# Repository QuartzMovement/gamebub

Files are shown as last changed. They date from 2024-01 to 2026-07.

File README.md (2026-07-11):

<p align="center">
  <a href="https://gamebub.net/">
    Game Bub logo
  </a>
</p>

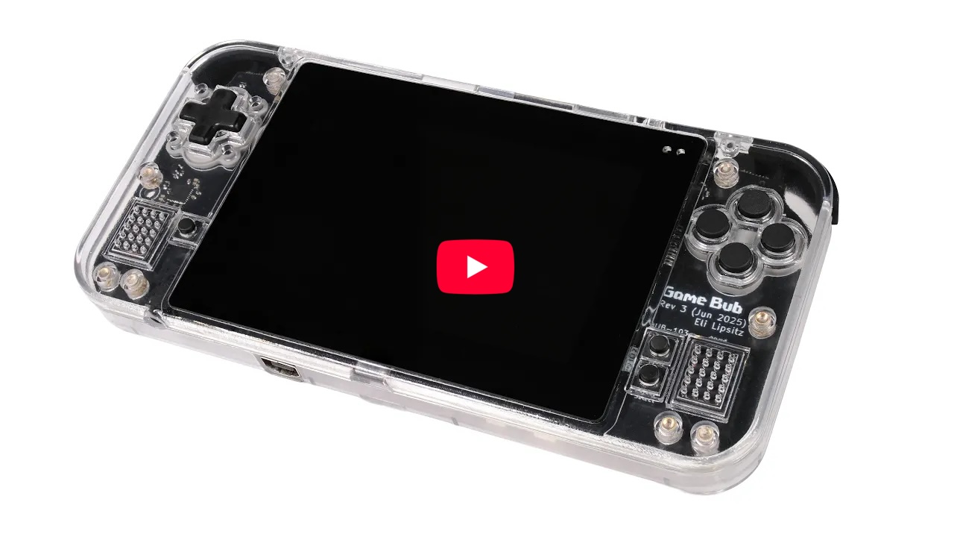
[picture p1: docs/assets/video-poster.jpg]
Game Bub trailer (https://www.youtube.com/watch?v=f16E5J6qljw)


**Game Bub** is an open-source FPGA retro emulation handheld, with support for Game Boy, Game Boy Color, and Game Boy Advance games.

You can buy your own, prebuilt Game Bub from **[Crowd Supply](https://www.crowdsupply.com/second-bedroom/game-bub)**!

You can find the [user guide and documentation here](https://docs.gamebub.net/).

Want to chat about Game Bub? Feel free to [join the Discord](https://discord.gg/T5xrYpMfN7).

Check out the [announcement blog post](https://eli.lipsitz.net/posts/introducing-gamebub/) for an in-depth look at the development process!

## Features
* Play physical Game Boy / Color / Advance cartridges
* Load and play ROM files from a microSD card (with built-in support for rumble, clock, accelerometer, gyroscope)
* Multiplayer link cable functionality
* Custom, from-scratch Game Boy and Game Boy Advance FPGA cores with great game compatibility
* 14+ hour battery life 
* Video output to TV or monitor via Game Bub Dock
* Extensible hardware, designed for future improvements

## Building

Building a Game Bub handheld requires manufacturing PCBs, 3D printing the shell and buttons, and assembling components from a variety of sources. For information on manufacturing and assembling your own, see [docs/building.md](docs/building.md).

For other inquiries, contact us at support@gamebub.net.

## Architecture

For an in-depth description of the project architecture, see [docs/architecture.md](docs/architecture.md).

The Game Bub handheld consists of a Xilinx XC7A100T FPGA to do the main emulation and I/O, and an ESP32-S3 microcontroller to do auxiliary tasks (configuring the FPGA, rendering the UI, loading ROM files from a microSD card and sending it to the FPGA).

### Directory Structure

* `fpga`: FPGA source code (HDL), written in [Chisel](https://github.com/chipsalliance/chisel)
* `firmware`: Microcontroller firmware

## License

Unless otherwise specified:

* Firmware (in `firmware/`) and scripts (in `scripts/`) are licensed under GPLv3 (`GPL-3.0-only`).
* FPGA source code (in `fpga/`) is licensed under the CERN Open Hardware License Version 2 - Strongly Reciprocal (`CERN-OHL-S-2.0`)
* PCB (schematic and layout), mechanical, and hardware design files are licensed under the CERN Open Hardware License Version 2 - Strongly Reciprocal (`CERN-OHL-S-2.0`)

At a high level, this means that you can copy, share, and modify the source code, as long as you provide proper attribution and share your source code / design files with the same license. However, the "Game Bub" name and logo are trademarked, and you may not use them for your product without permission.

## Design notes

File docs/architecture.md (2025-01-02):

# Architecture

The physical architecture of the Game Bub handheld is summarized in the following block diagram.

See the [schematic](../pcb/handheld_rev2/handheld.pdf) for more information.

<p align="center">
     
</p>

## Power 

The device is split into three power domains:

* **Always on**: real-time clock, battery charger, battery gauge, and the power switch circuit.
    * `VBATT` (directly from the battery, 3.7V to 4.2V)
    * `VSYS_ALWAYS` (from the BQ24073 charger)
* **MCU**: Powers the MCU, its peripherals, and the display. Pressing the power switch powers on this power domain.
    * `VSYS` (~3.7V to 5.0V), from `VSYS_ALWAYS` through a load switch
    * `+3V3` (3.3V), generated by a TLV62585 buck converter from `VSYS`
* **FPGA**: Controlled by the `FPGA_ENABLE` signal from the MCU. Powers the FPGA and its peripherals. Also powers the DAC digital and analog core voltages (but the IO rails are powered as part of the MCU power domain).
    * `+1V0` (1.0V), generated by a TLV62585 buck converter from `VSYS`
    * `+5V0` (5.0V), generated by a TPS61022 boost converter from `VSYS`
    * `+1V8` (1.8V), generated by a TPS61022 boost converter from `VSYS`
    * `+3V3_FPGA` (3.3V), gated by a load switch from `+3V3`
    * `VGB` (3.3V or 5.0V), muxed from `+3V3_FPGA` or `+5V0` depending on whether there is a Game Boy (5V) or Game Boy Advance (3.3V) cartridge present. This muxing is controlled by the FPGA, and this is used to power the cartridge, link port, and the level shifters.

The FPGA requires careful power sequencing: `FPGA_ENABLE` enables `+1V0` and `+5V0`. `+1V8` is enabled once `+1V0` stabilizes, and `+3V3_FPGA` is enabled once that stabilizes.

## MCU and FPGA Responsibilities

The MCU is responsible for system control: it boots the device and manages the FPGA (power and configuration). It also renders the UI (sending completed frames over the FPGA for display).

The FPGA does all game emulation. It has direct access to the cartridge slot and link ports, and has dedicated memory (32 MiB of SDRAM, 512 KiB of SRAM) to assist with this. It produces audio and sends it to the DAC via I2S, and it has a high-bandwidth 18-bit parallel interface to the display. 

The FPGA also has 4 high-speed differential pairs routed out to the USB-C connector. This is used, with the custom dock in a vendor-specific alt mode, to output HDMI audio and video (directly from the FPGA). 

The high-speed QSPI link between the MCU and the FPGA (4 bit at 40 MHz, 20 MB/sec) is primarily used for control signals (telling the FPGA to play or pause), as well as rendering the UI. The FPGA drives the display, so the MCU has to send its UI through the FPGA.

Additionally, when using an emulated cartridge, the MCU sends the ROM file over to the FPGA to be stored in SDRAM, and periodically sends IMU updates (to emulate cartridges with accelerometers or gyroscopes).

Upon boot, the MCU loads the FPGA bitstream from the microSD card (4-bit SDIO), powers on the FPGA and configures it (using single SPI at 80 MHz). It initializes the display and other peripherals, and renders the initial UI.

## FPGA Structure

The top-level FPGA design is written in SystemVerilog and provides glue code to interface with the outside world, and instantiates the MMCM/PLLs, the HDMI module, and the main `HandheldTop` module, written in Chisel.

The `HandheldTop` module provides functionality common to both the Game Boy and GBA emulators. It instantiates the SPI receiver, MCU interrupt sender, SDRAM and SRAM controller, common configuration registers, the audio output (I2S), and the video output (DPI).

It instantiates the main emulator as a submodule ("inner module"), sending button input, receiving audio and video data (pixel by pixel, sample by sample, as it's generated), and arbitrating RAM access between the inner module and the MCU.

Video data from the inner module is placed into a triple-buffered framebuffer (backed by block RAM). The triple buffering is unfortunately essential because the display is rotated 90 degrees, so there would be diagonal tearing if entire frames were not buffered in memory. This also helps for HDMI output, which has to run at a constant 60 Hz frame rate, compared to the 59.73 Hz that the Game Boy and GBA run at. The UI from the MCU is received as 15-bit RGB (plus one alpha bit) and stored in a single buffer. The two are composited together as video is output.

### Clock Domains

* The "system" clock, which runs at the speed of the inner emulator (~8.39 MHz for Game Boy, ~16.78 MHz for GBA). Most of the logic runs in this clock domain
* The "av" (audio/video) clock, where the audio and video output is generated. This is 12.288 MHz when using the internal display, and 27.027 MHz when HDMI is enabled. HDMI uses a clock 5x faster as well for DDR TMDS encoding.
* The "sdram" clock, which runs at an integer multiple (e.g. 4x) of the "system" clock. This is used to communicate with the SDRAM module, and the integer multiple greatly simplifies clock domain crossing.
* The "spi" clock, which runs at 200 MHz. The SPI deserializer runs in this clock domain, allowing the 40 MHz SPI bus to be 5x oversampled. Read and write commands are deserialized and passed to the system clock domain via an asynchronous FIFO.

## MCU Structure

The MCU firmware is written with Rust, built on top of ESP-IDF with the [esp-idf-hal](https://github.com/esp-rs/esp-idf-hal) crate.

The UI is built with [Slint](https://github.com/slint-ui/slint). There's a single top-level Window, that holds the status bar and a swappable set of "Screen" components. Screens are each user-visible screen, such as the Main Menu, Rom Select, Settings, Tools, and Game screens.

Interrupts (from the FPGA, peripherals, or the button I/O expander) are handled in a dedicated interrupt thread, which sends events to a background "worker" thread. The UI runs on a dedicated "UI" thread, and the worker and UI threads communicate with each other through message passing.

When a game is being played, the Game screen is active. There are separate drivers for each type of bitstream (Game Boy or GBA), which handle loading the bootrom, loading and configuring the emulated cartridge, save files, and sending auxiliary data (e.g. IMU samples).

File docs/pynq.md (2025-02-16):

# Pynq-Z2 Documentation

The first version of this project was intended to be run on a Pynq-Z2 development board. Read the full writeup [here](https://eli.lipsitz.net/posts/fpga-gameboy-emulator/).

This document preserves the original instructions. **Please note, however, that the active branch of this repo no longer contains the Pynq/Zynq related code.** Check out the [`pynq-release` tag](https://github.com/elipsitz/gamebub/tree/pynq-release) for that code.

Currently, only the Pynq-Z2 is supported, although the core of the emulator should be able to be used on any FPGA with sufficient resources.

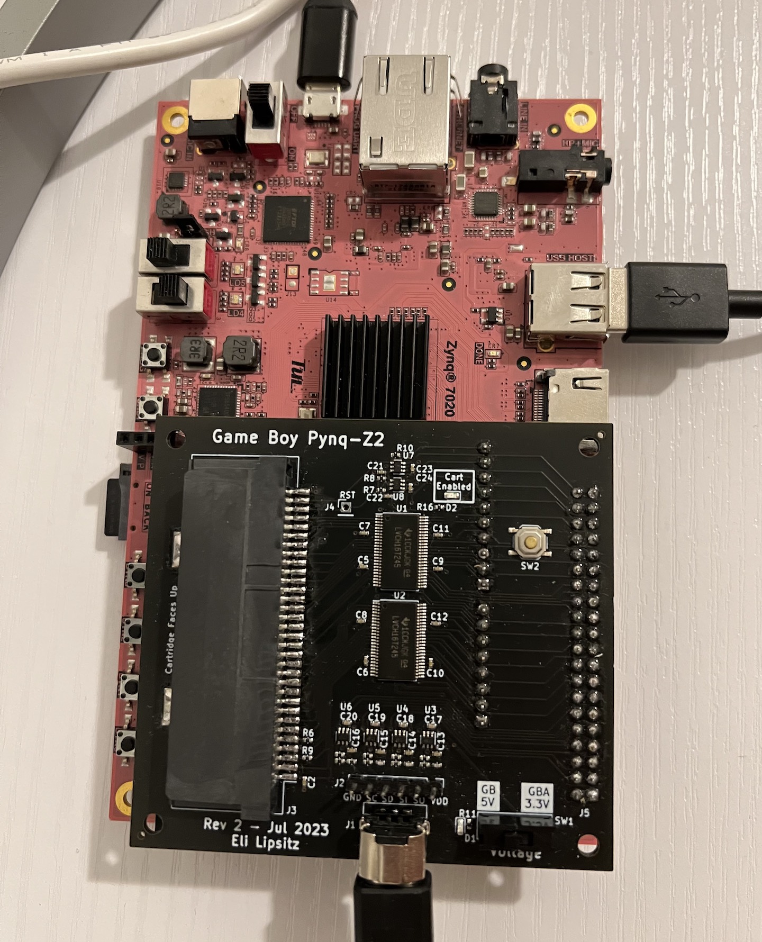
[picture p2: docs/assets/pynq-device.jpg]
 

## Building

A precompiled bitstream is available under Releases.

### Setup

#### Install Vivado

Currently this project uses Vivado 2020.2. The free edition is sufficient. Make sure to install with support for Zynq-7000 SoCs.

Install the [Pynq-Z2 Vivado board files](https://pynq.readthedocs.io/en/latest/overlay_design_methodology/board_settings.html).

Additionally, you should set up a shared IP cache to speed up synthesis of Xilinx IP:
1. Create the `~/vivado_ip_cache` directory (could be located somewhere else).
2. Create the file `~/.Xilinx/Vivado/Vivado_init.tcl`
3. In that file, add `set_param project.defaultIPCacheSetting /home/eli/vivado_ip_cache/` (substituting the absolute path to the IP cache directory).

#### Install other tools

You'll need to install JDK 8 or later, and [Scala Build Tool (`sbt`)](https://www.scala-sbt.org/download.html). Additionally, install [FuseSoC](https://github.com/olofk/fusesoc).

### Building the bitstream

From the top-level directory:

```
fusesoc --cores-root . run --build --target=pynq_z2 elipsitz:gameboy:gameboy
```

This will generate a `.bit` and `.hwh` file, which need to be accessible to the PS Python code.

## Running

### Setup

Install Pynq Linux on the Pynq-Z2, and install the pip packages listed in `python/requirements.txt`.

Transfer the `gameboy_ps` Python module (located in the `python` directory) to the Pynq-Z2.

Place the `gameboy.bit` and `gameboy.hwh` files from the build process in the `gameboy_ps/resources` directory.

### HDMI and Controller

Connect an HDMI cable from the "HDMI OUT" port on the Pynq-Z2 to a monitor or TV.

Attach an Xbox-compatible controller to the USB port of the Pynq-Z2.

### Running 

As root, run `python3 -m gameboy_ps <path to ROM directory>`, passing the path to the directory containing ROM files.

The program will load the bitstream to the PL. It takes a few seconds to load all of the Pynq libraries, but the main menu should soon show up on the display.

Warning: the audio output can be quite loud. Start at the lowest setting on the monitor/TV and increase it as needed.

## Building the cartridge adapter board

To play physical cartridges, you'll need to assemble the adapter board. KiCad board files can be found in the `pcb/pynq_adapter_rev2` directory. The schematic is pre-populated with LCSC part numbers for easy assembly at JLCPCB.

You'll need to add a few components yourself. These are all easy to solder:

* A 2x20 0.1mm female pin header (e.g. [this one](https://www.adafruit.com/product/2222)). These are used for Raspberry Pi HATs, so they're pretty easy to find.
* A SPDT slide switch such as the [EG1218](https://octopart.com/search?q=EG1218), or just a 1x3 strip of 0.1mm male pin header and a jumper.
* A GBA SP slot (such as [this one](https://handheldlegend.com/products/game-boy-cartridge-slot)). These can be found quite cheaply on eBay or Aliexpress as well. They're all pretty much the same.
* If desired, a GBA link port (e.g. [this one](https://handheldlegend.com/products/game-boy-advance-ext-link-port)). These can also be found easily from other sources.

The other parts are relatively small, so I don't recommend hand soldering the board. However, if you want to assemble the whole thing yourself, in addition to assorted resistors and capacitors, you'll also need:

* 6x [74LVC1T45DCK](https://octopart.com/search?q=74LVC1T45DCK) 1-bit level shifters.
* 2x [74LVCH16T245DGGR](https://octopart.com/search?q=74LVCH16T245DGGR) 16-bit level shifters. The non 'H' version should work as well, but the 'H' (bus hold) version is preferable.

## Appendix

### Getting Xbox controller to work on Pynq-Z2

This needs the `xpad` and `joydev` drivers. Pynq Linux isn't built with them. If you're running Pynq Linux with kernel `5.15.19-xilinx-v2022.1`, prebuilt kernel modules can be found in the [`pynq-release` release on GitHub](https://github.com/elipsitz/gamebub/releases/tag/pynq-release). Otherwise, to build loadable kernel modules from scratch:

On the Pynq-Z2, go to `/lib/modules/5.15.19-xilinx-v2022.1/build`.

Download the right version of [`xpad.c`](https://raw.githubusercontent.com/torvalds/linux/v5.15/drivers/input/joystick/xpad.c)
to `drivers/input/joystick/xpad.c`.

And do the same with [`joydev.c`](https://raw.githubusercontent.com/torvalds/linux/v5.15/drivers/input/joydev.c), to `drivers/input/joydev.c`.

The build commands in `/lib/modules` need to run with `sudo` due to permissions issues.

Do `sudo make menuconfig` and set:

* `Device Drivers --> Input device support --> Joystick interface` to `M` (for 'module')
* `Device Drivers --> Input device support --> Joysticks/gamepads --> X-box Gamepad support` to `M` (for 'module')

Save and exit.

Then build the modules:

```
sudo make scripts
sudo make distclean
sudo make prepare
sudo make modules_prepare

sudo make -C . M=drivers/input/ joydev.ko
sudo make -C . M=drivers/input/joystick xpad.ko
```

Install the modules so that they'll be loaded automatically on boot.
Copy the `.ko` files to `/usr/lib/modules/$(uname -r)/kernel/`, and append
to `/etc/modules`:

```
joydev
xpad
```

Alternatively, use `insmod <modules>.ko` to load them once.

Make sure the `xilinx` user is in the group `input`:
`sudo usermod -a -G input xilinx` (and re-login)

Install the Python library with `sudo pip3 install xbox360controller`

Create the device nodes if needed: https://docs.kernel.org/input/joydev/joystick.html#device-nodes

```
cd /dev
rm js*
mkdir input
mknod input/js0 c 13 0
mknod input/js1 c 13 1
mknod input/js2 c 13 2
mknod input/js3 c 13 3
ln -s input/js0 js0
ln -s input/js1 js1
ln -s input/js2 js2
ln -s input/js3 js3
```

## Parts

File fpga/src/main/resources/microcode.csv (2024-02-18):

Label | Comment | Encoding | PcNext | IME | RegRead1Sel | RegRead2Sel | RegWriteSel | RegOp | IncOp | IncReg | AluOp | AluSelA | AluSelB | AluFlagSet | MemEn | MemWr | MemAddrSel | MicroBranch | NextState
NOP |  | 00000000 | - | = | - | - | - | None | - | - | - | - | - | No | - | - | - | Fetch | -
_INVALID |  |  | Same | = | - | - | - | None | No | - | - | - | - | No | No | - | - | Jump | _INVALID
HALT |  | 01110110 | Same | = | - | - | - | None | No | - | - | - | - | No | No | - | - | Jump | HALT
STOP |  | 00010000 | IncOut | = | - | - | - | None | Inc | PC | - | - | - | No | No | - | - | Next | -
#STOP_loop |  |  | Same | = | - | - | - | None | No | - | - | - | - | No | No | - | - | Jump | #STOP_loop
LD r, (HL) |  | 01???110 | Same | = | - | - | Reg8Dest | WriteMem | No | HL | - | - | - | No | Yes | No | Incrementer | Jump | NOP
LD (HL), r |  | 01110??? | Same | = | - | Reg8Src | - | None | No | HL | CopyB | - | Reg2 | No | Yes | Yes | Incrementer | Jump | NOP
LD (HL),n |  | 00110110 | IncOut | = | - | - | W | WriteMem | Inc | PC | - | - | - | No | Yes | No | Incrementer | Next | -
 |  |  | Same | = | - | W | - | None | No | HL | CopyB | - | Reg2 | No | Yes | Yes | Incrementer | Jump | NOP
LD r,r |  | 01?????? | - | = | - | Reg8Src | Reg8Dest | WriteAlu | - | - | CopyB | - | Reg2 | No | - | - | - | Fetch | -
LD r,n |  | 00???110 | IncOut | = | - | - | Reg8Dest | WriteMem | Inc | PC | - | - | - | No | Yes | No | Incrementer | Jump | NOP
LD rr,nn |  | 00??0001 | IncOut | = | - | - | Reg16Lo | WriteMem | Inc | PC | - | - | - | No | Yes | No | Incrementer | Next | -
 |  |  | IncOut | = | - | - | Reg16Hi | WriteMem | Inc | PC | - | - | - | No | Yes | No | Incrementer | Jump | NOP
ldi (HL),A |  | 00100010 | Same | = | - | - | - | None | Inc | HL | CopyA | A | - | No | Yes | Yes | Incrementer | Jump | NOP
ldi A,(HL) |  | 00101010 | Same | = | - | - | A | WriteMem | Inc | HL | - | - | - | No | Yes | No | Incrementer | Jump | NOP
ldd (HL),A |  | 00110010 | Same | = | - | - | - | None | Dec | HL | CopyA | A | - | No | Yes | Yes | Incrementer | Jump | NOP
ldd A,(HL) |  | 00111010 | Same | = | - | - | A | WriteMem | Dec | HL | - | - | - | No | Yes | No | Incrementer | Jump | NOP
ALU A, n |  | 11???110 | IncOut | = | - | - | W | WriteMem | Inc | PC | - | - | - | No | Yes | No | Incrementer | Next | -
 |  |  | - | = | - | W | A | WriteAlu | - | - | InstAlu | A | Reg2 | All | - | - | - | Fetch | -
ALU A, (HL) |  | 10???110 | Same | = | - | - | W | WriteMem | No | HL | - | - | - | No | Yes | No | Incrementer | Next | -
 |  |  | - | = | - | W | A | WriteAlu | - | - | InstAlu | A | Reg2 | All | - | - | - | Fetch | -
ALU A, r |  | 10?????? | - | = | - | Reg8Src | A | WriteAlu | - | - | InstAlu | A | Reg2 | All | - | - | - | Fetch | -
JP nn | little endian address | 11000011 | IncOut | = | - | - | Z | WriteMem | Inc | PC | - | - | - | No | Yes | No | Incrementer | Next | -
 |  |  | IncOut | = | - | - | W | WriteMem | Inc | PC | - | - | - | No | Yes | No | Incrementer | Next | -
#PC=WZ |  |  | IncOut | = | - | - | - | None | No | WZ | - | - | - | No | No | - | - | Jump | NOP
JP HL |  | 11101001 | IncOut | = | - | - | - | None | IncNoWrite | HL | - | - | - | No | - | - | Incrementer | Fetch* | -
JP f,nn | Conditional | 110??010 | IncOut | = | - | - | Z | WriteMem | Inc | PC | - | - | - | No | Yes | No | Incrementer | Next | -
 |  |  | IncOut | = | - | - | W | WriteMem | Inc | PC | - | - | - | No | Yes | No | Incrementer | Cond | #PC=WZ
 |  |  | - | = | - | - | - | None | - | - | - | - | - | No | - | - | - | Fetch | -
LD (rr), A |  | 00??0010 | Same | = | - | - | - | None | No | Inst16 | CopyA | A | - | No | Yes | Yes | Incrementer | Jump | NOP
LD A, (rr) |  | 00??1010 | Same | = | - | - | A | WriteMem | No | Inst16 | - | - | - | No | Yes | No | Incrementer | Jump | NOP
LD (nn), A |  | 11101010 | IncOut | = | - | - | Z | WriteMem | Inc | PC | - | - | - | No | Yes | No | Incrementer | Next | -
 |  |  | IncOut | = | - | - | W | WriteMem | Inc | PC | - | - | - | No | Yes | No | Incrementer | Next | -
 |  |  | Same | = | - | - | - | None | No | WZ | CopyA | A | - | No | Yes | Yes | Incrementer | Jump | NOP
LD A, (nn) |  | 11111010 | IncOut | = | - | - | Z | WriteMem | Inc | PC | - | - | - | No | Yes | No | Incrementer | Next | -
 |  |  | IncOut | = | - | - | W | WriteMem | Inc | PC | - | - | - | No | Yes | No | Incrementer | Next | -
 |  |  | Same | = | - | - | A | WriteMem | No | WZ | - | - | - | No | Yes | No | Incrementer | Jump | NOP
LD (FF00 + n), A |  | 11100000 | IncOut | = | - | - | W | WriteMem | Inc | PC | - | - | - | No | Yes | No | Incrementer | Next | -
 |  |  | Same | = | - | W | - | None | No | - | CopyA | A | - | No | Yes | Yes | High | Jump | NOP
LD (FF00 + C), A |  | 11100010 | Same | = | - | C | - | None | No | - | CopyA | A | - | No | Yes | Yes | High | Jump | NOP
LD A, (FF00 + n) |  | 11110000 | IncOut | = | - | - | W | WriteMem | Inc | PC | - | - | - | No | Yes | No | Incrementer | Next | -
 |  |  | Same | = | - | W | A | WriteMem | No | - | - | - | - | No | Yes | No | High | Jump | NOP
LD A, (FF00 + C) |  | 11110010 | Same | = | - | C | A | WriteMem | No | - | - | - | - | No | Yes | No | High | Jump | NOP
INC rr |  | 00??0011 | Same | = | - | - | - | None | Inc | Inst16 | - | - | - | No | No | - | - | Jump | NOP
DEC rr |  | 00??1011 | Same | = | - | - | - | None | Dec | Inst16 | - | - | - | No | No | - | - | Jump | NOP
LD (nn), SP |  | 00001000 | IncOut | = | - | - | Z | WriteMem | Inc | PC | - | - | - | No | Yes | No | Incrementer | Next | -
 |  |  | IncOut | = | - | - | W | WriteMem | Inc | PC | - | - | - | No | Yes | No | Incrementer | Next | -
 |  |  | Same | = | - | SP_Lo | - | None | Inc | WZ | CopyB | - | Reg2 | No | Yes | Yes | Incrementer | Next | -
 |  |  | Same | = | - | SP_Hi | - | None | Inc | WZ | CopyB | - | Reg2 | No | Yes | Yes | Incrementer | Jump | NOP
LD SP, HL |  | 11111001 | Same | = | - | L | SP_Lo | WriteAlu | No | - | CopyB | - | Reg2 | No | No | - | - | Next | -
 |  |  | - | = | - | H | SP_Hi | WriteAlu | - | - | CopyB | - | Reg2 | No | - | - | - | Fetch | -
PUSH AF |  | 11110101 | Same | = | - | - | - | None | Dec | SP | - | - | - | No | No | No | - | Next | -
 |  |  | Same | = | - | A | - | None | Dec | SP | CopyB | - | Reg2 | No | Yes | Yes | Incrementer | Next | -
 |  |  | Same | = | - | F | - | None | No | SP | CopyB | - | Reg2 | No | Yes | Yes | Incrementer | Jump | NOP
POP AF |  | 11110001 | Same | = | - | - | F | WriteMem | Inc | SP | CopyB | - | Reg2 | No | Yes | No | Incrementer | Next | -
 |  |  | Same | = | - | - | A | WriteMem | Inc | SP | CopyB | - | Reg2 | No | Yes | No | Incrementer | Jump | NOP
PUSH rr |  | 11??0101 | Same | = | - | - | - | None | Dec | SP | - | - | - | No | No | No | - | Next | -
 |  |  | Same | = | - | Reg16Hi | - | None | Dec | SP | CopyB | - | Reg2 | No | Yes | Yes | Incrementer | Next | -
 |  |  | Same | = | - | Reg16Lo | - | None | No | SP | CopyB | - | Reg2 | No | Yes | Yes | Incrementer | Jump | NOP
POP rr |  | 11??0001 | Same | = | - | - | Reg16Lo | WriteMem | Inc | SP | - | - | - | No | Yes | No | Incrementer | Next | -
 |  |  | Same | = | - | - | Reg16Hi | WriteMem | Inc | SP | - | - | - | No | Yes | No | Incrementer | Jump | NOP
ADD HL,rr | 16-bit add | 00??1001 | Same | = | L | Reg16Lo | L | WriteAlu | No | - | AddLo | Reg1 | Reg2 | No | No | - | - | Next | -
 |  |  | - | = | H | Reg16Hi | H | WriteAlu | - | - | AddHi | Reg1 | Reg2 | -*** | - | - | - | Fetch | -
ADD SP,dd |  | 11101000 | IncOut | = | - | - | W | WriteMem | Inc | PC | - | - | - | No | Yes | No | Incrementer | Next | -
 |  |  | Same | = | SP_Lo | W | SP_Lo | WriteAlu | No | - | AddLo | Reg1 | Reg2 | 0*** | No | - | - | Next | -
 |  |  | Same | = | SP_Hi | W | SP_Hi | WriteAlu | No | - | AddHi | Reg1 | SignReg2 | No | No | - | - | Jump | NOP
ld HL,SP+dd |  | 11111000 | IncOut | = | - | - | W | WriteMem | Inc | PC | - | - | - | No | Yes | No | Incrementer | Next | -
 |  |  | Same | = | SP_Lo | W | L | WriteAlu | No | - | AddLo | Reg1 | Reg2 | 0*** | No | - | - | Next | -
 |  |  | - | = | SP_Hi | W | H | WriteAlu | - | - | AddHi | Reg1 | SignReg2 | No | - | - | - | Fetch | -
JR e |  | 00011000 | IncOut | = | - | - | W | WriteMem | Inc | PC | - | - | - | No | Yes | No | Incrementer | Next | -
#PC+=W |  |  | Same | = | PC_Lo | W | PC_Lo | WriteAlu | No | - | AddLo | Reg1 | Reg2 | No | No | - | - | Next | -
 | Mem MemAddr to be the new PC, and need to increment PC |  | IncOut | = | PC_Hi | W | PC_Hi | WriteAlu | IncNoWrite | PC_ALU | AddHi | Reg1 | SignReg2 | No | Yes | No | Incrementer | Fetch* | -
JR c,e | Conditional | 001??000 | IncOut | = | - | - | W | WriteMem | Inc | PC | - | - | - | No | Yes | No | Incrementer | Cond | #PC+=W
 |  |  | - | = | - | - | - | None | - | - | - | - | - | No | - | - | - | Fetch | -
CALL nn |  | 11001101 | IncOut | = | - | - | Z | WriteMem | Inc | PC | - | - | - | No | Yes | No | Incrementer | Next | -
 |  |  | IncOut | = | - | - | W | WriteMem | Inc | PC | - | - | - | No | Yes | No | Incrementer | Next | -
#CALL_end |  |  | Same | = | - | - | - | None | Dec | SP | - | - | - | No | No | No | - | Next | -
 |  |  | Same | = | - | PC_Hi | - | None | Dec | SP | CopyB | - | Reg2 | No | Yes | Yes | Incrementer | Next | -
 |  |  | Same | = | - | PC_Lo | - | None | No | SP | CopyB | - | Reg2 | No | Yes | Yes | Incrementer | Next | -
 |  |  | IncOut | = | - | - | - | None | IncNoWrite | WZ | - | - | - | No | - | - | Incrementer | Fetch* | -
CALL cc, nn | Conditional | 110??100 | IncOut | = | - | - | Z | WriteMem | Inc | PC | - | - | - | No | Yes | No | Incrementer | Next | -
 |  |  | IncOut | = | - | - | W | WriteMem | Inc | PC | - | - | - | No | Yes | No | Incrementer | Cond | #CALL_end
 |  |  | - | = | - | - | - | None | - | - | - | - | - | No | - | - | - | Fetch | -
RET |  | 11001001 | Same | = | - | - | PC_Lo | WriteMem | Inc | SP | - | - | - | No | Yes | No | Incrementer | Next | -
 |  |  | Same | = | - | - | PC_Hi | WriteMem | Inc | SP | - | - | - | No | Yes | No | Incrementer | Next | -
 | Extra NOP |  | Same | = | - | - | - | None | No | - | - | - | - | No | No | - | - | Jump | NOP
RET cc | Conditional | 110??000 | Same | = | - | - | - | None | No | - | - | - | - | No | No | - | - | Cond | RET
 |  |  | - | = | - | - | - | None | - | - | - | - | - | No | - | - | - | Fetch | -
RETI | RET + enable interrupts | 11011001 | Same | = | - | - | PC_Lo | WriteMem | Inc | SP | - | - | - | No | Yes | No | Incrementer | Next | -
 |  |  | Same | = | - | - | PC_Hi | WriteMem | Inc | SP | - | - | - | No | Yes | No | Incrementer | Next | -
 | Extra NOP |  | Same | En | - | - | - | None | No | - | - | - | - | No | No | - | - | Jump | NOP
INC (HL) |  | 00110100 | Same | = | - | - | W | WriteMem | No | HL | - | - | - | No | Yes | No | Incrementer | Next | -
 |  |  | Same | = | - | W | - | None | No | HL | IncB | - | Reg2 | All | Yes | Yes | Incrementer | Jump | NOP
INC r |  | 00???100 | - | = | - | Reg8Dest | Reg8Dest | WriteAlu | - | - | IncB | - | Reg2 | All | - | - | - | Fetch | -
DEC (HL) |  | 00110101 | Same | = | - | - | W | WriteMem | No | HL | - | - | - | No | Yes | No | Incrementer | Next | -
 |  |  | Same | = | - | W | - | None | No | HL | DecB | - | Reg2 | All | Yes | Yes | Incrementer | Jump | NOP
DEC r |  | 00???101 | - | = | - | Reg8Dest | Reg8Dest | WriteAlu | - | - | DecB | - | Reg2 | All | - | - | - | Fetch | -
ALU unary | accumulator/flag ops | 00???111 | - | = | - | - | A | WriteAlu | - | - | InstAcc | A | Reg2 | All | - | - | - | Fetch | -
CB_PREFIX | CB prefix | 11001011 | IncOut | = | - | - | - | None | Inc | PC | - | - | - | No | Yes | No | Incrementer | DispatchCB | -
CB_ALU (HL) | CB shift / rotates | CB_00???110 | Same | = | - | - | W | WriteMem | No | HL | - | - | - | No | Yes | No | Incrementer | Next | -
 |  |  | Same | = | - | W | - | None | No | HL | InstCB | - | Reg2 | All | Yes | Yes | Incrementer | Jump | NOP
CB_ALU r | CB shift / rotates | CB_00?????? | - | = | - | Reg8Src | Reg8Src | WriteAlu | - | - | InstCB | - | Reg2 | All | - | - | - | Fetch | -
BIT (HL) | No (HL) writeback | CB_01???110 | Same | = | - | - | W | WriteMem | No | HL | - | - | - | No | Yes | No | Incrementer | Next | -
 |  |  | - | = | - | W | - | None | - | - | InstBit | - | Reg2 | All | - | - | - | Fetch | -
CB_BIT (HL) |  | CB_?????110 | Same | = | - | - | W | WriteMem | No | HL | - | - | - | No | Yes | No | Incrementer | Next | -
 |  |  | Same | = | - | W | - | None | No | HL | InstBit | - | Reg2 | All | Yes | Yes | Incrementer | Jump | NOP
CB_BIT r |  | CB_???????? | - | = | - | Reg8Src | Reg8Src | WriteAlu | - | - | InstBit | - | Reg2 | All | - | - | - | Fetch | -
EI | Enable interrupts | 11111011 | - | En | - | - | - | None | - | - | - | - | - | No | - | - | - | Fetch | -
DI | Disable interrupts | 11110011 | - | Dis | - | - | - | None | - | - | - | - | - | No | - | - | - | Fetch | -
RST vec |  | 11???111 | Same | = | - | - | - | None | Dec | SP | - | - | - | No | No | No | - | Next | -
 |  |  | Same | = | - | PC_Hi | - | None | Dec | SP | CopyB | - | Reg2 | No | Yes | Yes | Incrementer | Next | -
 |  |  | RstAddr | = | - | PC_Lo | - | None | No | SP | CopyB | - | Reg2 | No | Yes | Yes | Incrementer | Jump | NOP
#Interrupt | decrement PC |  | IncOut | Dis | - | - | - | None | Dec | PC | - | - | - | No | No | No | - | Next | -
#Interrupt_keepPC | decrement SP |  | Same | Dis | - | - | - | None | Dec | SP | - | - | - | No | No | No | - | Next | -
 | push PC hi |  | Same | = | - | PC_Hi | - | None | Dec | SP | CopyB | - | Reg2 | No | Yes | Yes | Incrementer | Next | -
 | push PC, jump |  | Interrupt | = | - | PC_Lo | - | None | No | SP | CopyB | - | Reg2 | No | Yes | Yes | Incrementer | Jump | NOP

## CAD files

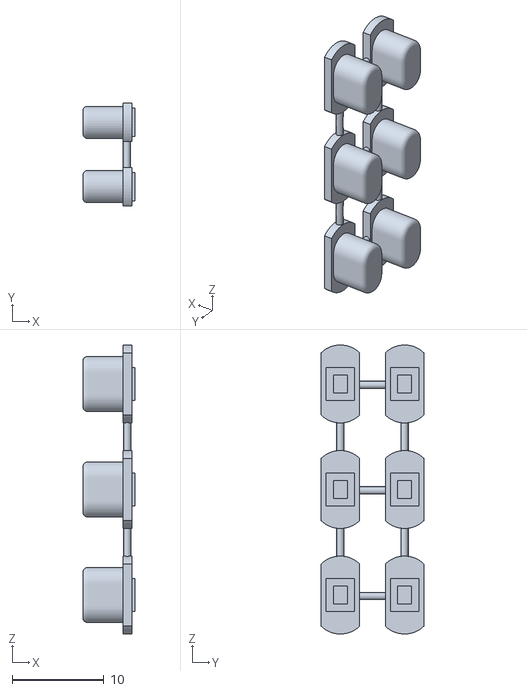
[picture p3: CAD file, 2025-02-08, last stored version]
3d/handheld_rev2/SideButtonArray.stl
5.70 x 11.2 x 31.5

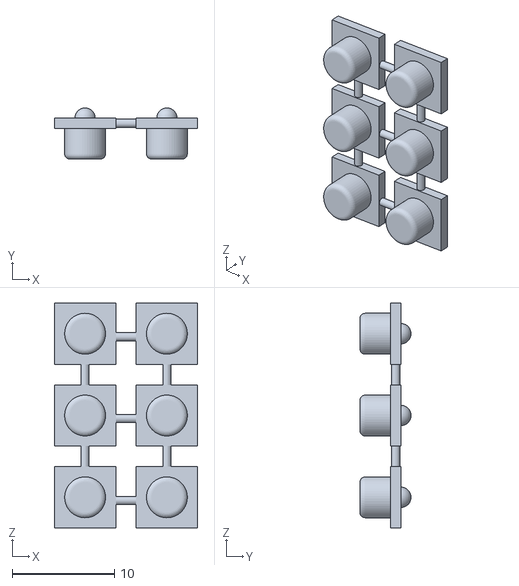
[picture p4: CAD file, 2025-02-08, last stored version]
3d/handheld_rev2/ExtButtonArray.stl
14.0 x 5.00 x 22.0

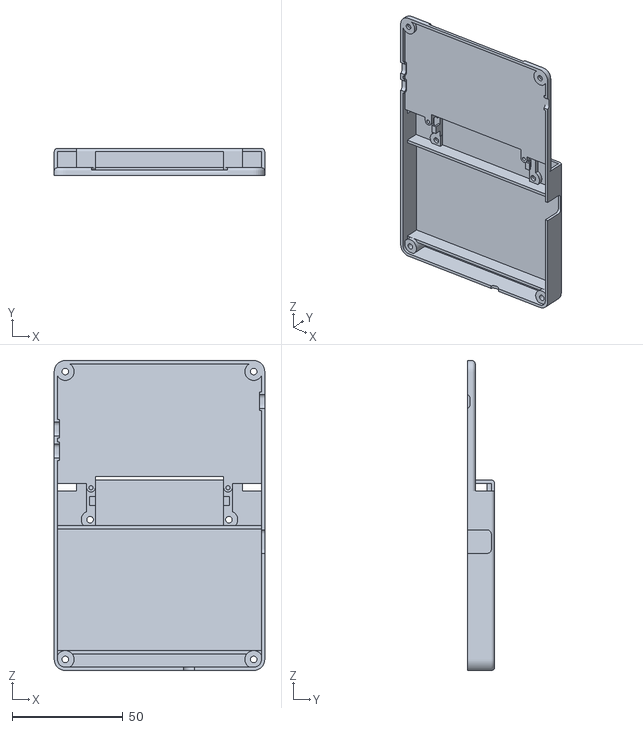
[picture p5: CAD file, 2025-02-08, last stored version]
3d/handheld_rev2/Rear.stl
95.1 x 12.4 x 140.0

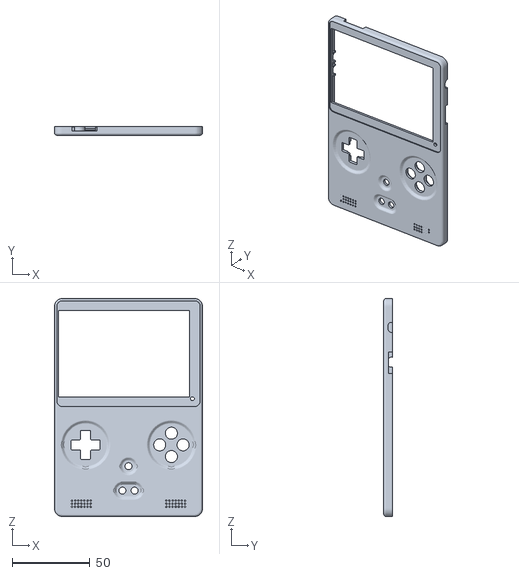
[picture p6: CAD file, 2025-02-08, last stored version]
3d/handheld_rev2/Front.stl
95.1 x 5.50 x 140.0

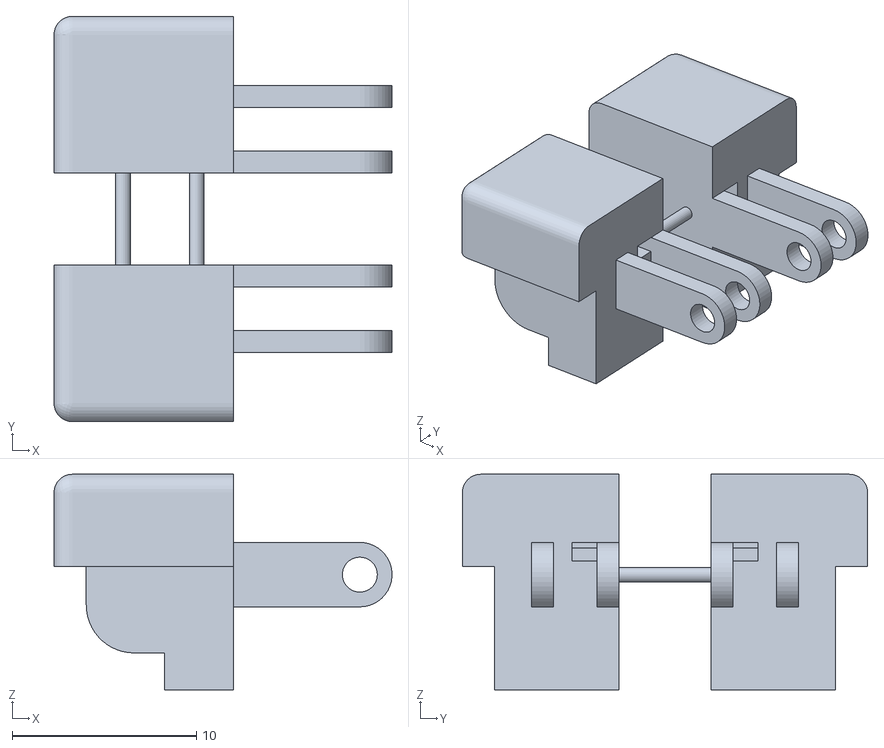
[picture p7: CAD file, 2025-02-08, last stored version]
3d/handheld_rev2/ShoulderButtonArray.stl
18.3 x 22.0 x 11.7

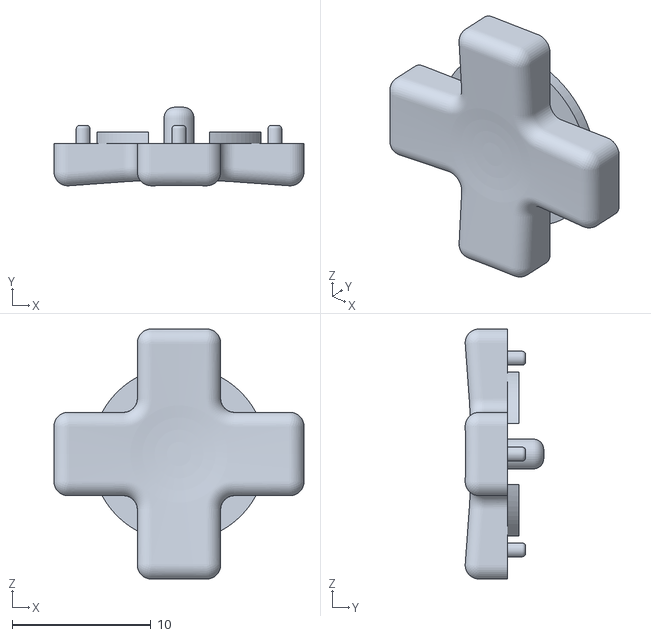
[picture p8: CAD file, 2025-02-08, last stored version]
3d/handheld_rev2/DpadButton.stl
18.0 x 5.66 x 18.0

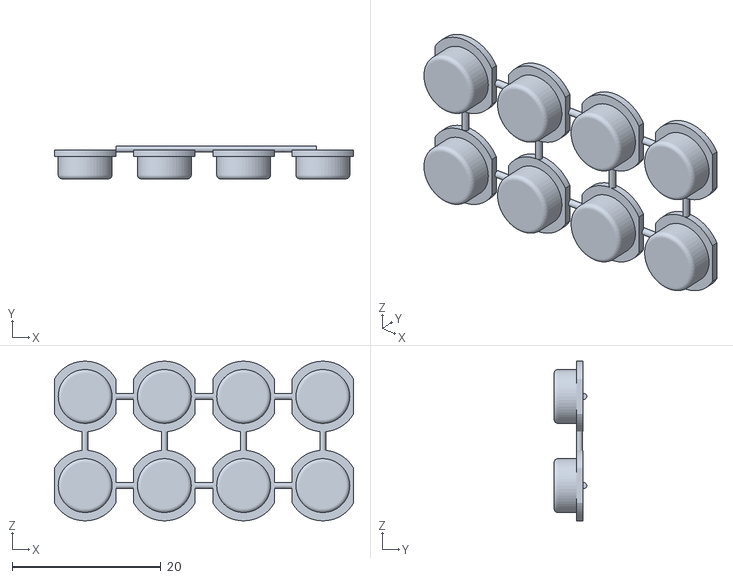
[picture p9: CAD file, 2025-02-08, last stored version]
3d/handheld_rev2/FaceButtonArray.stl
40.3 x 4.40 x 21.5

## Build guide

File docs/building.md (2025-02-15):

# Building

Building a Game Bub unit is a fairly involved process:

1. Manufacturing the PCB
2. Assembling the PCB
3. Printing the shell (and buttons)
4. Assembling the whole device
5. Building the FPGA bitstreams
6. Setting up the microSD card
7. Flashing the MCU firmware

## 1. Manufacturing the PCB

Fab the PCB (in `/pcb/handheld_rev2`) using your manufacturer of choice. The board was initially designed to be fabricated and assembled by JLCPCB.

The board has 6 layers, and rectangular dimensions of 90.1 mm by 135 mm. Due to the fine pitch (0.8mm) BGA FPGA package, the smallest vias are 0.4/0.25mm, with a minimum track width of 0.1mm. The board must have an ENIG finish, as HASL is too uneven for fine-pitch BGA components. 

The board should have a thickness of 1.6mm -- this isn't essential, but the enclosure was designed for this thickness. Only the JLCPCB default 6-layer `JLC06161H-3313` stackup has been tested, but other stackups are likely to work too.

## 2. Assembling the PCB

The board is primarily one-sided, and the vast majority of the components can be machine assembled. The board design files have LCSC component IDs (for easy JLCPCB assembly).

The remaining components are specialty or otherwise difficult to machine assemble:

Front:
* 3.5mm headphone jack: Same Sky SJ-43614-SMT-TR
* Rumble motor: generic 10mm diameter rumble motor
* Optional PMOD connector: 6-pin female 0.1 inch right angle SMD header

Rear:
* Generic GBA cartridge slot
* Generic GBA link port
* Cartridge slot shape detector: JJOV0UL650NONPRBK
* Battery connector: S2B-PH-SM4-TB (or generic 2-pin SMD JST-PH receptacle)
* Shoulder (L and R) buttons: C&K PTS645VN13SMTR92LFS (x2)

Solder each of these components (see the PCB design files if needed).

## 3. Printing the shell

The shell consists of two pieces: the front and rear. Both have a wall thickness of 1.5mm, with some small features of 1.0mm or 0.8mm.

FDM (filament) printing is almost certainly not suitable: this should be printed with a high-precision technology such as SLA (photosensitive resin).

Additionally, all of the buttons are custom and need to be printed as well:
* 4x Large front buttons (A, B, X, and Y)
* D-pad
* 3x Small front buttons (Start, Select, Home)
* 3x Side buttons

## 4. Assembling the whole device

### Parts needed
* ER-TFT035IPS-6 LCD module
* LCD Cover glass (tempered glass or transparent acrylic)
* 2x Speakers (CMS-160903-18S-X8)
* 9x M2.5x4mm heat-set inserts
* CA glue to glue the inserts
* A set of Nintendo DSi button membranes (ABXY and D-pad)
* M2.5 screws:
    * 5x 5mm (three PCB screws, 2 top screws)
    * 4x 14mm (middle and bottom screws)
* A set of torsion springs (1x left, 1x right):
    * Required: >1.5mm interior diameter
    * Suggested: 0.3mm wire diameter, 5 turns, 135 degree angle
* 2x 1.5mm diameter dowel pins, 8mm to 9mm long.
* 755068 size flat Lipo battery with a JST-PH connector (verify polarity)

### Steps
Before assembling, consider testing that the PCB works properly.

1. Attach the LCD cover glass to the front shell with adhesive glue or tape
2. Place the front shell face down on a surface
3. Carefully align and press the LCD module onto the cover glass (ensure flex is facing the correct direction)
4. Glue all 9 heat-set inserts into place, and let the glue harden
5. Insert the speakers into the shell
6. Place the face buttons into the shell, followed by the D-pad and ABXY membranes
7. Open the LCD flex connector on the PCB
8. Carefully set the PCB face down onto the shell, putting the LCD module flex into place on the PCB connector, and close it.
9. Ensure the PCB is aligned well onto the front shell
8. Use the 5mm screws to attach the PCB to the front shell (triangle of screw holes in the middle, towards the bottom half of the PCB). Tighten carefully.
9. Insert the three side buttons into the front shell.
10. Attach the battery to the rear shell with adhesive
11. Assemble the shoulder buttons: align each shoulder button with the rear shell. Place the correct spring in line (inserting one end of the spring into the button), and then insert a dowel pin to hold the assembly together. Hook the other end of the spring into the hook in the rear shell.
12. Plug the battery into the battery connector on the PCB
13. Place the rear shell onto the front shell
14. Use 6 screws (5mm on top, 14mm on the middle and bottom) to close up the shell

## 5. Building the FPGA bitstreams

1. Install Xilinx Vivado 2023.2 with support for Artix-7 devices
2. Install JDK 8 or later, and [Scala Build Tool (`sbt`)](https://www.scala-sbt.org/download.html)
3. Install [FuseSoC](https://github.com/olofk/fusesoc).

From the `/fpga` directory, use FuseSoC to build the bitstreams:

```sh
$ fusesoc --cores-root . --work-root=build/boot --target=handheld_rev2 --flag=boot elipsitz:gameboy:gameboy
$ fusesoc --cores-root . --work-root=build/gameboy --target=handheld_rev2 --flag=gameboy elipsitz:gameboy:gameboy
$ fusesoc --cores-root . --work-root=build/gba --target=handheld_rev2 --flag=gba elipsitz:gameboy:gameboy
```

Save the generated `*.bit` files.

## 6. Setting up the microSD card

Format a good quality microSD card with FAT32, then create the following directory structure:

```
system/
  boot.bit.gz
  gameboy.bit.gz
  gameboy.bios-dmg.bin
  gameboy.bios-cgb.bin
  gba.bit.gz
  gba.bios.bin
roms/
```

* `boot.bit.gz` should be a gzip'd copy of the `boot` bitstream built previously.
* `gameboy.bit.gz` should be a gzip'd copy of the `gameboy` bitstream.
* `gba.bit.gz` should be a gzip'd copy of the `gba` bitstream.
* `gameboy.bios-dmg.bin` and `gameboy.bios-cgb.bin` should be the bootrom files for the original Game Boy and Game Boy Color, or open-source alternatives (e.g. from [SameBoy](https://github.com/LIJI32/SameBoy)).
* `gba.bios.bin` should be the Game Boy Advance bootrom. Either the official one, extracted from a GBA (best compatibility), or a free alternative ([e.g. this one](https://github.com/Cult-of-GBA/BIOS)).
* `roms/` should be a directory containing ROM files (if desired), with `.gb`, `.gbc`, and `.gba` extensions. This directory can be further organized into more directories.

## 7. Flashing the MCU firmware

### Setup

1. Install Rust for ESP32 by [following these instructions (Xtensa targets)](https://docs.esp-rs.org/book/installation/index.html)
2. Install [espflash](https://github.com/esp-rs/espflash)

### Building and installing

Connect the device to your computer with a USB-C cable. Hold the "Home" button (in the center) while turning the device on (by pressing the power button in the top right).

From `/firmware/handheld`, run the following command to build and flash the firmware:

```sh
$ cargo run --release --features=rev2
```

Then, flash the device-specific "factory" data:

```sh
$ python3 flash_nvs.py --serial serialno --revision 2
```

The device should automatically reboot into the main menu.

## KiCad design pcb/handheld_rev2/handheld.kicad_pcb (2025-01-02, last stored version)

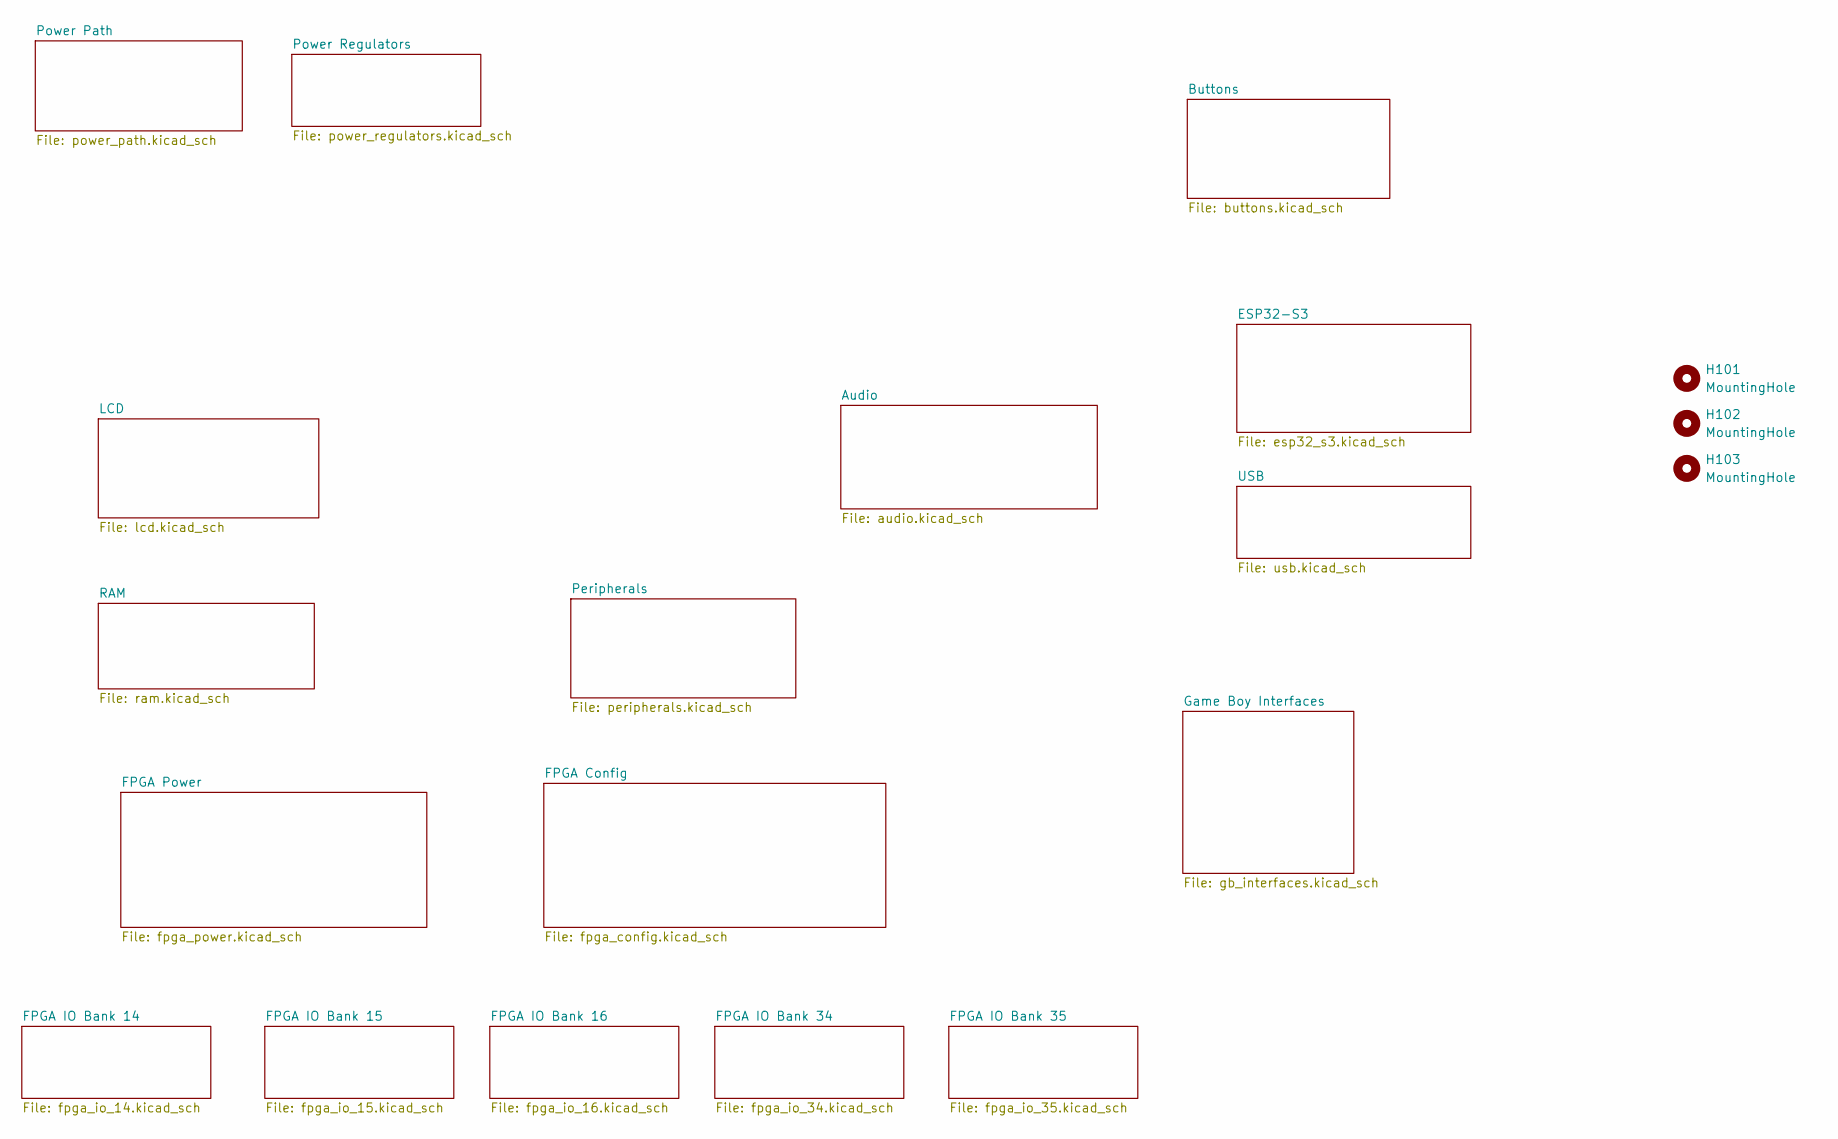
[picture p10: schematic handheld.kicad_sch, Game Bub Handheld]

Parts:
H101, H102, H103: MountingHole; MountingHole_2.7mm_M2.5

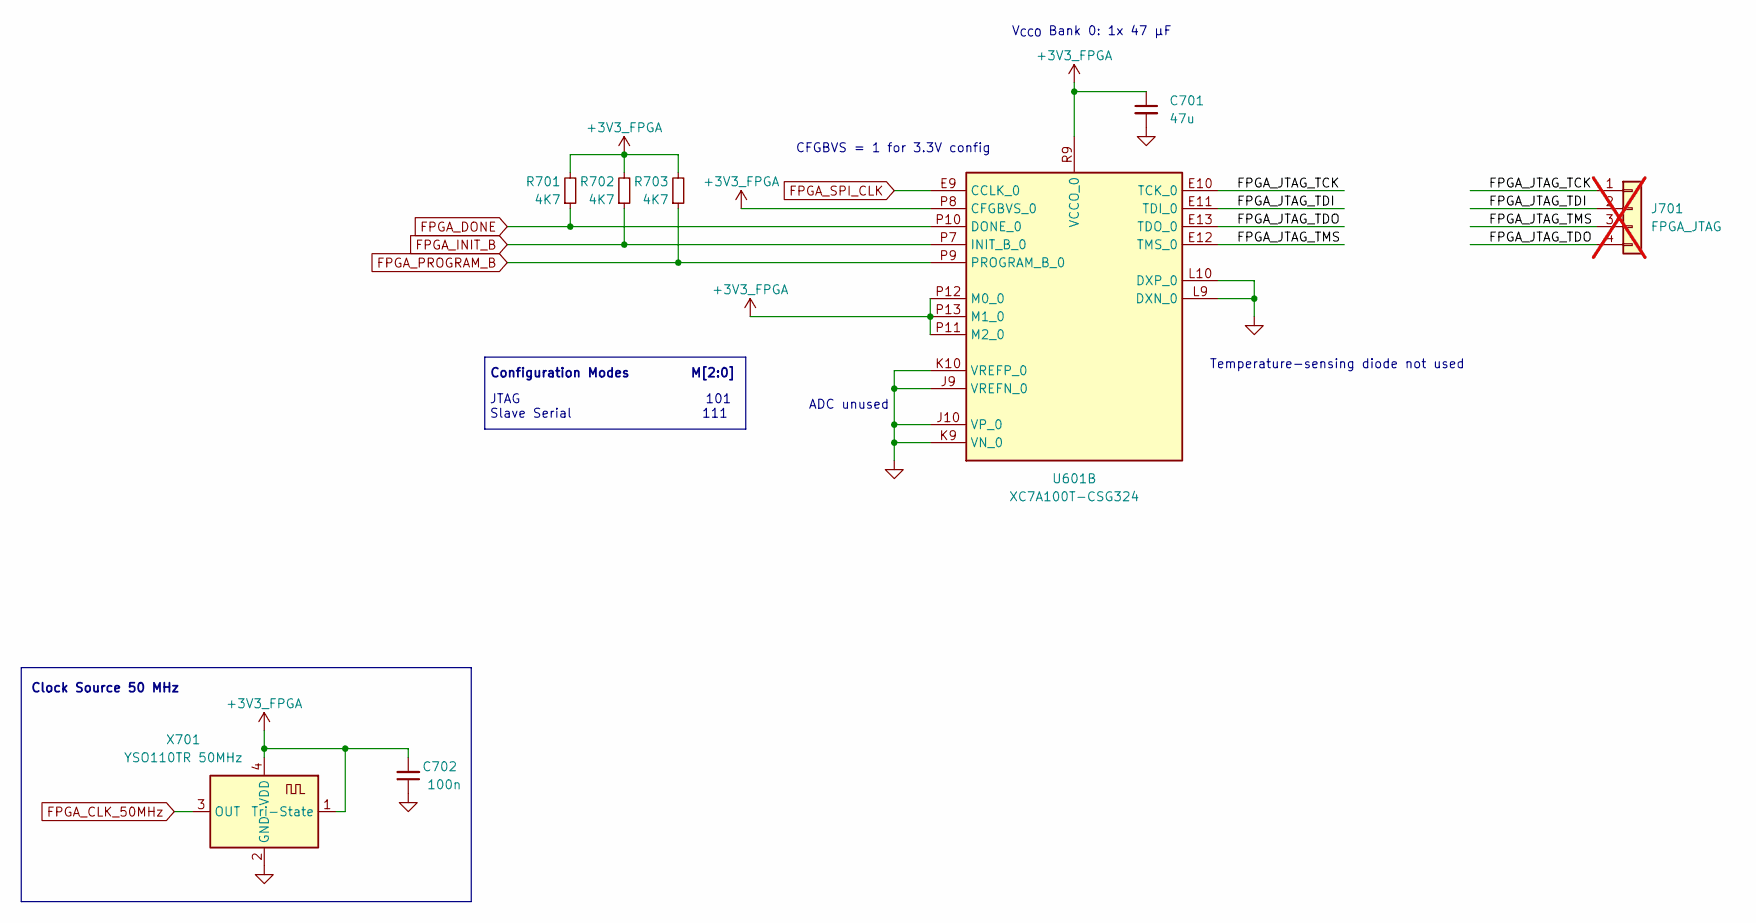
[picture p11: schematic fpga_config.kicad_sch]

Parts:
C701: 47u; C_0805_2012Metric; LCSC C16780
C702: 100n; C_0402_1005Metric; LCSC C1525
J701: FPGA_JTAG; PinSocket_1x04_P2.54mm_Vertical; not fitted
R701, R702, R703: 4K7; R_0402_1005Metric; LCSC C25900
U601: XC7A100T-CSG324; Xilinx_CSG324; LCSC C1521791
X701: YSO110TR 50MHz; Oscillator_SMD_SeikoEpson_SG8002CE-4Pin_3.2x2.5mm; LCSC C5203552

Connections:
+3V3_FPGA: C701.1, C702.2, R701.2, R702.2, R703.2, U601.P8 (CFGBVS_0), U601.P11 (M2_0), U601.P12 (M0_0), U601.P13 (M1_0), U601.R9 (VCCO_0), X701.1 (Tri-State), X701.4 (VDD); also elsewhere on the board
/FPGA Config/FPGA_JTAG_TCK: J701.1, U601.E10 (TCK_0)
/FPGA Config/FPGA_JTAG_TDI: J701.2, U601.E11 (TDI_0)
/FPGA Config/FPGA_JTAG_TDO: J701.4, U601.E13 (TDO_0)
/FPGA Config/FPGA_JTAG_TMS: J701.3, U601.E12 (TMS_0)
FPGA_CLK_50MHz: X701.3 (OUT); also elsewhere on the board
FPGA_DONE: R701.1, U601.P10 (DONE_0); also elsewhere on the board
FPGA_INIT_B: R702.1, U601.P7 (INIT_B_0); also elsewhere on the board
FPGA_PROGRAM_B: R703.1, U601.P9 (PROGRAM_B_0); also elsewhere on the board
FPGA_SPI_CLK: U601.E9 (CCLK_0); also elsewhere on the board
GND: C701.2, C702.1, U601.J9 (VREFN_0), U601.J10 (VP_0), U601.K9 (VN_0), U601.K10 (VREFP_0), U601.L9 (DXN_0), U601.L10 (DXP_0), X701.2 (GND); also elsewhere on the board

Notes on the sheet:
Clock Source 50 MHz
JTAG 101 Slave Serial 111
V_{CCO} Bank 0: 1x 47 µF
ADC unused
CFGBVS = 1 for 3.3V config
Temperature-sensing diode not used
Configuration Modes M[2:0]

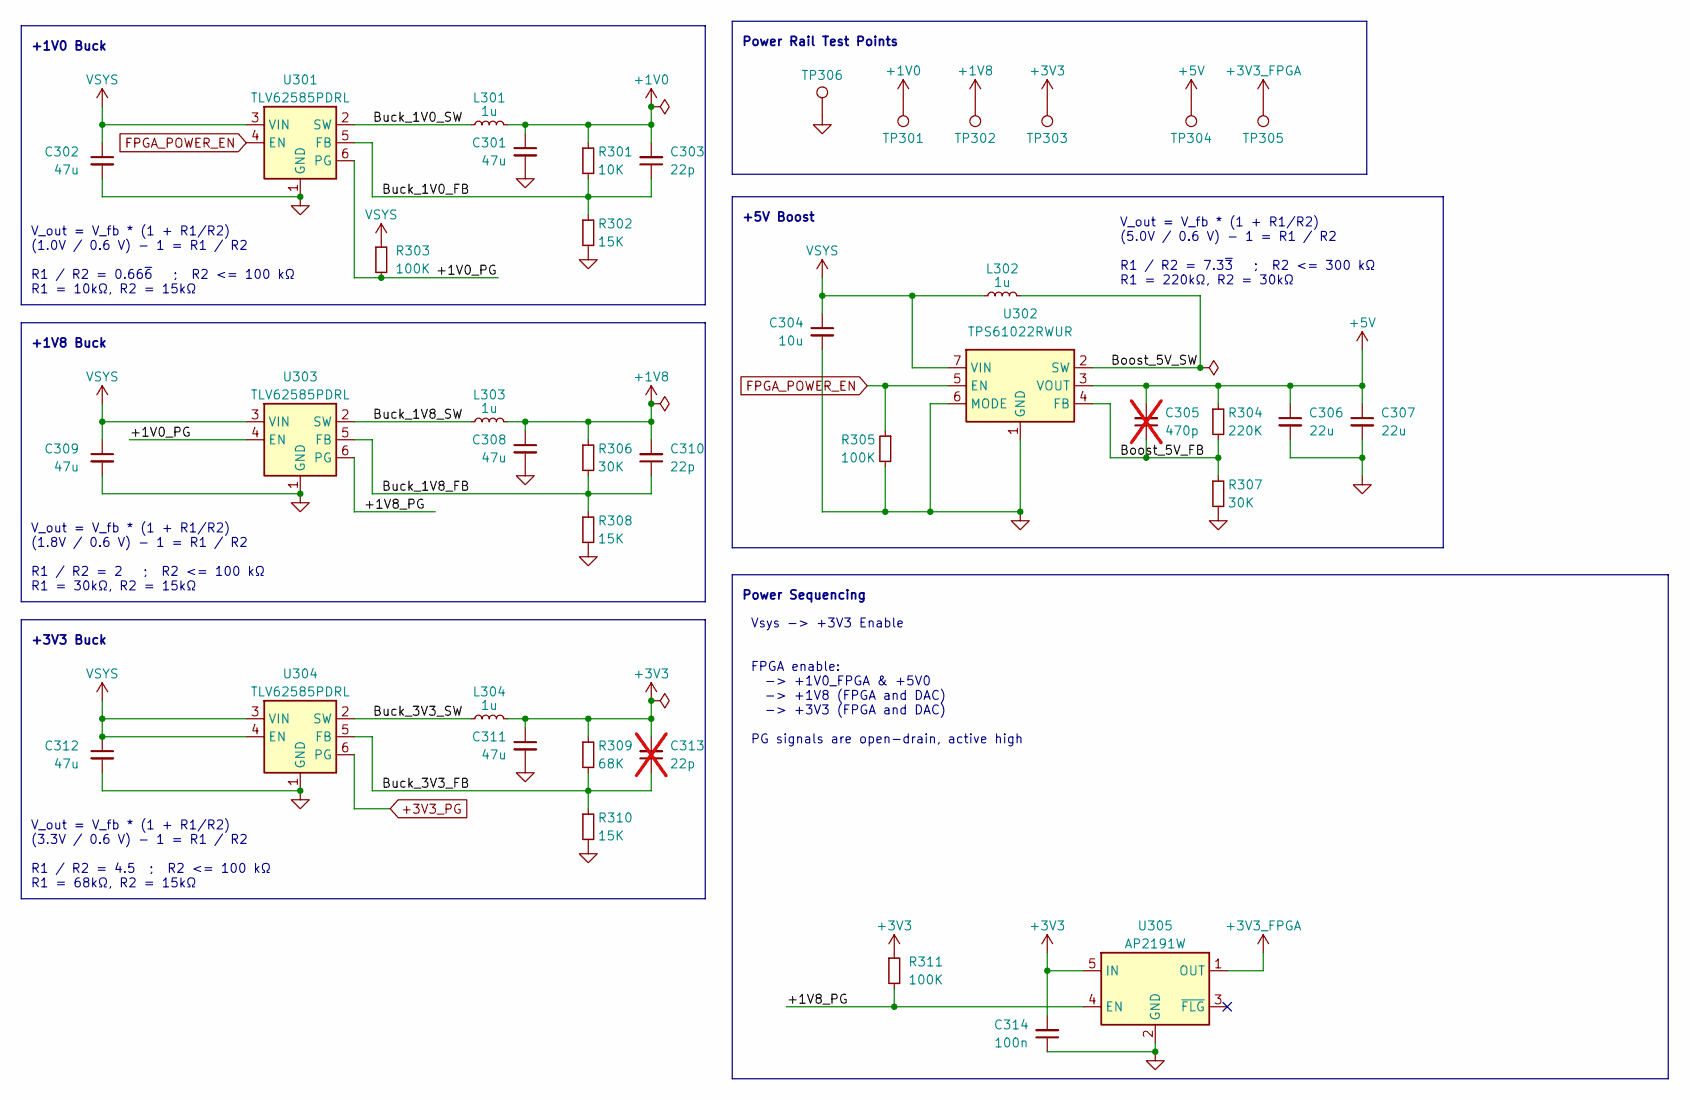
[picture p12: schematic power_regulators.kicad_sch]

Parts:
C301, C302, C308, C309, C311, C312: 47u; C_0805_2012Metric; LCSC C16780
C303, C310: 22p; C_0402_1005Metric; LCSC C1555
C304: 10u; C_0402_1005Metric; LCSC C15525
C305: 470p; C_0402_1005Metric; LCSC C1537; not fitted
C306, C307: 22u; C_0805_2012Metric; LCSC C45783
C313: 22p; C_0402_1005Metric; LCSC C1555; not fitted
C314: 100n; C_0402_1005Metric; LCSC C1525
L301, L302, L303, L304: 1u; L_Sunlord_SWPA252012S; LCSC C98348
R301: 10K; R_0402_1005Metric; LCSC C25744
R302, R308, R310: 15K; R_0402_1005Metric; LCSC C25756
R303, R305, R311: 100K; R_0402_1005Metric; LCSC C25741
R304: 220K; R_0603_1608Metric; LCSC C22961
R306, R307: 30K; R_0402_1005Metric; LCSC C25776
R309: 68K; R_0402_1005Metric; LCSC C36871
TP301: +1V0; TestPoint_2.54mm_THT
TP302: +1V8; TestPoint_2.54mm_THT
TP303: +3V3; TestPoint_2.54mm_THT
TP304: +5V; TestPoint_2.54mm_THT
TP305: +3V3_FPGA; TestPoint_2.54mm_THT
TP306: GND; TestPoint_2.54mm_THT
U301, U303, U304: TLV62585PDRL; SOT-563; LCSC C485118
U302: TPS61022RWUR; VQFN-7_L2.0-W2.0-P0.55-TL_RWU; LCSC C915088
U305: AP2191W; SOT-23-5; LCSC C141321

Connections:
+1V0: C301.1, C303.2, L301.2, R301.1, TP301.1; also elsewhere on the board
+1V8: C308.1, C310.2, L303.2, R306.1, TP302.1; also elsewhere on the board
+3V3: C311.1, C313.2, C314.2, L304.2, R309.1, R311.1, TP303.1, U305.5 (IN); also elsewhere on the board
+3V3_FPGA: TP305.1, U305.1 (OUT); also elsewhere on the board
+3V3_PG: U304.6 (PG); also elsewhere on the board
+5V: C305.2, C306.1, C307.1, R304.1, TP304.1, U302.3 (VOUT); also elsewhere on the board
/Power Regulators/+1V0_PG: R303.2, U301.6 (PG), U303.4 (EN)
/Power Regulators/+1V8_PG: R311.2, U303.6 (PG), U305.4 (EN)
/Power Regulators/Boost_5V_FB: C305.1, R304.2, R307.1, U302.4 (FB)
/Power Regulators/Boost_5V_SW: L302.2, U302.2 (SW)
/Power Regulators/Buck_1V0_FB: C303.1, R301.2, R302.1, U301.5 (FB)
/Power Regulators/Buck_1V0_SW: L301.1, U301.2 (SW)
/Power Regulators/Buck_1V8_FB: C310.1, R306.2, R308.1, U303.5 (FB)
/Power Regulators/Buck_1V8_SW: L303.1, U303.2 (SW)
/Power Regulators/Buck_3V3_FB: C313.1, R309.2, R310.1, U304.5 (FB)
/Power Regulators/Buck_3V3_SW: L304.1, U304.2 (SW)
FPGA_POWER_EN: R305.1, U301.4 (EN), U302.5 (EN); also elsewhere on the board
GND: C301.2, C302.2, C304.2, C306.2, C307.2, C308.2, C309.2, C311.2, C312.2, C314.1, R302.2, R305.2, R307.2, R308.2, R310.2, TP306.1, U301.1 (GND), U302.1 (GND), U302.6 (MODE), U303.1 (GND), U304.1 (GND), U305.2 (GND); also elsewhere on the board
VSYS: C302.1, C304.1, C309.1, C312.1, L302.1, R303.1, U301.3 (VIN), U302.7 (VIN), U303.3 (VIN), U304.3 (VIN), U304.4 (EN); also elsewhere on the board

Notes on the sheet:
+1V8 Buck
V_out = V_fb * (1 + R1/R2) (5.0V / 0.6 V) - 1 = R1 / R2 R1 / R2 = 7.3~{3} ; R2 <= 300 kΩ R1 = 220kΩ, R2 = 30kΩ
V_out = V_fb * (1 + R1/R2) (3.3V / 0.6 V) - 1 = R1 / R2 R1 / R2 = 4.5 ; R2 <= 100 kΩ R1 = 68kΩ, R2 = 15kΩ
+1V0 Buck
V_out = V_fb * (1 + R1/R2) (1.8V / 0.6 V) - 1 = R1 / R2 R1 / R2 = 2 ; R2 <= 100 kΩ R1 = 30kΩ, R2 = 15kΩ
Vsys -> +3V3 Enable FPGA enable: -> +1V0_FPGA & +5V0 -> +1V8 (FPGA and DAC) -> +3V3 (FPGA and DAC) PG signals are open-drain, active high
Power Rail Test Points
Power Sequencing
V_out = V_fb * (1 + R1/R2) (1.0V / 0.6 V) - 1 = R1 / R2 R1 / R2 = 0.66~{6} ; R2 <= 100 kΩ R1 = 10kΩ, R2 = 15kΩ
+3V3 Buck
+5V Boost

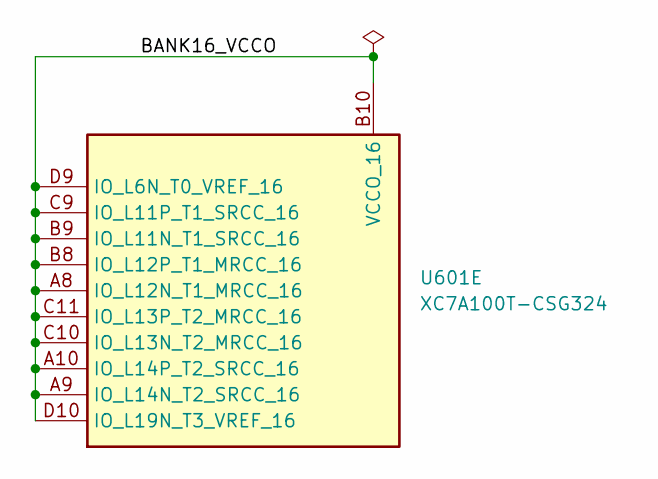
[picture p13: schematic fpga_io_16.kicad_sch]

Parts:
U601: XC7A100T-CSG324; Xilinx_CSG324; LCSC C1521791

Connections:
/FPGA IO Bank 16/BANK16_VCCO: U601.A8 (IO_L12N_T1_MRCC_16), U601.A9 (IO_L14N_T2_SRCC_16), U601.A10 (IO_L14P_T2_SRCC_16), U601.B8 (IO_L12P_T1_MRCC_16), U601.B9 (IO_L11N_T1_SRCC_16), U601.B10 (VCCO_16), U601.C9 (IO_L11P_T1_SRCC_16), U601.C10 (IO_L13N_T2_MRCC_16), U601.C11 (IO_L13P_T2_MRCC_16), U601.D9 (IO_L6N_T0_VREF_16), U601.D10 (IO_L19N_T3_VREF_16)

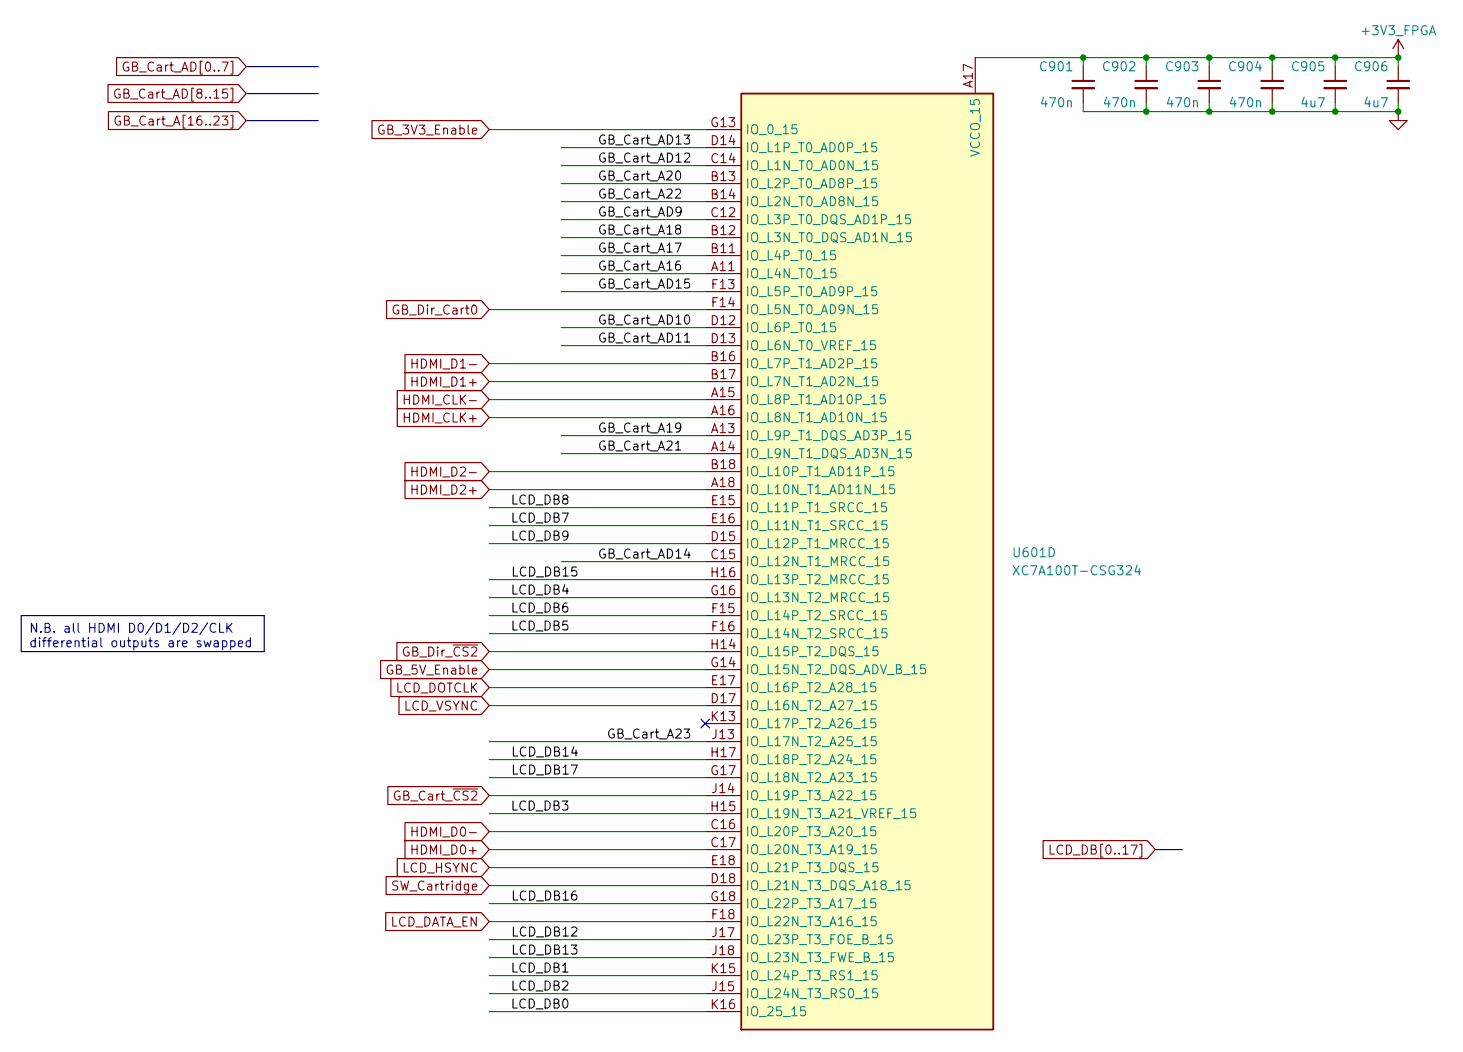
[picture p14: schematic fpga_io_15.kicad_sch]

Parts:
C901, C902, C903, C904: 470n; C_0402_1005Metric; LCSC C47339
C905, C906: 4u7; C_0402_1005Metric; LCSC C23733
U601: XC7A100T-CSG324; Xilinx_CSG324; LCSC C1521791

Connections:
+3V3_FPGA: C901.1, C902.1, C903.1, C904.1, C905.1, C906.1, U601.A17 (VCCO_15), U601.C13 (VCCO_15), U601.D16 (VCCO_15), U601.G15 (VCCO_15), U601.H18 (VCCO_15), U601.K14 (VCCO_15); also elsewhere on the board
GB_3V3_Enable: U601.G13 (IO_0_15); also elsewhere on the board
GB_5V_Enable: U601.G14 (IO_L15N_T2_DQS_ADV_B_15); also elsewhere on the board
GB_Cart_A16: U601.A11 (IO_L4N_T0_15); also elsewhere on the board
GB_Cart_A17: U601.B11 (IO_L4P_T0_15); also elsewhere on the board
GB_Cart_A18: U601.B12 (IO_L3N_T0_DQS_AD1N_15); also elsewhere on the board
GB_Cart_A19: U601.A13 (IO_L9P_T1_DQS_AD3P_15); also elsewhere on the board
GB_Cart_A20: U601.B13 (IO_L2P_T0_AD8P_15); also elsewhere on the board
GB_Cart_A21: U601.A14 (IO_L9N_T1_DQS_AD3N_15); also elsewhere on the board
GB_Cart_A22: U601.B14 (IO_L2N_T0_AD8N_15); also elsewhere on the board
GB_Cart_A23: U601.J13 (IO_L17N_T2_A25_15); also elsewhere on the board
GB_Cart_AD9: U601.C12 (IO_L3P_T0_DQS_AD1P_15); also elsewhere on the board
GB_Cart_AD10: U601.D12 (IO_L6P_T0_15); also elsewhere on the board
GB_Cart_AD11: U601.D13 (IO_L6N_T0_VREF_15); also elsewhere on the board
GB_Cart_AD12: U601.C14 (IO_L1N_T0_AD0N_15); also elsewhere on the board
GB_Cart_AD13: U601.D14 (IO_L1P_T0_AD0P_15); also elsewhere on the board
GB_Cart_AD14: U601.C15 (IO_L12N_T1_MRCC_15); also elsewhere on the board
GB_Cart_AD15: U601.F13 (IO_L5P_T0_AD9P_15); also elsewhere on the board
GB_Cart_~CS2: U601.J14 (IO_L19P_T3_A22_15); also elsewhere on the board
GB_Dir_Cart0: U601.F14 (IO_L5N_T0_AD9N_15); also elsewhere on the board
GB_Dir_~CS2: U601.H14 (IO_L15P_T2_DQS_15); also elsewhere on the board
GND: C901.2, C902.2, C903.2, C904.2, C905.2, C906.2; also elsewhere on the board
HDMI_CLK+: U601.A16 (IO_L8N_T1_AD10N_15); also elsewhere on the board
HDMI_CLK-: U601.A15 (IO_L8P_T1_AD10P_15); also elsewhere on the board
HDMI_D0+: U601.C17 (IO_L20N_T3_A19_15); also elsewhere on the board
HDMI_D0-: U601.C16 (IO_L20P_T3_A20_15); also elsewhere on the board
HDMI_D1+: U601.B17 (IO_L7N_T1_AD2N_15); also elsewhere on the board
HDMI_D1-: U601.B16 (IO_L7P_T1_AD2P_15); also elsewhere on the board
HDMI_D2+: U601.A18 (IO_L10N_T1_AD11N_15); also elsewhere on the board
HDMI_D2-: U601.B18 (IO_L10P_T1_AD11P_15); also elsewhere on the board
LCD_DATA_EN: U601.F18 (IO_L22N_T3_A16_15); also elsewhere on the board
LCD_DB0: U601.K16 (IO_25_15); also elsewhere on the board
LCD_DB1: U601.K15 (IO_L24P_T3_RS1_15); also elsewhere on the board
LCD_DB2: U601.J15 (IO_L24N_T3_RS0_15); also elsewhere on the board
LCD_DB3: U601.H15 (IO_L19N_T3_A21_VREF_15); also elsewhere on the board
LCD_DB4: U601.G16 (IO_L13N_T2_MRCC_15); also elsewhere on the board
LCD_DB5: U601.F16 (IO_L14N_T2_SRCC_15); also elsewhere on the board
LCD_DB6: U601.F15 (IO_L14P_T2_SRCC_15); also elsewhere on the board
LCD_DB7: U601.E16 (IO_L11N_T1_SRCC_15); also elsewhere on the board
LCD_DB8: U601.E15 (IO_L11P_T1_SRCC_15); also elsewhere on the board
LCD_DB9: U601.D15 (IO_L12P_T1_MRCC_15); also elsewhere on the board
LCD_DB12: U601.J17 (IO_L23P_T3_FOE_B_15); also elsewhere on the board
LCD_DB13: U601.J18 (IO_L23N_T3_FWE_B_15); also elsewhere on the board
LCD_DB14: U601.H17 (IO_L18P_T2_A24_15); also elsewhere on the board
LCD_DB15: U601.H16 (IO_L13P_T2_MRCC_15); also elsewhere on the board
LCD_DB16: U601.G18 (IO_L22P_T3_A17_15); also elsewhere on the board
LCD_DB17: U601.G17 (IO_L18N_T2_A23_15); also elsewhere on the board
LCD_DOTCLK: U601.E17 (IO_L16P_T2_A28_15); also elsewhere on the board
LCD_HSYNC: U601.E18 (IO_L21P_T3_DQS_15); also elsewhere on the board
LCD_VSYNC: U601.D17 (IO_L16N_T2_A27_15); also elsewhere on the board
SW_Cartridge: U601.D18 (IO_L21N_T3_DQS_A18_15); also elsewhere on the board

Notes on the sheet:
N.B. all HDMI D0/D1/D2/CLK differential outputs are swapped

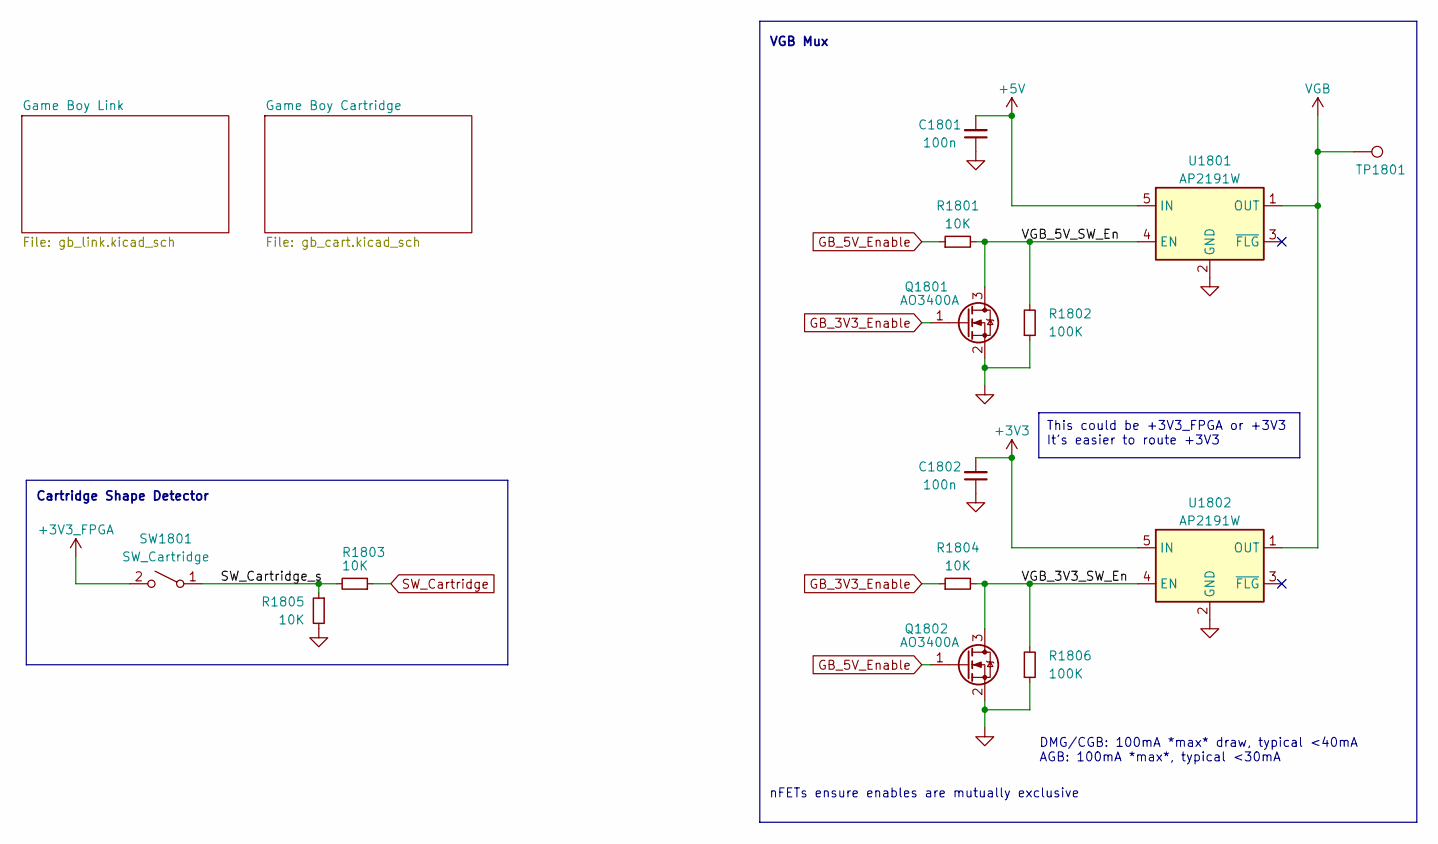
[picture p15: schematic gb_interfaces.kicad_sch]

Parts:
C1801, C1802: 100n; C_0402_1005Metric; LCSC C1525
Q1801, Q1802: AO3400A; SOT-23; LCSC C20917
R1801, R1803, R1804, R1805: 10K; R_0402_1005Metric; LCSC C25744
R1802, R1806: 100K; R_0402_1005Metric; LCSC C25741
SW1801: SW_Cartridge; JJOV0UL650NONPRBK_SIDE
TP1801: VGB; TestPoint_2.54mm_THT
U1801, U1802: AP2191W; SOT-23-5; LCSC C141321

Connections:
+3V3: C1802.2, U1802.5 (IN); also elsewhere on the board
+3V3_FPGA: SW1801.2 (B); also elsewhere on the board
+5V: C1801.2, U1801.5 (IN); also elsewhere on the board
/Game Boy Interfaces/SW_Cartridge_s: R1803.2, R1805.1, SW1801.1 (A)
/Game Boy Interfaces/VGB_3V3_SW_En: Q1802.3 (D), R1804.2, R1806.2, U1802.4 (EN)
/Game Boy Interfaces/VGB_5V_SW_En: Q1801.3 (D), R1801.2, R1802.2, U1801.4 (EN)
GB_3V3_Enable: Q1801.1 (G), R1804.1; also elsewhere on the board
GB_5V_Enable: Q1802.1 (G), R1801.1; also elsewhere on the board
GND: C1801.1, C1802.1, Q1801.2 (S), Q1802.2 (S), R1802.1, R1805.2, R1806.1, U1801.2 (GND), U1802.2 (GND); also elsewhere on the board
SW_Cartridge: R1803.1; also elsewhere on the board
VGB: TP1801.1, U1801.1 (OUT), U1802.1 (OUT); also elsewhere on the board

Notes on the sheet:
This could be +3V3_FPGA or +3V3 It's easier to route +3V3
DMG/CGB: 100mA *max* draw, typical <40mA AGB: 100mA *max*, typical <30mA
Cartridge Shape Detector
VGB Mux
nFETs ensure enables are mutually exclusive

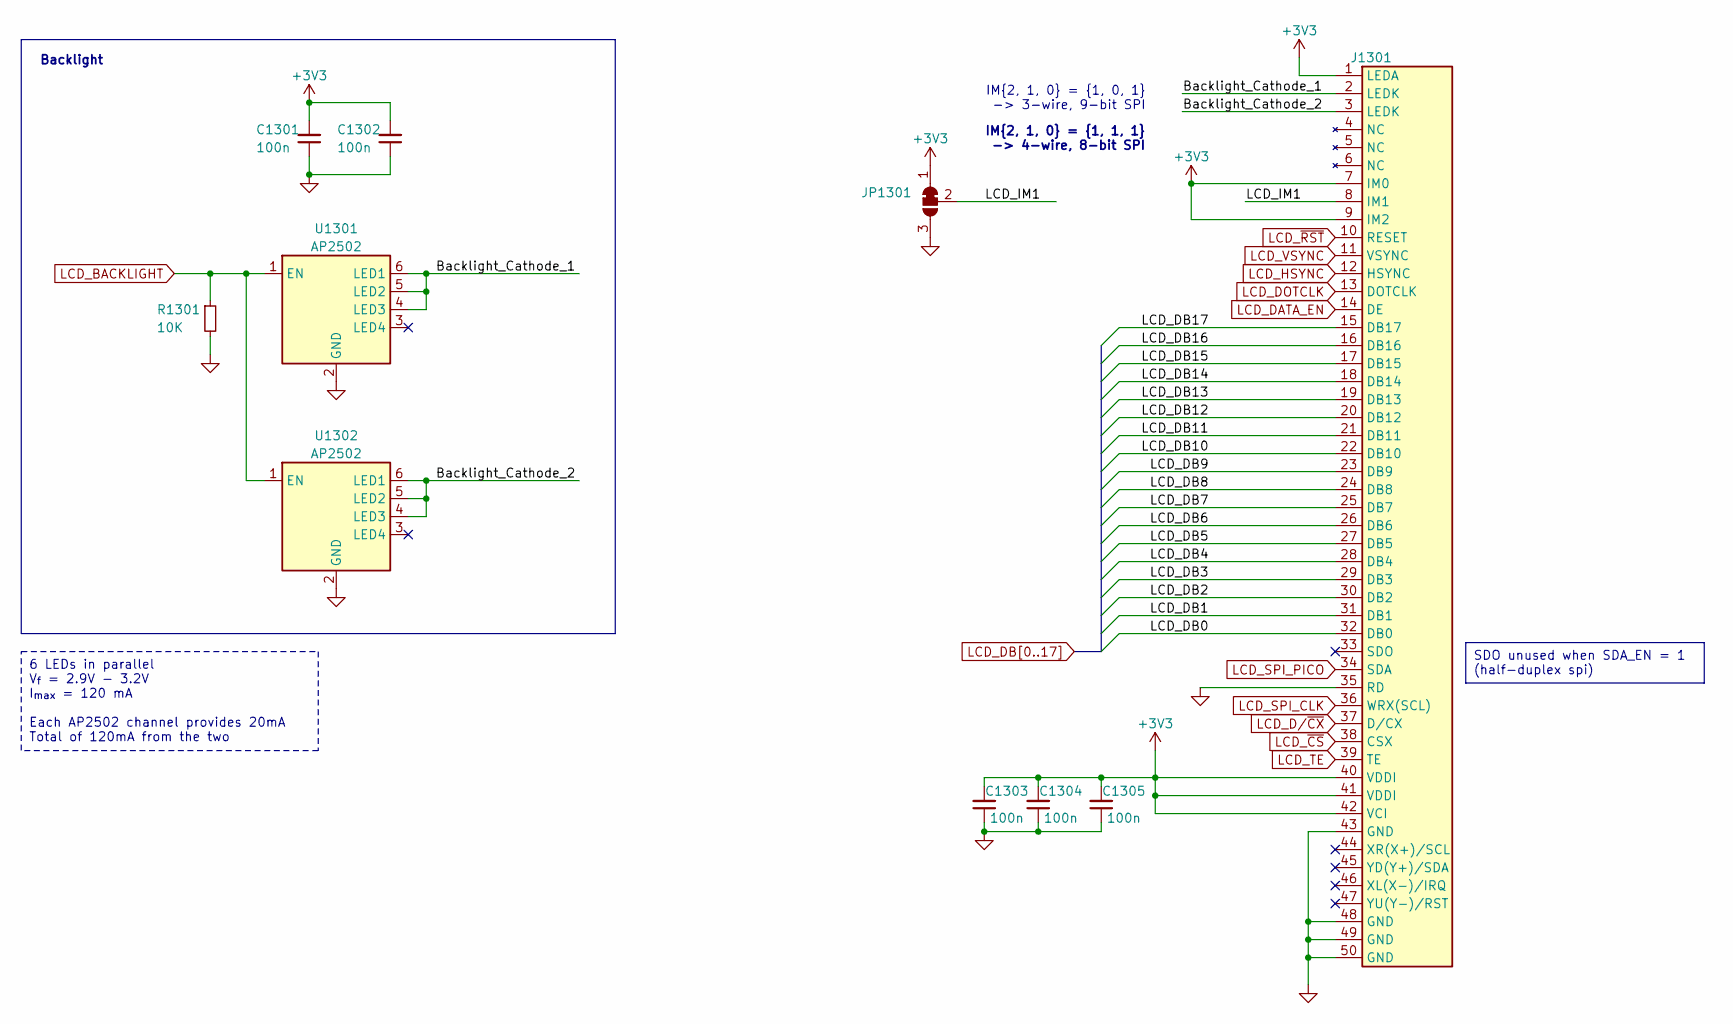
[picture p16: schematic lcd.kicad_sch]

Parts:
C1301, C1302, C1303, C1304, C1305: 100n; C_0402_1005Metric; LCSC C1525
J1301: Hirose_FH12S-50S-0.5SH_1x50-1MP_P0.50mm_Horizontal_FLIPPED; LCSC C598003
JP1301: SolderJumper_3_Bridged12; SolderJumper-3_P1.3mm_Bridged12_RoundedPad1.0x1.5mm
R1301: 10K; R_0402_1005Metric; LCSC C25744
U1301, U1302: AP2502; SOT-23-6; LCSC C460349

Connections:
+3V3: C1301.2, C1302.2, C1303.2, C1304.2, C1305.2, J1301.1 (LEDA), J1301.7 (IM0), J1301.9 (IM2), J1301.40 (VDDI), J1301.41 (VDDI), J1301.42 (VCI), JP1301.1 (A); also elsewhere on the board
/LCD/Backlight_Cathode_1: J1301.2 (LEDK), U1301.4 (LED3), U1301.5 (LED2), U1301.6 (LED1)
/LCD/Backlight_Cathode_2: J1301.3 (LEDK), U1302.4 (LED3), U1302.5 (LED2), U1302.6 (LED1)
/LCD/LCD_IM1: J1301.8 (IM1), JP1301.2 (C)
GND: C1301.1, C1302.1, C1303.1, C1304.1, C1305.1, J1301.35 (RD), J1301.43 (GND), J1301.48 (GND), J1301.49 (GND), J1301.50 (GND), JP1301.3 (B), R1301.2, U1301.2 (GND), U1302.2 (GND); also elsewhere on the board
LCD_BACKLIGHT: R1301.1, U1301.1 (EN), U1302.1 (EN); also elsewhere on the board
LCD_DATA_EN: J1301.14 (DE); also elsewhere on the board
LCD_DB0: J1301.32 (DB0); also elsewhere on the board
LCD_DB1: J1301.31 (DB1); also elsewhere on the board
LCD_DB2: J1301.30 (DB2); also elsewhere on the board
LCD_DB3: J1301.29 (DB3); also elsewhere on the board
LCD_DB4: J1301.28 (DB4); also elsewhere on the board
LCD_DB5: J1301.27 (DB5); also elsewhere on the board
LCD_DB6: J1301.26 (DB6); also elsewhere on the board
LCD_DB7: J1301.25 (DB7); also elsewhere on the board
LCD_DB8: J1301.24 (DB8); also elsewhere on the board
LCD_DB9: J1301.23 (DB9); also elsewhere on the board
LCD_DB10: J1301.22 (DB10); also elsewhere on the board
LCD_DB11: J1301.21 (DB11); also elsewhere on the board
LCD_DB12: J1301.20 (DB12); also elsewhere on the board
LCD_DB13: J1301.19 (DB13); also elsewhere on the board
LCD_DB14: J1301.18 (DB14); also elsewhere on the board
LCD_DB15: J1301.17 (DB15); also elsewhere on the board
LCD_DB16: J1301.16 (DB16); also elsewhere on the board
LCD_DB17: J1301.15 (DB17); also elsewhere on the board
LCD_DOTCLK: J1301.13 (DOTCLK); also elsewhere on the board
LCD_D/~CX: J1301.37 (D/CX); also elsewhere on the board
LCD_HSYNC: J1301.12 (HSYNC); also elsewhere on the board
LCD_SPI_CLK: J1301.36 (WRX(SCL)); also elsewhere on the board
LCD_SPI_PICO: J1301.34 (SDA); also elsewhere on the board
LCD_TE: J1301.39 (TE); also elsewhere on the board
LCD_VSYNC: J1301.11 (VSYNC); also elsewhere on the board
LCD_~CS: J1301.38 (CSX); also elsewhere on the board
LCD_~RST: J1301.10 (RESET); also elsewhere on the board

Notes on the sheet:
SDO unused when SDA_EN = 1 (half-duplex spi)
6 LEDs in parallel V_{f} = 2.9V - 3.2V I_{max} = 120 mA Each AP2502 channel provides 20mA Total of 120mA from the two
Backlight
IM{2, 1, 0} = {1, 1, 1} -> 4-wire, 8-bit SPI
IM{2, 1, 0} = {1, 0, 1} -> 3-wire, 9-bit SPI

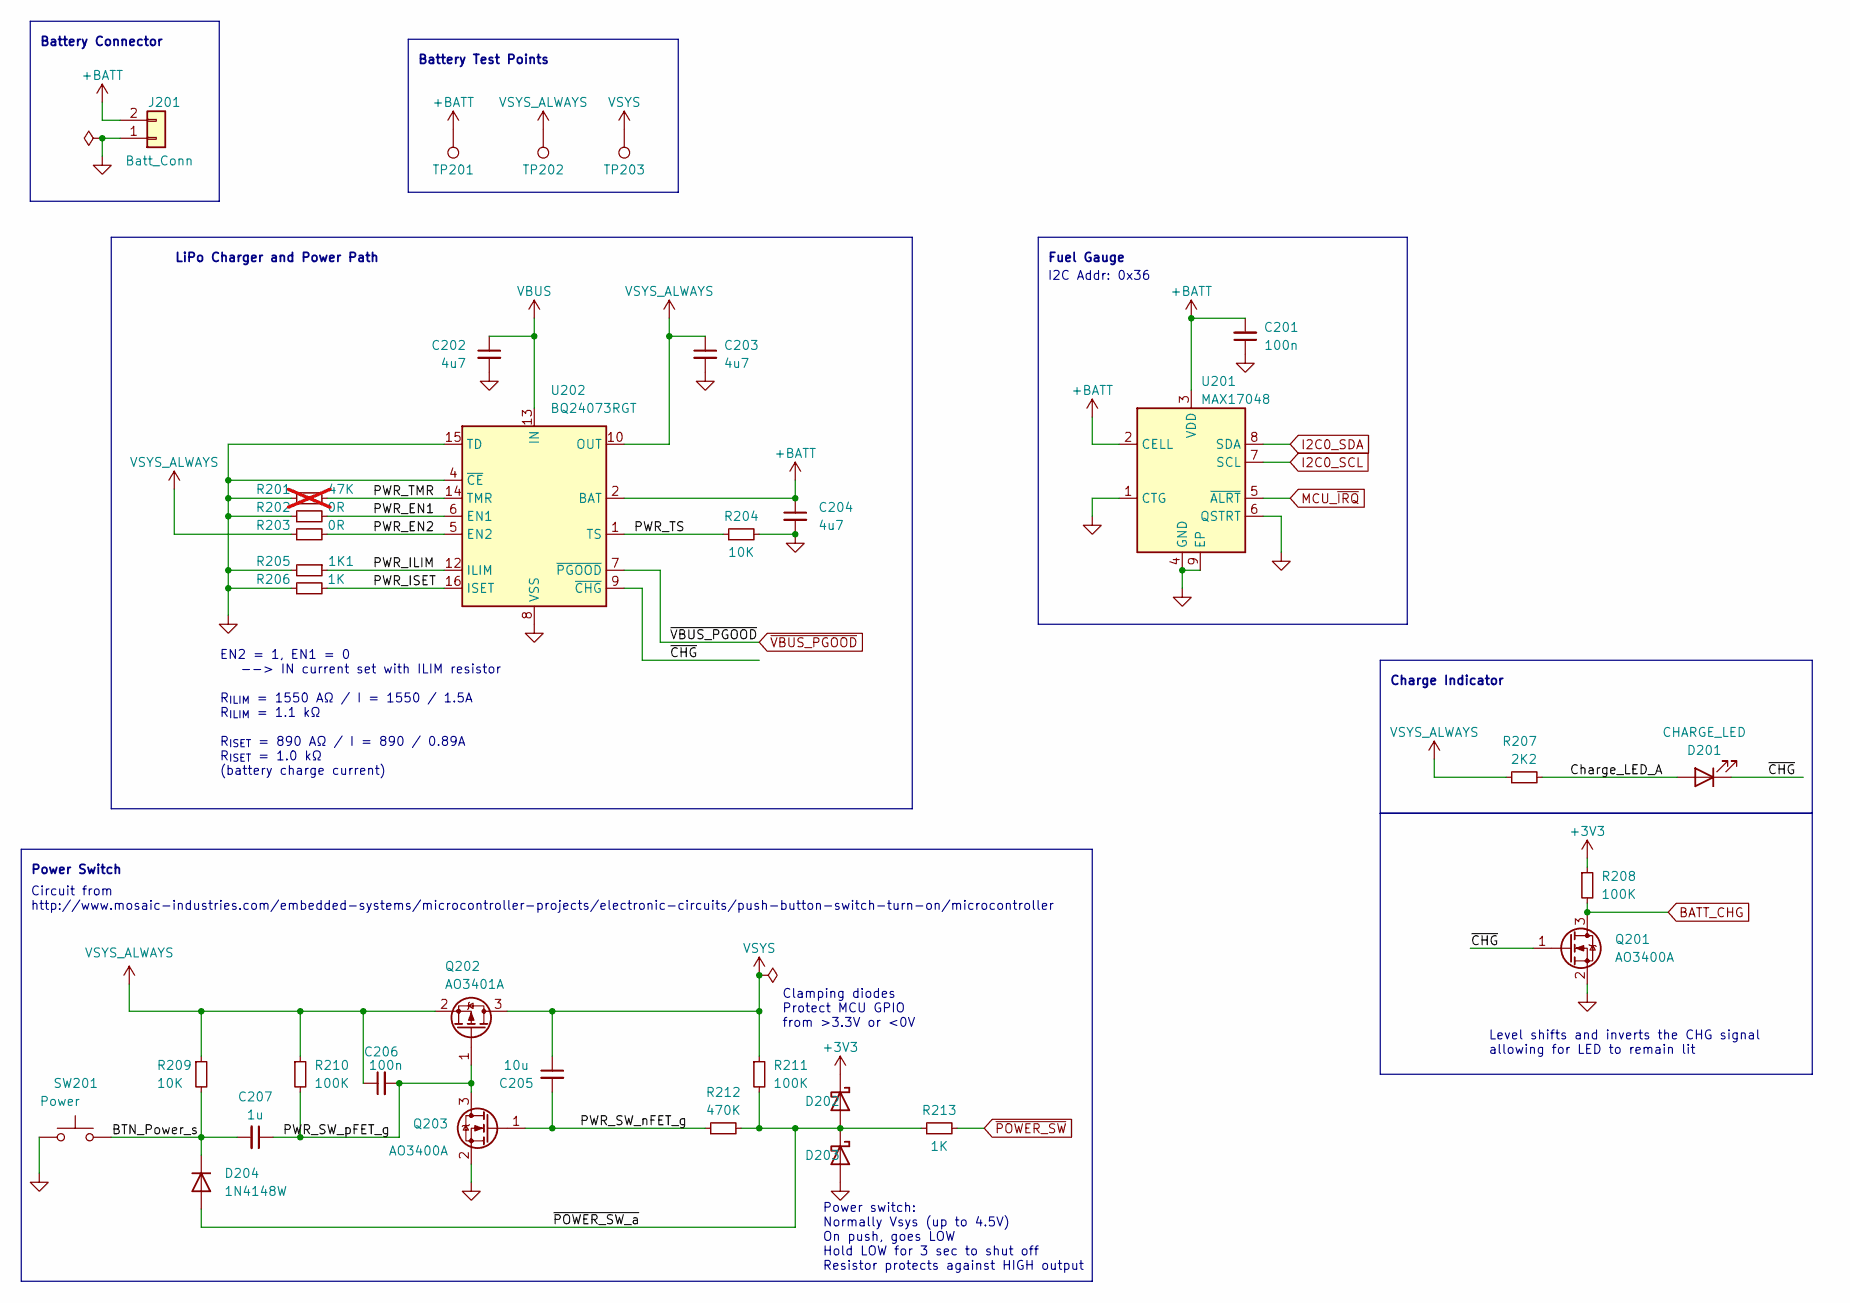
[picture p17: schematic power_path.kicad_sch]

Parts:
C201, C206: 100n; C_0402_1005Metric; LCSC C1525
C202, C203, C204: 4u7; C_0402_1005Metric; LCSC C23733
C205: 10u; C_0402_1005Metric; LCSC C15525
C207: 1u; C_0402_1005Metric; LCSC C52923
D201: CHARGE_LED; LED_0805_2012Metric; LCSC C2296
D202, D203: D_Schottky; D_SOD-323; LCSC C191023
D204: 1N4148W; D_SOD-123; LCSC C81598
J201: Batt_Conn; JST_PH_S2B-PH-SM4-TB_1x02-1MP_P2.00mm_Horizontal
Q201, Q203: AO3400A; SOT-23; LCSC C20917
Q202: AO3401A; SOT-23; LCSC C15127
R201: 47K; R_0402_1005Metric_Pad0.72x0.64mm_HandSolder; LCSC C25792; not fitted
R202, R203: 0R; R_0402_1005Metric_Pad0.72x0.64mm_HandSolder; LCSC C17168
R204, R209: 10K; R_0402_1005Metric; LCSC C25744
R205: 1K1; R_0402_1005Metric_Pad0.72x0.64mm_HandSolder; LCSC C25860
R206: 1K; R_0402_1005Metric_Pad0.72x0.64mm_HandSolder; LCSC C11702
R207: 2K2; R_0402_1005Metric; LCSC C25879
R208, R210, R211: 100K; R_0402_1005Metric; LCSC C25741
R212: 470K; R_0603_1608Metric_Pad0.98x0.95mm_HandSolder; LCSC C23178
R213: 1K; R_0402_1005Metric; LCSC C11702
SW201: Power; SW_SPST_SKSC; LCSC C115361
TP201: +BATT; TestPoint_2.54mm_THT
TP202: VSYS_ALWAYS; TestPoint_2.54mm_THT
TP203: VSYS; TestPoint_2.54mm_THT
U201: MAX17048; TDFN-8-1EP_2x2mm_P0.5mm_EP0.8x1.2mm; LCSC C2682616
U202: BQ24073RGT; VQFN-16-1EP_3x3mm_P0.5mm_EP1.6x1.6mm; LCSC C15220

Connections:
+3V3: D202.1 (K), R208.1; also elsewhere on the board
+BATT: C201.2, C204.1, J201.2, TP201.1, U201.2 (CELL), U201.3 (VDD), U202.2 (BAT), U202.3 (BAT)
/Power Path/BTN_Power_s: C207.2, D204.1 (K), R209.2, SW201.1
/Power Path/Charge_LED_A: D201.2 (A), R207.2
/Power Path/PWR_EN1: R202.2, U202.6 (EN1)
/Power Path/PWR_EN2: R203.2, U202.5 (EN2)
/Power Path/PWR_ILIM: R205.1, U202.12 (ILIM)
/Power Path/PWR_ISET: R206.2, U202.16 (ISET)
/Power Path/PWR_SW_nFET_g: C205.2, Q203.1 (G), R212.1
/Power Path/PWR_SW_pFET_g: C206.2, C207.1, Q202.1 (G), Q203.3 (D), R210.2
/Power Path/PWR_TMR: R201.1, U202.14 (TMR)
/Power Path/PWR_TS: R204.1, U202.1 (TS)
/Power Path/~CHG: D201.1 (K), Q201.1 (G), U202.9 (~CHG)
/Power Path/~POWER_SW_a: D202.2 (A), D203.1 (K), D204.2 (A), R211.2, R212.2, R213.1
BATT_CHG: Q201.3 (D), R208.2; also elsewhere on the board
GND: C201.1, C202.2, C203.2, C204.2, D203.2 (A), J201.1, Q201.2 (S), Q203.2 (S), R201.2, R202.1, R204.2, R205.2, R206.1, SW201.2, U201.1 (CTG), U201.4 (GND), U201.6 (QSTRT), U201.9 (EP), U202.4 (~CE), U202.8 (VSS), U202.15 (TD), U202.17 (VSS); also elsewhere on the board
I2C0_SCL: U201.7 (SCL); also elsewhere on the board
I2C0_SDA: U201.8 (SDA); also elsewhere on the board
MCU_~IRQ: U201.5 (~ALRT); also elsewhere on the board
VBUS: C202.1, U202.13 (IN); also elsewhere on the board
VSYS: C205.1, Q202.3 (D), R211.1, TP203.1; also elsewhere on the board
VSYS_ALWAYS: C203.1, C206.1, Q202.2 (S), R203.1, R207.1, R209.1, R210.1, TP202.1, U202.10 (OUT), U202.11 (OUT); also elsewhere on the board
~POWER_SW: R213.2; also elsewhere on the board
~VBUS_PGOOD: U202.7 (~PGOOD); also elsewhere on the board

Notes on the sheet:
Charge Indicator
Battery Connector
LiPo Charger and Power Path
Power Switch
Level shifts and inverts the CHG signal allowing for LED to remain lit
Battery Test Points
Power switch: Normally Vsys (up to 4.5V) On push, goes LOW Hold LOW for 3 sec to shut off Resistor protects against HIGH output
Clamping diodes Protect MCU GPIO from >3.3V or <0V
Circuit from http://www.mosaic-industries.com/embedded-systems/microcontroller-projects/electronic-circuits/push-button-switch-turn-on/microcontroller
I2C Addr: 0x36
EN2 = 1, EN1 = 0 --> IN current set with ILIM resistor R_{ILIM} = 1550 AΩ / I = 1550 / 1.5A R_{ILIM} = 1.1 kΩ R_{ISET} = 890 AΩ / I = 890 / 0.89A R_{ISET} = 1.0 kΩ (battery charge current)
Fuel Gauge

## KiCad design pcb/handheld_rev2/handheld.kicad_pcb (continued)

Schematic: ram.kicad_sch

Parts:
C1401, C1402, C1403, C1404, C1405, C1406, C1407, C1410, C1411: 100n; C_0402_1005Metric; LCSC C1525
C1408, C1409: 10u; C_0402_1005Metric; LCSC C15525
U1401: W9825G6KH-6; TSOP-II-54_22.2x10.16mm_P0.8mm; LCSC C62246
U1402: IS61WV25616BLL-10TLI; TSOP-II-44_10.16x18.41mm_P0.8mm; LCSC C53825

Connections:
+3V3_FPGA: C1401.2, C1402.2, C1403.2, C1404.2, C1405.2, C1406.2, C1407.2, C1408.1, C1409.1, C1410.2, C1411.2, U1401.1 (VDD), U1401.3 (VDDQ), U1401.9 (VDDQ), U1401.14 (VDD), U1401.27 (VDD), U1401.43 (VDDQ), U1401.49 (VDDQ), U1402.11 (VDD), U1402.33 (VDD); also elsewhere on the board
GND: C1401.1, C1402.1, C1403.1, C1404.1, C1405.1, C1406.1, C1407.1, C1408.2, C1409.2, C1410.1, C1411.1, U1401.6 (VSSQ), U1401.12 (VSSQ), U1401.28 (VSS), U1401.41 (VSS), U1401.46 (VSSQ), U1401.52 (VSSQ), U1401.54 (VSS), U1402.12 (GND), U1402.34 (GND); also elsewhere on the board
SDRAM_0_~CS: U1401.19 (~CS); also elsewhere on the board
SDRAM_A0: U1401.23 (A0); also elsewhere on the board
SDRAM_A1: U1401.24 (A1); also elsewhere on the board
SDRAM_A2: U1401.25 (A2); also elsewhere on the board
SDRAM_A3: U1401.26 (A3); also elsewhere on the board
SDRAM_A4: U1401.29 (A4); also elsewhere on the board
SDRAM_A5: U1401.30 (A5); also elsewhere on the board
SDRAM_A6: U1401.31 (A6); also elsewhere on the board
SDRAM_A7: U1401.32 (A7); also elsewhere on the board
SDRAM_A8: U1401.33 (A8); also elsewhere on the board
SDRAM_A9: U1401.34 (A9); also elsewhere on the board
SDRAM_A10: U1401.22 (A10/AP); also elsewhere on the board
SDRAM_A11: U1401.35 (A11); also elsewhere on the board
SDRAM_A12: U1401.36 (A12); also elsewhere on the board
SDRAM_BS0: U1401.20 (BS0); also elsewhere on the board
SDRAM_BS1: U1401.21 (BS1); also elsewhere on the board
SDRAM_CKE: U1401.37 (CKE); also elsewhere on the board
SDRAM_CLK: U1401.38 (CLK); also elsewhere on the board
SDRAM_DQ0: U1401.2 (DQ0); also elsewhere on the board
SDRAM_DQ1: U1401.4 (DQ1); also elsewhere on the board
SDRAM_DQ2: U1401.5 (DQ2); also elsewhere on the board
SDRAM_DQ3: U1401.7 (DQ3); also elsewhere on the board
SDRAM_DQ4: U1401.8 (DQ4); also elsewhere on the board
SDRAM_DQ5: U1401.10 (DQ5); also elsewhere on the board
SDRAM_DQ6: U1401.11 (DQ6); also elsewhere on the board
SDRAM_DQ7: U1401.13 (DQ7); also elsewhere on the board
SDRAM_DQ8: U1401.42 (DQ8); also elsewhere on the board
SDRAM_DQ9: U1401.44 (DQ9); also elsewhere on the board
SDRAM_DQ10: U1401.45 (DQ10); also elsewhere on the board
SDRAM_DQ11: U1401.47 (DQ11); also elsewhere on the board
SDRAM_DQ12: U1401.48 (DQ12); also elsewhere on the board
SDRAM_DQ13: U1401.50 (DQ13); also elsewhere on the board
SDRAM_DQ14: U1401.51 (DQ14); also elsewhere on the board
SDRAM_DQ15: U1401.53 (DQ15); also elsewhere on the board
SDRAM_LDQM: U1401.15 (LDQM); also elsewhere on the board
SDRAM_UDQM: U1401.39 (UDQM); also elsewhere on the board
SDRAM_~CAS: U1401.17 (~CAS); also elsewhere on the board
SDRAM_~RAS: U1401.18 (~RAS); also elsewhere on the board
SDRAM_~WE: U1401.16 (~WE); also elsewhere on the board
SRAM_A0: U1402.1 (A0); also elsewhere on the board
SRAM_A1: U1402.2 (A1); also elsewhere on the board
SRAM_A2: U1402.3 (A2); also elsewhere on the board
SRAM_A3: U1402.4 (A3); also elsewhere on the board
SRAM_A4: U1402.5 (A4); also elsewhere on the board
SRAM_A5: U1402.18 (A5); also elsewhere on the board
SRAM_A6: U1402.19 (A6); also elsewhere on the board
SRAM_A7: U1402.20 (A7); also elsewhere on the board
SRAM_A8: U1402.21 (A8); also elsewhere on the board
SRAM_A9: U1402.22 (A9); also elsewhere on the board
SRAM_A10: U1402.23 (A10); also elsewhere on the board
SRAM_A11: U1402.24 (A11); also elsewhere on the board
SRAM_A12: U1402.25 (A12); also elsewhere on the board
SRAM_A13: U1402.26 (A13); also elsewhere on the board
SRAM_A14: U1402.27 (A14); also elsewhere on the board
SRAM_A15: U1402.42 (A15); also elsewhere on the board
SRAM_A16: U1402.43 (A16); also elsewhere on the board
SRAM_A17: U1402.44 (A17); also elsewhere on the board
SRAM_IO0: U1402.7 (IO0); also elsewhere on the board
SRAM_IO1: U1402.8 (IO1); also elsewhere on the board
SRAM_IO2: U1402.9 (IO2); also elsewhere on the board
SRAM_IO3: U1402.10 (IO3); also elsewhere on the board
SRAM_IO4: U1402.13 (IO4); also elsewhere on the board
SRAM_IO5: U1402.14 (IO5); also elsewhere on the board
SRAM_IO6: U1402.15 (IO6); also elsewhere on the board
SRAM_IO7: U1402.16 (IO7); also elsewhere on the board
SRAM_IO8: U1402.29 (IO8); also elsewhere on the board
SRAM_IO9: U1402.30 (IO9); also elsewhere on the board
SRAM_IO10: U1402.31 (IO10); also elsewhere on the board
SRAM_IO11: U1402.32 (IO11); also elsewhere on the board
SRAM_IO12: U1402.35 (IO12); also elsewhere on the board
SRAM_IO13: U1402.36 (IO13); also elsewhere on the board
SRAM_IO14: U1402.37 (IO14); also elsewhere on the board
SRAM_IO15: U1402.38 (IO15); also elsewhere on the board
SRAM_~CE: U1402.6 (~CE); also elsewhere on the board
SRAM_~LB: U1402.39 (~LB); also elsewhere on the board
SRAM_~OE: U1402.41 (~OE); also elsewhere on the board
SRAM_~UB: U1402.40 (~UB); also elsewhere on the board
SRAM_~WE: U1402.17 (~WE); also elsewhere on the board

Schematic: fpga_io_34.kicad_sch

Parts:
C1101, C1102, C1103, C1104: 470n; C_0402_1005Metric; LCSC C47339
C1105, C1106: 4u7; C_0402_1005Metric; LCSC C23733
U601: XC7A100T-CSG324; Xilinx_CSG324; LCSC C1521791

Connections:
+3V3_FPGA: C1101.1, C1102.1, C1103.1, C1104.1, C1105.1, C1106.1, U601.K4 (VCCO_34), U601.N3 (VCCO_34), U601.P6 (VCCO_34), U601.T2 (VCCO_34), U601.U5 (VCCO_34), U601.V8 (VCCO_34); also elsewhere on the board
BTN_A: U601.N5 (IO_L13P_T2_MRCC_34); also elsewhere on the board
BTN_B: U601.P5 (IO_L13N_T2_MRCC_34); also elsewhere on the board
BTN_R: U601.L5 (IO_L6N_T0_VREF_34); also elsewhere on the board
BTN_Start: U601.K5 (IO_L5P_T0_34); also elsewhere on the board
BTN_X: U601.L6 (IO_L6P_T0_34); also elsewhere on the board
BTN_Y: U601.M6 (IO_L18P_T2_34); also elsewhere on the board
GND: C1101.2, C1102.2, C1103.2, C1104.2, C1105.2, C1106.2; also elsewhere on the board
SDRAM_0_~CS: U601.V1 (IO_L7N_T1_34); also elsewhere on the board
SDRAM_A0: U601.R3 (IO_L11P_T1_SRCC_34); also elsewhere on the board
SDRAM_A1: U601.T3 (IO_L11N_T1_SRCC_34); also elsewhere on the board
SDRAM_A2: U601.T4 (IO_L12N_T1_MRCC_34); also elsewhere on the board
SDRAM_A3: U601.R5 (IO_L19N_T3_VREF_34); also elsewhere on the board
SDRAM_A4: U601.R6 (IO_L19P_T3_34); also elsewhere on the board
SDRAM_A5: U601.T6 (IO_L23N_T3_34); also elsewhere on the board
SDRAM_A6: U601.R7 (IO_L23P_T3_34); also elsewhere on the board
SDRAM_A7: U601.R8 (IO_L24P_T3_34); also elsewhere on the board
SDRAM_A8: U601.T8 (IO_L24N_T3_34); also elsewhere on the board
SDRAM_A9: U601.U2 (IO_L9P_T1_DQS_34); also elsewhere on the board
SDRAM_A10: U601.P4 (IO_L14P_T2_SRCC_34); also elsewhere on the board
SDRAM_A11: U601.V2 (IO_L9N_T1_DQS_34); also elsewhere on the board
SDRAM_A12: U601.U3 (IO_L8N_T1_34); also elsewhere on the board
SDRAM_BS0: U601.N4 (IO_L16N_T2_34); also elsewhere on the board
SDRAM_BS1: U601.P3 (IO_L14N_T2_SRCC_34); also elsewhere on the board
SDRAM_CKE: U601.U4 (IO_L8P_T1_34); also elsewhere on the board
SDRAM_CLK: U601.V4 (IO_L10N_T1_34); also elsewhere on the board
SDRAM_DQ0: U601.P2 (IO_L15P_T2_DQS_34); also elsewhere on the board
SDRAM_DQ1: U601.N2 (IO_L3P_T0_DQS_34); also elsewhere on the board
SDRAM_DQ2: U601.N1 (IO_L3N_T0_DQS_34); also elsewhere on the board
SDRAM_DQ3: U601.M2 (IO_L4N_T0_34); also elsewhere on the board
SDRAM_DQ4: U601.M1 (IO_L1N_T0_34); also elsewhere on the board
SDRAM_DQ5: U601.L1 (IO_L1P_T0_34); also elsewhere on the board
SDRAM_DQ6: U601.M3 (IO_L4P_T0_34); also elsewhere on the board
SDRAM_DQ7: U601.M4 (IO_L16P_T2_34); also elsewhere on the board
SDRAM_DQ8: U601.V5 (IO_L10P_T1_34); also elsewhere on the board
SDRAM_DQ9: U601.U6 (IO_L22N_T3_34); also elsewhere on the board
SDRAM_DQ10: U601.V6 (IO_L20N_T3_34); also elsewhere on the board
SDRAM_DQ11: U601.U7 (IO_L22P_T3_34); also elsewhere on the board
SDRAM_DQ12: U601.V7 (IO_L20P_T3_34); also elsewhere on the board
SDRAM_DQ13: U601.U8 (IO_25_34); also elsewhere on the board
SDRAM_DQ14: U601.U9 (IO_L21P_T3_DQS_34); also elsewhere on the board
SDRAM_DQ15: U601.V9 (IO_L21N_T3_DQS_34); also elsewhere on the board
SDRAM_LDQM: U601.R1 (IO_L17P_T2_34); also elsewhere on the board
SDRAM_UDQM: U601.T5 (IO_L12P_T1_MRCC_34); also elsewhere on the board
SDRAM_~CAS: U601.T1 (IO_L17N_T2_34); also elsewhere on the board
SDRAM_~RAS: U601.U1 (IO_L7P_T1_34); also elsewhere on the board
SDRAM_~WE: U601.R2 (IO_L15N_T2_DQS_34); also elsewhere on the board

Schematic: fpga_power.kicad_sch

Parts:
C601, C602, C603, C604, C619: 100u; C_1206_3216Metric; LCSC C15008
C605, C606, C607, C608, C609, C610, C623, C624: 4u7; C_0402_1005Metric; LCSC C23733
C611, C612, C613, C614, C615, C616, C617, C618, C620, C621, C625, C626, C627, C628: 470n; C_0402_1005Metric; LCSC C47339
C622, C629: 47u; C_0805_2012Metric; LCSC C16780
U601: XC7A100T-CSG324; Xilinx_CSG324; LCSC C1521791

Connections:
+1V0: C601.1, C602.1, C603.1, C604.1, C605.1, C606.1, C607.1, C608.1, C609.1, C610.1, C611.1, C612.1, C613.1, C614.1, C615.1, C616.1, C617.1, C618.1, C619.1, C620.1, C621.1, U601.F8 (VCCINT), U601.F10 (VCCBRAM), U601.G7 (VCCINT), U601.G9 (VCCINT), U601.G11 (VCCBRAM), U601.H8 (VCCINT), U601.J7 (VCCINT), U601.J11 (VCCINT), U601.K8 (VCCINT), U601.L7 (VCCINT), U601.L11 (VCCINT), U601.M8 (VCCINT), U601.M10 (VCCINT), U601.N7 (VCCINT), U601.N9 (VCCINT), U601.N11 (VCCINT); also elsewhere on the board
+1V8: C622.1, C623.1, C624.1, C625.1, C626.1, C627.1, C628.1, U601.F12 (VCCAUX), U601.H10 (VCCADC_0), U601.H12 (VCCAUX), U601.K12 (VCCAUX), U601.M12 (VCCAUX); also elsewhere on the board
+3V3_FPGA: C629.1; also elsewhere on the board
GND: C601.2, C602.2, C603.2, C604.2, C605.2, C606.2, C607.2, C608.2, C609.2, C610.2, C611.2, C612.2, C613.2, C614.2, C615.2, C616.2, C617.2, C618.2, C619.2, C620.2, C621.2, C622.2, C623.2, C624.2, C625.2, C626.2, C627.2, C628.2, C629.2, U601.A2 (GND), U601.A12 (GND), U601.B5 (GND), U601.B15 (GND), U601.C8 (GND), U601.C18 (GND), U601.D1 (GND), U601.D11 (GND), U601.E4 (GND), U601.E8 (VCCBATT_0), U601.E14 (GND), U601.F7 (GND), U601.F9 (GND), U601.F11 (GND), U601.F17 (GND), U601.G8 (GND), U601.G10 (GND), U601.G12 (GND), U601.H3 (GND), U601.H7 (GND), U601.H9 (GNDADC_0), U601.H11 (GND), U601.H13 (GND), U601.J6 (GND), U601.J8 (GND), U601.J12 (GND), U601.J16 (GND), U601.K7 (GND), U601.K11 (GND), U601.L2 (GND), U601.L8 (GND), U601.L12 (GND), U601.M5 (GND), U601.M7 (GND), U601.M9 (GND), U601.M11 (GND), U601.M15 (GND), U601.N8 (GND), U601.N10 (GND), U601.N12 (GND), U601.N18 (GND), U601.P1 (GND), U601.R4 (GND), U601.R14 (GND), U601.T7 (GND), U601.T17 (GND), U601.U10 (GND), U601.V3 (GND), U601.V13 (GND); also elsewhere on the board

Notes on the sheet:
Consider adding ferrite bead to GNDADC
Bulk decoupling capacitor shared between 4x IO banks sharing same VCCO (3.3V)

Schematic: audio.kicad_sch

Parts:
C1701, C1703, C1709, C1711: 10u; C_0402_1005Metric; LCSC C15525
C1702, C1704, C1706, C1708, C1710, C1712: 100n; C_0402_1005Metric; LCSC C1525
C1705, C1707: 22u; C_0805_2012Metric; LCSC C45783
C1713, C1714: 100u; C_1206_3216Metric; LCSC C15008
J1701: SPK_L; Speaker_Same_Sky_CMS-160903-18S-X8
J1702: SPK_R; Speaker_Same_Sky_CMS-160903-18S-X8
J1703: Headphone Jack; Jack_3.5mm_CUI_SJ-43614-SMT
Q1701: AO3400A; SOT-23; LCSC C20917
R1701: 100K; R_0402_1005Metric; LCSC C25741
R1702: 1K; R_0402_1005Metric; LCSC C11702
R1703: 2K2; R_0402_1005Metric; LCSC C25879
R1704: 10K; R_0402_1005Metric; LCSC C25744
U1701: TLV320DAC3101; VQFN-32-1EP_5x5mm_P0.5mm_EP3.5x3.5mm; LCSC C2651664

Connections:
+1V8: C1709.1, C1710.2, U1701.3 (DVDD); also elsewhere on the board
+3V3: C1701.1, C1702.2, C1703.1, C1704.2, C1711.1, C1712.2, U1701.2 (IOVDD), U1701.17 (AVDD), U1701.28 (HPVDD); also elsewhere on the board
/Audio/DAC_INT: R1702.2, R1704.1, U1701.32 (GPIO1)
/Audio/DAC_INT_R: Q1701.1 (G), R1702.1
/Audio/HeadphoneJack_Tip: C1714.2, J1703.T
/Audio/Headphone_Jack_R: C1713.2, J1703.R1
/Audio/Headphone_Left: C1714.1, U1701.27 (HPL)
/Audio/Headphone_Mic: J1703.S, R1703.2, U1701.11 (VOL/MICDET)
/Audio/Headphone_Right: C1713.1, U1701.30 (HPR)
/Audio/MICBIAS: R1703.1, U1701.12 (MICBIAS)
/Audio/Speaker_Left_M: J1701.1, U1701.19 (SPLM)
/Audio/Speaker_Left_P: J1701.2, U1701.22 (SPLP)
/Audio/Speaker_Right_M: J1702.1, U1701.23 (SPRM)
/Audio/Speaker_Right_P: J1702.2, U1701.26 (SPRP)
DAC_BCLK: U1701.7 (BCLK); also elsewhere on the board
DAC_DIN: U1701.5 (DIN); also elsewhere on the board
DAC_MCLK: U1701.8 (MCLK); also elsewhere on the board
DAC_WCLK: U1701.6 (WCLK); also elsewhere on the board
DAC_~RESET: R1701.1, U1701.31 (~RESET); also elsewhere on the board
GND: C1701.2, C1702.1, C1703.2, C1704.1, C1705.2, C1706.1, C1707.2, C1708.1, C1709.2, C1710.1, C1711.2, C1712.1, J1703.R2, Q1701.2 (S), R1701.2, R1704.2, U1701.1 (IOVSS), U1701.16 (AVSS), U1701.18 (DVSS), U1701.20 (SPLVSS), U1701.25 (SPRVSS), U1701.29 (HPVSS), U1701.33 (EP); also elsewhere on the board
I2C0_SCL: U1701.10 (SCL); also elsewhere on the board
I2C0_SDA: U1701.9 (SDA); also elsewhere on the board
MCU_~IRQ: Q1701.3 (D); also elsewhere on the board
VSYS: C1705.1, C1706.2, C1707.1, C1708.2, U1701.21 (SPLVDD), U1701.24 (SPRVDD); also elsewhere on the board

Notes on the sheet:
CTIA (Apple) style Tip is Left R1 is Right R2 is GND Sleeve is Mic
Headphone Jack
nFET converts push-pull active-high DAC interrupt into open-drain active-low MCU_~{INT}
CMS-160903-18S-X8
Speaker
I2C Addr: 0x18

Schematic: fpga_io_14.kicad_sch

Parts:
C801, C802, C803, C804: 470n; C_0402_1005Metric; LCSC C47339
C805, C806: 4u7; C_0402_1005Metric; LCSC C23733
D801: H5VU25U; Diodes_UDFN-10_1.0x2.5mm_P0.5mm; LCSC C7420374
J801: PMOD; PinSocket_1x06_P2.54mm_Horizontal_SMD
R801: 1K; R_0402_1005Metric; LCSC C11702
U601: XC7A100T-CSG324; Xilinx_CSG324; LCSC C1521791

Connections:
+3V3_FPGA: C801.1, C802.1, C803.1, C804.1, C805.1, C806.1, J801.1, R801.2, U601.L17 (VCCO_14), U601.N13 (VCCO_14), U601.P16 (VCCO_14), U601.T12 (VCCO_14), U601.U15 (VCCO_14), U601.V18 (VCCO_14); also elsewhere on the board
/FPGA IO Bank 14/FPGA_PUDC_B: R801.1, U601.L15 (IO_L3P_T0_DQS_PUDC_B_14)
/FPGA IO Bank 14/PMOD_1: D801.5 (K4), D801.6 (K4), J801.6, U601.M14 (IO_L2N_T0_D03_14)
/FPGA IO Bank 14/PMOD_2: D801.4 (K3), D801.7 (K3), J801.5, U601.N14 (IO_L8P_T1_D11_14)
/FPGA IO Bank 14/PMOD_3: D801.2 (K2), D801.9 (K2), J801.4, U601.P14 (IO_L8N_T1_D12_14)
/FPGA IO Bank 14/PMOD_4: D801.1 (K1), D801.10 (K1), J801.3, U601.M13 (IO_L6N_T0_D08_VREF_14)
FPGA_SPI_D0: U601.K18 (IO_L1N_T0_D01_DIN_14); also elsewhere on the board
GB_Cart_VIN: U601.L13 (IO_L6P_T0_FCS_B_14); also elsewhere on the board
GB_Dir_VIN: U601.L14 (IO_L2P_T0_D02_14); also elsewhere on the board
GND: C801.2, C802.2, C803.2, C804.2, C805.2, C806.2, D801.3 (A), D801.8 (A), J801.2; also elsewhere on the board
LCD_DB10: U601.L18 (IO_L4P_T0_D04_14); also elsewhere on the board
LCD_DB11: U601.K17 (IO_L1P_T0_D00_MOSI_14); also elsewhere on the board
LCD_TE: U601.T11 (IO_L19P_T3_A10_D26_14); also elsewhere on the board
SRAM_A0: U601.N17 (IO_L9P_T1_DQS_14); also elsewhere on the board
SRAM_A1: U601.M17 (IO_L10N_T1_D15_14); also elsewhere on the board
SRAM_A2: U601.M18 (IO_L4N_T0_D05_14); also elsewhere on the board
SRAM_A3: U601.T9 (IO_L24P_T3_A01_D17_14); also elsewhere on the board
SRAM_A4: U601.T10 (IO_L24N_T3_A00_D16_14); also elsewhere on the board
SRAM_A5: U601.P15 (IO_L13P_T2_MRCC_14); also elsewhere on the board
SRAM_A6: U601.N16 (IO_L11N_T1_SRCC_14); also elsewhere on the board
SRAM_A7: U601.N15 (IO_L11P_T1_SRCC_14); also elsewhere on the board
SRAM_A8: U601.M16 (IO_L10P_T1_D14_14); also elsewhere on the board
SRAM_A9: U601.L16 (IO_L3N_T0_DQS_EMCCLK_14); also elsewhere on the board
SRAM_A10: U601.V12 (IO_L20N_T3_A07_D23_14); also elsewhere on the board
SRAM_A11: U601.U11 (IO_L19N_T3_A09_D25_VREF_14); also elsewhere on the board
SRAM_A12: U601.V11 (IO_L21N_T3_DQS_A06_D22_14); also elsewhere on the board
SRAM_A13: U601.V10 (IO_L21P_T3_DQS_14); also elsewhere on the board
SRAM_A14: U601.U12 (IO_L20P_T3_A08_D24_14); also elsewhere on the board
SRAM_A15: U601.R18 (IO_L7P_T1_D09_14); also elsewhere on the board
SRAM_A16: U601.P17 (IO_L12P_T1_MRCC_14); also elsewhere on the board
SRAM_A17: U601.P18 (IO_L9N_T1_DQS_D13_14); also elsewhere on the board
SRAM_IO0: U601.R11 (IO_0_14); also elsewhere on the board
SRAM_IO1: U601.R12 (IO_L5P_T0_D06_14); also elsewhere on the board
SRAM_IO2: U601.T13 (IO_L23P_T3_A03_D19_14); also elsewhere on the board
SRAM_IO3: U601.R13 (IO_L5N_T0_D07_14); also elsewhere on the board
SRAM_IO4: U601.T14 (IO_L14P_T2_SRCC_14); also elsewhere on the board
SRAM_IO5: U601.T15 (IO_L14N_T2_SRCC_14); also elsewhere on the board
SRAM_IO6: U601.T16 (IO_L15N_T2_DQS_DOUT_CSO_B_14); also elsewhere on the board
SRAM_IO7: U601.R16 (IO_L15P_T2_DQS_RDWR_B_14); also elsewhere on the board
SRAM_IO8: U601.U13 (IO_L23N_T3_A02_D18_14); also elsewhere on the board
SRAM_IO9: U601.V14 (IO_L22N_T3_A04_D20_14); also elsewhere on the board
SRAM_IO10: U601.U14 (IO_L22P_T3_A05_D21_14); also elsewhere on the board
SRAM_IO11: U601.V15 (IO_L16P_T2_CSI_B_14); also elsewhere on the board
SRAM_IO12: U601.V16 (IO_L16N_T2_A15_D31_14); also elsewhere on the board
SRAM_IO13: U601.U16 (IO_L18P_T2_A12_D28_14); also elsewhere on the board
SRAM_IO14: U601.V17 (IO_L18N_T2_A11_D27_14); also elsewhere on the board
SRAM_IO15: U601.U18 (IO_L17N_T2_A13_D29_14); also elsewhere on the board
SRAM_~CE: U601.R10 (IO_25_14); also elsewhere on the board
SRAM_~LB: U601.U17 (IO_L17P_T2_A14_D30_14); also elsewhere on the board
SRAM_~OE: U601.R17 (IO_L12N_T1_MRCC_14); also elsewhere on the board
SRAM_~UB: U601.T18 (IO_L7N_T1_D10_14); also elsewhere on the board
SRAM_~WE: U601.R15 (IO_L13N_T2_MRCC_14); also elsewhere on the board

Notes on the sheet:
PMOD
PUDC_B high disables pull-ups during boot

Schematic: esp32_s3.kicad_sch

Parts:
C401, C403: 100n; C_0402_1005Metric; LCSC C1525
C402: 22u; C_0805_2012Metric; LCSC C45783
D401: STATUS_LED; LED_0805_2012Metric; LCSC C2297
J401: TP_I2C; PinSocket_1x04_P2.54mm_Vertical; not fitted
J402: Micro_SD_Card_Det1; microSD_G-Switch_GT-TF003-H0185-02; LCSC C5155564
Q401: AO3400A; SOT-23; LCSC C20917
R401, R403, R420, R421, R422, R423, R424, R425, R426, R427: 10K; R_0402_1005Metric; LCSC C25744
R402, R406, R408, R409, R410, R411, R413, R414, R415, R416, R417, R418, R419: 0R; R_0402_1005Metric_Pad0.72x0.64mm_HandSolder; LCSC C17168
R404, R405: 3K3; R_0402_1005Metric_Pad0.72x0.64mm_HandSolder; LCSC C25890
R407: 2K2; R_0402_1005Metric; LCSC C25879
R412: 100K; R_0402_1005Metric; LCSC C25741
TP401, TP402: FPGA_SPI_~{CS}; TestPoint_Pad_D1.0mm
U401: ESP32-S3-MINI-1-N8; ESP32-S3-MINI-1; LCSC C2913206

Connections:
+3V3: C401.2, C402.1, C403.2, J402.4 (VDD), R401.1, R403.1, R404.1, R405.1, R407.1, R412.1, R420.1, R421.1, R422.1, R423.1, R424.1, R425.1, R426.2, U401.3 (3V3); also elsewhere on the board
+3V3_PG: R401.2, U401.45 (EN); also elsewhere on the board
/ESP32-S3/ESP32_RX: TP402.1, U401.40 (U0RXD/GPIO44)
/ESP32-S3/ESP32_SDIO_CLK: R416.2, U401.28 (GPIO33)
/ESP32-S3/ESP32_SDIO_CMD: R418.1, U401.27 (GPIO47)
/ESP32-S3/ESP32_SDIO_D0: R417.2, U401.29 (GPIO34)
/ESP32-S3/ESP32_SDIO_D1: R419.1, U401.30 (GPIO48)
/ESP32-S3/ESP32_SDIO_D2: R415.1, U401.25 (GPIO21)
/ESP32-S3/ESP32_SDIO_D3: R414.2, U401.26 (GPIO26)
/ESP32-S3/ESP32_SPI2_CLK: R410.1, U401.16 (GPIO12)
/ESP32-S3/ESP32_SPI2_D0: R409.1, U401.15 (GPIO11)
/ESP32-S3/ESP32_SPI2_D1: R411.1, U401.17 (GPIO13)
/ESP32-S3/ESP32_SPI2_D2: R413.1, U401.18 (GPIO14)
/ESP32-S3/ESP32_SPI2_D3: R408.1, U401.13 (GPIO9)
/ESP32-S3/ESP32_TX: TP401.1, U401.39 (U0TXD/GPIO43)
/ESP32-S3/ESP32_USB_D+: R402.1, U401.24 (GPIO20/USB_D+)
/ESP32-S3/ESP32_USB_D-: R406.1, U401.23 (GPIO19/USB_D-)
/ESP32-S3/SDIO_CLK: J402.5 (CLK), R416.1, R423.2
/ESP32-S3/SDIO_CMD: J402.3 (CMD), R418.2, R422.2
/ESP32-S3/SDIO_D0: J402.7 (DAT0), R417.1, R424.2
/ESP32-S3/SDIO_D1: J402.8 (DAT1), R419.2, R425.2
/ESP32-S3/SDIO_D2: J402.1 (DAT2), R415.2, R420.2
/ESP32-S3/SDIO_D3/~CS: J402.2 (DAT3/CD), R414.1, R421.2
/ESP32-S3/SD_Detect: R427.2, U401.31 (GPIO35)
/ESP32-S3/SD_Detect_s: J402.9 (DET), R426.1, R427.1
/ESP32-S3/STATUS_LED: Q401.1 (G), R412.2, U401.32 (GPIO36)
/ESP32-S3/Status_LED_A: D401.2 (A), R407.2
/ESP32-S3/Status_LED_K: D401.1 (K), Q401.3 (D)
BATT_CHG: U401.35 (GPIO39/MTCK); also elsewhere on the board
BTN_Home: U401.4 (GPIO0/BOOT); also elsewhere on the board
BTN_VOL_DOWN: U401.36 (GPIO40/MTDO); also elsewhere on the board
BTN_VOL_UP: U401.37 (GPIO41/MTDI); also elsewhere on the board
DAC_~RESET: U401.41 (GPIO45); also elsewhere on the board
FPGA_DONE: U401.10 (GPIO6); also elsewhere on the board
FPGA_INIT_B: U401.12 (GPIO8); also elsewhere on the board
FPGA_POWER_EN: U401.44 (GPIO46); also elsewhere on the board
FPGA_PROGRAM_B: U401.11 (GPIO7); also elsewhere on the board
FPGA_SPI_CLK: R410.2; also elsewhere on the board
FPGA_SPI_D0: R409.2; also elsewhere on the board
FPGA_SPI_D1: R411.2; also elsewhere on the board
FPGA_SPI_D2: R413.2; also elsewhere on the board
FPGA_SPI_D3: R408.2; also elsewhere on the board
FPGA_SPI_~CS: U401.14 (GPIO10); also elsewhere on the board
GND: C401.1, C402.2, C403.1, J401.4, J402.6 (VSS), J402.10 (SHIELD), Q401.2 (S), U401.1 (GND), U401.2 (GND), U401.42 (GND), U401.43 (GND), U401.46 (GND), U401.47 (GND), U401.48 (GND), U401.49 (GND), U401.50 (GND), U401.51 (GND), U401.52 (GND), U401.53 (GND), U401.54 (GND), U401.55 (GND), U401.56 (GND), U401.57 (GND), U401.58 (GND), U401.59 (GND), U401.60 (GND), U401.61 (GND), U401.62 (GND), U401.63 (GND), U401.64 (GND), U401.65 (GND); also elsewhere on the board
I2C0_SCL: J401.2, R404.2, U401.33 (GPIO37); also elsewhere on the board
I2C0_SDA: J401.3, R405.2, U401.34 (GPIO38); also elsewhere on the board
LCD_BACKLIGHT: U401.38 (GPIO42/MTMS); also elsewhere on the board
LCD_D/~CX: U401.7 (GPIO3); also elsewhere on the board
LCD_SPI_CLK: U401.8 (GPIO4); also elsewhere on the board
LCD_SPI_PICO: U401.9 (GPIO5); also elsewhere on the board
LCD_~CS: U401.6 (GPIO2); also elsewhere on the board
LCD_~RST: U401.5 (GPIO1); also elsewhere on the board
MCU_~IRQ: J401.1, R403.2, U401.20 (GPIO16); also elsewhere on the board
USB_D+: R402.2; also elsewhere on the board
USB_D-: R406.2; also elsewhere on the board
~POWER_SW: U401.19 (GPIO15); also elsewhere on the board
~VBUS_PGOOD: U401.21 (GPIO17); also elsewhere on the board

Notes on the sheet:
ESP32-S3 ~{IRQ} is open-drain
Power / Status LED
microSD Slot

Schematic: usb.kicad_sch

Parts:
D501, D502, D503: H5VU25U; Diodes_UDFN-10_1.0x2.5mm_P0.5mm; LCSC C7420374
J501: USB_C_Receptacle_USB2.0; USB-C-SMD_TYPE-C-24P-QT; LCSC C2681555
R501, R502: 5K1; R_0402_1005Metric; LCSC C25905

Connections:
/USB/USB_CC1: J501.A5 (CC1), R501.1
/USB/USB_CC2: J501.B5 (CC2), R502.1
GND: D501.3 (A), D501.8 (A), D502.3 (A), D502.8 (A), D503.3 (A), D503.8 (A), J501.A1 (GND), J501.A12 (GND), J501.B1 (GND), J501.B12 (GND), J501.S1 (SHIELD), R501.2, R502.2; also elsewhere on the board
HDMI_CLK+: D503.4 (K3), D503.7 (K3), J501.A10 (RX2-); also elsewhere on the board
HDMI_CLK-: D503.5 (K4), D503.6 (K4), J501.A11 (RX2+); also elsewhere on the board
HDMI_D0+: D502.2 (K2), D502.9 (K2), J501.B3 (TX2-); also elsewhere on the board
HDMI_D0-: D502.1 (K1), D502.10 (K1), J501.B2 (TX2+); also elsewhere on the board
HDMI_D1+: D503.1 (K1), D503.10 (K1), J501.A2 (TX1+); also elsewhere on the board
HDMI_D1-: D503.2 (K2), D503.9 (K2), J501.A3 (TX1-); also elsewhere on the board
HDMI_D2+: D502.5 (K4), D502.6 (K4), J501.B11 (RX1+); also elsewhere on the board
HDMI_D2-: D502.4 (K3), D502.7 (K3), J501.B10 (RX1-); also elsewhere on the board
USB_D+: D501.2 (K2), D501.9 (K2), J501.A6 (D+), J501.B6 (D+); also elsewhere on the board
USB_D-: D501.4 (K3), D501.7 (K3), J501.A7 (D-), J501.B7 (D-); also elsewhere on the board
USB_SBU1: D501.5 (K4), D501.6 (K4), J501.A8 (SBU1); also elsewhere on the board
USB_SBU2: D501.1 (K1), D501.10 (K1), J501.B8 (SBU2); also elsewhere on the board
VBUS: J501.A4 (VBUS), J501.A9 (VBUS), J501.B4 (VBUS), J501.B9 (VBUS); also elsewhere on the board

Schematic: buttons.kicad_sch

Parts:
C1601: 100n; C_0402_1005Metric; LCSC C1525
R1601, R1602, R1603, R1604, R1605, R1606, R1607, R1608, R1609, R1610, R1611, R1612, R1613, R1614, R1615, R1616, R1617, R1618, R1619, R1620, R1621, R1622, R1623, R1624, R1625, R1626, R1627, R1628, R1629, R1630: 10K; R_0402_1005Metric; LCSC C25744
SW1601: Up; SW_SPST_SKRR; LCSC C97437
SW1602: X; SW_SPST_SKRR; LCSC C97437
SW1603: Left; SW_SPST_SKRR; LCSC C97437
SW1604: Right; SW_SPST_SKRR; LCSC C97437
SW1605: Y; SW_SPST_SKRR; LCSC C97437
SW1606: A; SW_SPST_SKRR; LCSC C97437
SW1607: Down; SW_SPST_SKRR; LCSC C97437
SW1608: B; SW_SPST_SKRR; LCSC C97437
SW1609: Select; SW_SPST_SKRB; LCSC C115356
SW1610: Home; SW_SPST_SKRB; LCSC C115356
SW1611: Start; SW_SPST_SKRB; LCSC C115356
SW1612: L; SW_Tactile_SPST_PTS645Vxx13SMT
SW1613: R; SW_Tactile_SPST_PTS645Vxx13SMT
SW1614: Vol_Up; SW_SPST_SKSC; LCSC C115361
SW1615: Vol_Down; SW_SPST_SKSC; LCSC C115361
U1601: TCA9535PWR; TSSOP-24_4.4x7.8mm_P0.65mm; LCSC C130204

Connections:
+3V3: C1601.1, R1601.1, R1602.1, R1605.1, R1606.1, R1607.1, R1608.1, R1613.1, R1614.1, R1617.1, R1618.1, R1619.1, R1623.1, R1625.1, R1626.1, R1629.1, U1601.24 (VCC); also elsewhere on the board
/Buttons/BTN_A_s: R1608.2, R1612.2, SW1606.1
/Buttons/BTN_B_s: R1614.2, R1616.2, SW1608.1
/Buttons/BTN_Down_s: R1613.2, R1615.2, SW1607.1
/Buttons/BTN_Home_s: R1618.2, R1621.2, SW1610.1
/Buttons/BTN_L_s: R1623.2, R1624.2, SW1612.1
/Buttons/BTN_Left_s: R1605.2, R1609.2, SW1603.1
/Buttons/BTN_R_s: R1625.2, R1627.2, SW1613.1
/Buttons/BTN_Right_s: R1606.2, R1610.2, SW1604.1
/Buttons/BTN_Select_s: R1617.2, R1620.2, SW1609.1
/Buttons/BTN_Start_s: R1619.2, R1622.2, SW1611.1
/Buttons/BTN_Up_s: R1601.2, R1603.2, SW1601.1
/Buttons/BTN_Vol_Down_s: R1629.2, R1630.2, SW1615.1
/Buttons/BTN_Vol_Up_s: R1626.2, R1628.2, SW1614.1
/Buttons/BTN_X_s: R1602.2, R1604.2, SW1602.1
/Buttons/BTN_Y_s: R1607.2, R1611.2, SW1605.1
BTN_A: R1612.1, U1601.7 (P03); also elsewhere on the board
BTN_B: R1616.1, U1601.8 (P04); also elsewhere on the board
BTN_Down: R1615.1, U1601.18 (P15); also elsewhere on the board
BTN_Home: R1621.1; also elsewhere on the board
BTN_L: R1624.1, U1601.14 (P11); also elsewhere on the board
BTN_Left: R1609.1, U1601.17 (P14); also elsewhere on the board
BTN_R: R1627.1, U1601.4 (P00); also elsewhere on the board
BTN_Right: R1610.1, U1601.16 (P13); also elsewhere on the board
BTN_Select: R1620.1, U1601.19 (P16); also elsewhere on the board
BTN_Start: R1622.1, U1601.20 (P17); also elsewhere on the board
BTN_Up: R1603.1, U1601.15 (P12); also elsewhere on the board
BTN_VOL_DOWN: R1630.1; also elsewhere on the board
BTN_VOL_UP: R1628.1; also elsewhere on the board
BTN_X: R1604.1, U1601.5 (P01); also elsewhere on the board
BTN_Y: R1611.1, U1601.6 (P02); also elsewhere on the board
GND: C1601.2, SW1601.2, SW1602.2, SW1603.2, SW1604.2, SW1605.2, SW1606.2, SW1607.2, SW1608.2, SW1609.2, SW1610.2, SW1611.2, SW1612.2, SW1613.2, SW1614.2, SW1615.2, U1601.2 (A1), U1601.3 (A2), U1601.9 (P05), U1601.10 (P06), U1601.11 (P07), U1601.12 (GND), U1601.13 (P10), U1601.21 (A0); also elsewhere on the board
I2C0_SCL: U1601.22 (SCL); also elsewhere on the board
I2C0_SDA: U1601.23 (SDA); also elsewhere on the board
MCU_~IRQ: U1601.1 (~INT); also elsewhere on the board

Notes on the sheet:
Button I/O Expander (optional)
I2C Addr: 0x20

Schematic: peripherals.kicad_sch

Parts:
C1501, C1502, C1503, C1504: 100n; C_0402_1005Metric; LCSC C1525
C1505: 22p; C_0402_1005Metric_Pad0.74x0.62mm_HandSolder; LCSC C1555
D1501: 1N4148W; D_SOD-123; LCSC C81598
J1501: Vibration_Motor; Rumble_Motor_Pads
Q1501: AO3401A; SOT-23; LCSC C15127
Q1502: AO3400A; SOT-23; LCSC C20917
R1501, R1504: 10K; R_0402_1005Metric; LCSC C25744
R1502, R1503: 1K; R_0402_1005Metric; LCSC C11702
U1501: LSM6DS3TR-C; LGA-14_3x2.5mm_P0.5mm_LayoutBorder3x4y; LCSC C967633
U1502: PCF8563T; TSSOP-8_3x3mm_P0.65mm; LCSC C27397
Y1501: 32.768kHz; Crystal_SMD_3215-2Pin_3.2x1.5mm; LCSC C32346

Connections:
+3V3: C1501.1, C1502.2, C1503.2, D1501.1 (K), J1501.1, Q1501.2 (S), U1501.5 (VDDIO), U1501.8 (VDD), U1501.12 (CS); also elsewhere on the board
+3V3_FPGA: R1501.1; also elsewhere on the board
/Peripherals/RTC_INT: U1502.3 (~INT)
/Peripherals/RTC_OSCI: C1505.2, U1502.1 (OSCI), Y1501.1
/Peripherals/RTC_OSCO: U1502.2 (OSCO), Y1501.2
/Peripherals/Vibrate_FET_g: Q1502.1 (G), R1503.2
/Peripherals/Vibrate_N: C1503.1, D1501.2 (A), J1501.2, Q1501.3 (D), Q1502.3 (D)
/Peripherals/~Vibrate_Brake_g: Q1501.1 (G), R1502.2
GND: C1501.2, C1502.1, C1504.1, C1505.1, Q1502.2 (S), R1504.2, U1501.1 (SDO/SA0), U1501.2 (SDX), U1501.3 (SCX), U1501.6 (GND), U1501.7 (GND), U1502.4 (VSS); also elsewhere on the board
I2C0_SCL: U1501.13 (SCL), U1502.6 (SCL); also elsewhere on the board
I2C0_SDA: U1501.14 (SDA), U1502.5 (SDA); also elsewhere on the board
VSYS_ALWAYS: C1504.2, U1502.8 (VDD); also elsewhere on the board
Vibrate_En: R1503.1, R1504.1; also elsewhere on the board
~Vibrate_Brake: R1501.2, R1502.1; also elsewhere on the board

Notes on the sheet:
RTC
C = (XTAL_C - 2pF) * 2 C ~= 22 pF Honestly it's pretty much a guess
I2C Addr: 0x6A
I2C Addr: 0x51
IMU
See NXP UM10301 for oscillator info
Vibration

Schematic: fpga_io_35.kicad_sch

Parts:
C1201, C1202, C1203, C1204: 470n; C_0402_1005Metric; LCSC C47339
C1205, C1206: 4u7; C_0402_1005Metric; LCSC C23733
Q1201: AO3400A; SOT-23; LCSC C20917
R1201, R1202: 330R; R_0402_1005Metric; LCSC C25104
R1203: 10K; R_0402_1005Metric; LCSC C25744
U601: XC7A100T-CSG324; Xilinx_CSG324; LCSC C1521791

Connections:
+3V3_FPGA: C1201.1, C1202.1, C1203.1, C1204.1, C1205.1, C1206.1, U601.A7 (VCCO_35), U601.C3 (VCCO_35), U601.D6 (VCCO_35), U601.F2 (VCCO_35), U601.G5 (VCCO_35), U601.J1 (VCCO_35); also elsewhere on the board
/FPGA IO Bank 35/FPGA_IRQ: Q1201.1 (G), R1203.1, U601.J3 (IO_L22P_T3_35)
/FPGA IO Bank 35/USB_SBU_1: R1201.2, U601.F3 (IO_L13N_T2_MRCC_35)
/FPGA IO Bank 35/USB_SBU_2: R1202.2, U601.D3 (IO_L12N_T1_MRCC_35)
BTN_Down: U601.H5 (IO_L24N_T3_35); also elsewhere on the board
BTN_L: U601.E6 (IO_L5P_T0_AD13P_35); also elsewhere on the board
BTN_Left: U601.G6 (IO_L19P_T3_35); also elsewhere on the board
BTN_Right: U601.F5 (IO_0_35); also elsewhere on the board
BTN_Select: U601.J5 (IO_25_35); also elsewhere on the board
BTN_Up: U601.E5 (IO_L5N_T0_AD13N_35); also elsewhere on the board
DAC_BCLK: U601.G3 (IO_L20N_T3_35); also elsewhere on the board
DAC_DIN: U601.J4 (IO_L21P_T3_DQS_35); also elsewhere on the board
DAC_MCLK: U601.G4 (IO_L20P_T3_35); also elsewhere on the board
DAC_WCLK: U601.H4 (IO_L21N_T3_DQS_35); also elsewhere on the board
FPGA_CLK_50MHz: U601.E3 (IO_L12P_T1_MRCC_35); also elsewhere on the board
FPGA_SPI_CLK: U601.F4 (IO_L13P_T2_MRCC_35); also elsewhere on the board
FPGA_SPI_D0: U601.J2 (IO_L22N_T3_35); also elsewhere on the board
FPGA_SPI_D1: U601.H1 (IO_L17P_T2_35); also elsewhere on the board
FPGA_SPI_D2: U601.H2 (IO_L15P_T2_DQS_35); also elsewhere on the board
FPGA_SPI_D3: U601.K2 (IO_L23P_T3_35); also elsewhere on the board
FPGA_SPI_~CS: U601.K1 (IO_L23N_T3_35); also elsewhere on the board
GB_Cart_AD0: U601.B6 (IO_L2N_T0_AD12N_35); also elsewhere on the board
GB_Cart_AD1: U601.A6 (IO_L3P_T0_DQS_AD5P_35); also elsewhere on the board
GB_Cart_AD2: U601.B7 (IO_L2P_T0_AD12P_35); also elsewhere on the board
GB_Cart_AD3: U601.C4 (IO_L7P_T1_AD6P_35); also elsewhere on the board
GB_Cart_AD4: U601.D4 (IO_L11N_T1_SRCC_35); also elsewhere on the board
GB_Cart_AD5: U601.C5 (IO_L1N_T0_AD4N_35); also elsewhere on the board
GB_Cart_AD6: U601.D5 (IO_L11P_T1_SRCC_35); also elsewhere on the board
GB_Cart_AD7: U601.C6 (IO_L1P_T0_AD4P_35); also elsewhere on the board
GB_Cart_AD8: U601.D8 (IO_L4P_T0_35); also elsewhere on the board
GB_Cart_PHI: U601.B3 (IO_L10P_T1_AD15P_35); also elsewhere on the board
GB_Cart_~CS1: U601.A5 (IO_L3N_T0_DQS_AD5N_35); also elsewhere on the board
GB_Cart_~OE: U601.A3 (IO_L8N_T1_AD14N_35); also elsewhere on the board
GB_Cart_~RD: U601.B4 (IO_L7N_T1_AD6N_35); also elsewhere on the board
GB_Cart_~WR: U601.A4 (IO_L8P_T1_AD14P_35); also elsewhere on the board
GB_Dir_Cart1: U601.D7 (IO_L6N_T0_VREF_35); also elsewhere on the board
GB_Dir_Cart2: U601.C7 (IO_L4N_T0_35); also elsewhere on the board
GB_Dir_Cart3: U601.B2 (IO_L10N_T1_AD15N_35); also elsewhere on the board
GB_Dir_SC: U601.G1 (IO_L17N_T2_35); also elsewhere on the board
GB_Dir_SD: U601.F1 (IO_L18P_T2_35); also elsewhere on the board
GB_Dir_SI: U601.E1 (IO_L18N_T2_35); also elsewhere on the board
GB_Dir_SO: U601.C2 (IO_L16P_T2_35); also elsewhere on the board
GB_Link_SC: U601.G2 (IO_L15N_T2_DQS_35); also elsewhere on the board
GB_Link_SD: U601.E2 (IO_L14P_T2_SRCC_35); also elsewhere on the board
GB_Link_SI: U601.D2 (IO_L14N_T2_SRCC_35); also elsewhere on the board
GB_Link_SO: U601.C1 (IO_L16N_T2_35); also elsewhere on the board
GND: C1201.2, C1202.2, C1203.2, C1204.2, C1205.2, C1206.2, Q1201.2 (S), R1203.2; also elsewhere on the board
MCU_~IRQ: Q1201.3 (D); also elsewhere on the board
USB_SBU1: R1201.1; also elsewhere on the board
USB_SBU2: R1202.1; also elsewhere on the board
Vibrate_En: U601.B1 (IO_L9P_T1_DQS_AD7P_35); also elsewhere on the board
~Vibrate_Brake: U601.A1 (IO_L9N_T1_DQS_AD7N_35); also elsewhere on the board

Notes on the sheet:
Single-ended clock must go to P pin
IRQ

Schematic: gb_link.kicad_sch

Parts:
C1, C3, C4: 100p; C_0402_1005Metric; LCSC C1546
C2004, C2005, C2006, C2007, C2008, C2009, C2010, C2011: 100n; C_0402_1005Metric; LCSC C1525
D2001: H5VU25U; Diodes_UDFN-10_1.0x2.5mm_P0.5mm; LCSC C7420374
J2001: Link_Port; GameBoy_LinkPort_AGB_Horizontal
R2, R3, R4, R5: 330R; R_0402_1005Metric; LCSC C25104
R2005, R2006, R2007: 47K; R_0402_1005Metric; LCSC C25792
R2008: 30K; R_0402_1005Metric; LCSC C25776
U2001, U2002, U2003, U2004: 74LVC1T45; SOT-363_SC-70-6; LCSC C168855

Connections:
+3V3_FPGA: C2005.2, C2007.2, C2009.2, C2011.2, U2001.1 (VCCA), U2002.1 (VCCA), U2003.1 (VCCA), U2004.1 (VCCA); also elsewhere on the board
/Game Boy Interfaces/Game Boy Link/Link_SC: R2008.2, U2004.4 (B); also elsewhere on the board
/Game Boy Interfaces/Game Boy Link/Link_SC_a: D2001.5 (K4), D2001.6 (K4), J2001.5 (SC); also elsewhere on the board
/Game Boy Interfaces/Game Boy Link/Link_SD: R2006.2, U2002.4 (B); also elsewhere on the board
/Game Boy Interfaces/Game Boy Link/Link_SD_a: D2001.4 (K3), D2001.7 (K3), J2001.4 (SD); also elsewhere on the board
/Game Boy Interfaces/Game Boy Link/Link_SI: R2007.2, U2003.4 (B); also elsewhere on the board
/Game Boy Interfaces/Game Boy Link/Link_SI_a: D2001.2 (K2), D2001.9 (K2), J2001.3 (SI); also elsewhere on the board
/Game Boy Interfaces/Game Boy Link/Link_SO: R2005.2, U2001.4 (B); also elsewhere on the board
/Game Boy Interfaces/Game Boy Link/Link_SO_a: D2001.1 (K1), D2001.10 (K1), J2001.2 (SO); also elsewhere on the board
GB_Dir_SC: U2004.5 (DIR); also elsewhere on the board
GB_Dir_SD: U2002.5 (DIR); also elsewhere on the board
GB_Dir_SI: U2003.5 (DIR); also elsewhere on the board
GB_Dir_SO: U2001.5 (DIR); also elsewhere on the board
GB_Link_SC: U2004.3 (A); also elsewhere on the board
GB_Link_SD: U2002.3 (A); also elsewhere on the board
GB_Link_SI: U2003.3 (A); also elsewhere on the board
GB_Link_SO: U2001.3 (A); also elsewhere on the board
GND: C2004.1, C2005.1, C2006.1, C2007.1, C2008.1, C2009.1, C2010.1, C2011.1, D2001.3 (A), D2001.8 (A), J2001.6 (GND), J2001.SH, U2001.2 (GND), U2002.2 (GND), U2003.2 (GND), U2004.2 (GND); also elsewhere on the board
VGB: C2004.2, C2006.2, C2008.2, C2010.2, J2001.1 (VDD), R2005.1, R2006.1, R2007.1, R2008.1, U2001.6 (VCCB), U2002.6 (VCCB), U2003.6 (VCCB), U2004.6 (VCCB); also elsewhere on the board

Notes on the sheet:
For SC: 100K and 47K in parallel = ~32K

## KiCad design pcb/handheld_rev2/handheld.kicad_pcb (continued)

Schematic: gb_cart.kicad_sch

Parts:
C1901, C1902, C1903, C1904, C1905, C1906, C1907, C1908, C1909, C1910, C1911, C1912, C1913: 100n; C_0402_1005Metric; LCSC C1525
J1901: Cartridge_Slot; GameBoy_Cartridge_AGS_1x32-1MP_P1.50mm_Socket_Horizontal
R1901, R1902, R1905: 49R9; R_0402_1005Metric; LCSC C25120
R1903: 100K; R_0402_1005Metric; LCSC C25741
R1904: 27K; R_0603_1608Metric; LCSC C22967
U1901, U1903: 74LVC1T45; SOT-363_SC-70-6; LCSC C168855
U1902, U1904: 74LVCH16T245; TSSOP-48_6.1x12.5mm_P0.5mm; LCSC C352975

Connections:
+3V3_FPGA: C1903.2, C1904.2, C1906.2, C1909.2, C1912.2, C1913.2, R1903.1, U1901.1 (VCCA), U1902.31 (VCCA), U1902.42 (VCCA), U1903.1 (VCCA), U1904.31 (VCCA), U1904.42 (VCCA); also elsewhere on the board
/Game Boy Interfaces/Game Boy Cartridge/Cart_A16: J1901.22 (A16/D0), U1902.12 (1B8)
/Game Boy Interfaces/Game Boy Cartridge/Cart_A17: J1901.23 (A17/D1), U1902.11 (1B7)
/Game Boy Interfaces/Game Boy Cartridge/Cart_A18: J1901.24 (A18/D2), U1902.9 (1B6)
/Game Boy Interfaces/Game Boy Cartridge/Cart_A19: J1901.25 (A19/D3), U1902.8 (1B5)
/Game Boy Interfaces/Game Boy Cartridge/Cart_A20: J1901.26 (A20/D4), U1902.6 (1B4)
/Game Boy Interfaces/Game Boy Cartridge/Cart_A21: J1901.27 (A21/D5), U1902.5 (1B3)
/Game Boy Interfaces/Game Boy Cartridge/Cart_A22: J1901.28 (A22/D6), U1902.3 (1B2)
/Game Boy Interfaces/Game Boy Cartridge/Cart_A23: J1901.29 (A23/D7), U1902.2 (1B1)
/Game Boy Interfaces/Game Boy Cartridge/Cart_AD0: J1901.6 (AD0/A0), U1904.12 (1B8)
/Game Boy Interfaces/Game Boy Cartridge/Cart_AD1: J1901.7 (AD1/A1), U1904.11 (1B7)
/Game Boy Interfaces/Game Boy Cartridge/Cart_AD2: J1901.8 (AD2/A2), U1904.9 (1B6)
/Game Boy Interfaces/Game Boy Cartridge/Cart_AD3: J1901.9 (AD3/A3), U1904.8 (1B5)
/Game Boy Interfaces/Game Boy Cartridge/Cart_AD4: J1901.10 (AD4/A4), U1904.6 (1B4)
/Game Boy Interfaces/Game Boy Cartridge/Cart_AD5: J1901.11 (AD5/A5), U1904.5 (1B3)
/Game Boy Interfaces/Game Boy Cartridge/Cart_AD6: J1901.12 (AD6/A6), U1904.3 (1B2)
/Game Boy Interfaces/Game Boy Cartridge/Cart_AD7: J1901.13 (AD7/A7), U1904.2 (1B1)
/Game Boy Interfaces/Game Boy Cartridge/Cart_AD8: J1901.14 (AD8/A8), U1902.23 (2B8)
/Game Boy Interfaces/Game Boy Cartridge/Cart_AD9: J1901.15 (AD9/A9), U1902.22 (2B7)
/Game Boy Interfaces/Game Boy Cartridge/Cart_AD10: J1901.16 (AD10/A10), U1902.20 (2B6)
/Game Boy Interfaces/Game Boy Cartridge/Cart_AD11: J1901.17 (AD11/A11), U1902.19 (2B5)
/Game Boy Interfaces/Game Boy Cartridge/Cart_AD12: J1901.18 (AD12/A12), U1902.17 (2B4)
/Game Boy Interfaces/Game Boy Cartridge/Cart_AD13: J1901.19 (AD13/A13), U1902.16 (2B3)
/Game Boy Interfaces/Game Boy Cartridge/Cart_AD14: J1901.20 (AD14/A14), U1902.14 (2B2)
/Game Boy Interfaces/Game Boy Cartridge/Cart_AD15: J1901.21 (AD15/A15), U1902.13 (2B1)
/Game Boy Interfaces/Game Boy Cartridge/Cart_PHI: J1901.2 (PHI), U1904.17 (2B4)
/Game Boy Interfaces/Game Boy Cartridge/Cart_VIN: J1901.31 (~REQ/VIN), R1903.2, U1903.4 (B)
/Game Boy Interfaces/Game Boy Cartridge/Cart_~CS1: R1902.1, U1904.13 (2B1)
/Game Boy Interfaces/Game Boy Cartridge/Cart_~CS1_d: J1901.5 (~CS1/~CS), R1902.2
/Game Boy Interfaces/Game Boy Cartridge/Cart_~CS2: R1905.2, U1901.4 (B)
/Game Boy Interfaces/Game Boy Cartridge/Cart_~CS2_d: J1901.30 (~CS2/~RES), R1904.2, R1905.1
/Game Boy Interfaces/Game Boy Cartridge/Cart_~RD: J1901.4 (~RD), U1904.14 (2B2)
/Game Boy Interfaces/Game Boy Cartridge/Cart_~WR: R1901.2, U1904.16 (2B3)
/Game Boy Interfaces/Game Boy Cartridge/Cart_~WR_d: J1901.3 (~WR), R1901.1
GB_Cart_A16: U1902.37 (1A8); also elsewhere on the board
GB_Cart_A17: U1902.38 (1A7); also elsewhere on the board
GB_Cart_A18: U1902.40 (1A6); also elsewhere on the board
GB_Cart_A19: U1902.41 (1A5); also elsewhere on the board
GB_Cart_A20: U1902.43 (1A4); also elsewhere on the board
GB_Cart_A21: U1902.44 (1A3); also elsewhere on the board
GB_Cart_A22: U1902.46 (1A2); also elsewhere on the board
GB_Cart_A23: U1902.47 (1A1); also elsewhere on the board
GB_Cart_AD0: U1904.37 (1A8); also elsewhere on the board
GB_Cart_AD1: U1904.38 (1A7); also elsewhere on the board
GB_Cart_AD2: U1904.40 (1A6); also elsewhere on the board
GB_Cart_AD3: U1904.41 (1A5); also elsewhere on the board
GB_Cart_AD4: U1904.43 (1A4); also elsewhere on the board
GB_Cart_AD5: U1904.44 (1A3); also elsewhere on the board
GB_Cart_AD6: U1904.46 (1A2); also elsewhere on the board
GB_Cart_AD7: U1904.47 (1A1); also elsewhere on the board
GB_Cart_AD8: U1902.26 (2A8); also elsewhere on the board
GB_Cart_AD9: U1902.27 (2A7); also elsewhere on the board
GB_Cart_AD10: U1902.29 (2A6); also elsewhere on the board
GB_Cart_AD11: U1902.30 (2A5); also elsewhere on the board
GB_Cart_AD12: U1902.32 (2A4); also elsewhere on the board
GB_Cart_AD13: U1902.33 (2A3); also elsewhere on the board
GB_Cart_AD14: U1902.35 (2A2); also elsewhere on the board
GB_Cart_AD15: U1902.36 (2A1); also elsewhere on the board
GB_Cart_PHI: U1904.32 (2A4); also elsewhere on the board
GB_Cart_VIN: U1903.3 (A); also elsewhere on the board
GB_Cart_~CS1: U1904.36 (2A1); also elsewhere on the board
GB_Cart_~CS2: U1901.3 (A); also elsewhere on the board
GB_Cart_~OE: U1902.25 (2~OE), U1902.48 (1~OE), U1904.25 (2~OE), U1904.48 (1~OE); also elsewhere on the board
GB_Cart_~RD: U1904.35 (2A2); also elsewhere on the board
GB_Cart_~WR: U1904.33 (2A3); also elsewhere on the board
GB_Dir_Cart0: U1902.1 (1DIR); also elsewhere on the board
GB_Dir_Cart1: U1902.24 (2DIR); also elsewhere on the board
GB_Dir_Cart2: U1904.1 (1DIR); also elsewhere on the board
GB_Dir_Cart3: U1904.24 (2DIR); also elsewhere on the board
GB_Dir_VIN: U1903.5 (DIR); also elsewhere on the board
GB_Dir_~CS2: U1901.5 (DIR); also elsewhere on the board
GND: C1901.1, C1902.1, C1903.1, C1904.1, C1905.1, C1906.1, C1907.1, C1908.1, C1909.1, C1910.1, C1911.1, C1912.1, C1913.1, J1901.32 (GND), J1901.MP, U1901.2 (GND), U1902.4 (GND), U1902.10 (GND), U1902.15 (GND), U1902.21 (GND), U1902.28 (GND), U1902.34 (GND), U1902.39 (GND), U1902.45 (GND), U1903.2 (GND), U1904.4 (GND), U1904.10 (GND), U1904.15 (GND), U1904.19 (2B5), U1904.20 (2B6), U1904.21 (GND), U1904.22 (2B7), U1904.23 (2B8), U1904.26 (2A8), U1904.27 (2A7), U1904.28 (GND), U1904.29 (2A6), U1904.30 (2A5), U1904.34 (GND), U1904.39 (GND), U1904.45 (GND); also elsewhere on the board
VGB: C1901.2, C1902.2, C1905.2, C1907.2, C1908.2, C1910.2, C1911.2, J1901.1 (VDD), R1904.1, U1901.6 (VCCB), U1902.7 (VCCB), U1902.18 (VCCB), U1903.6 (VCCB), U1904.7 (VCCB), U1904.18 (VCCB); also elsewhere on the board

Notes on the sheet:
AGS uses 18K for CS2 pull-up
AGS uses 47Ω for WR/CS1 resistor
AGS uses 15Ω for CS2 limiter

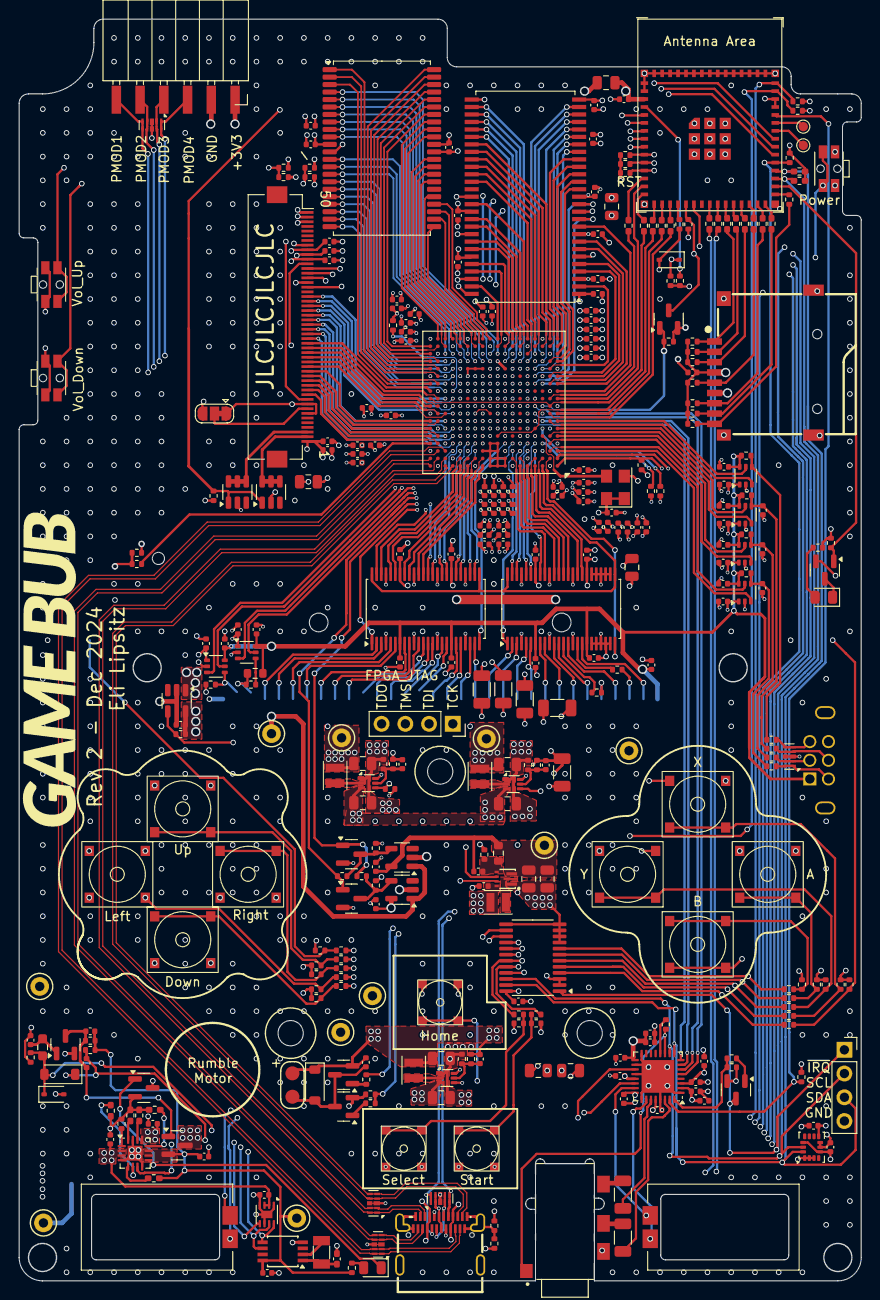
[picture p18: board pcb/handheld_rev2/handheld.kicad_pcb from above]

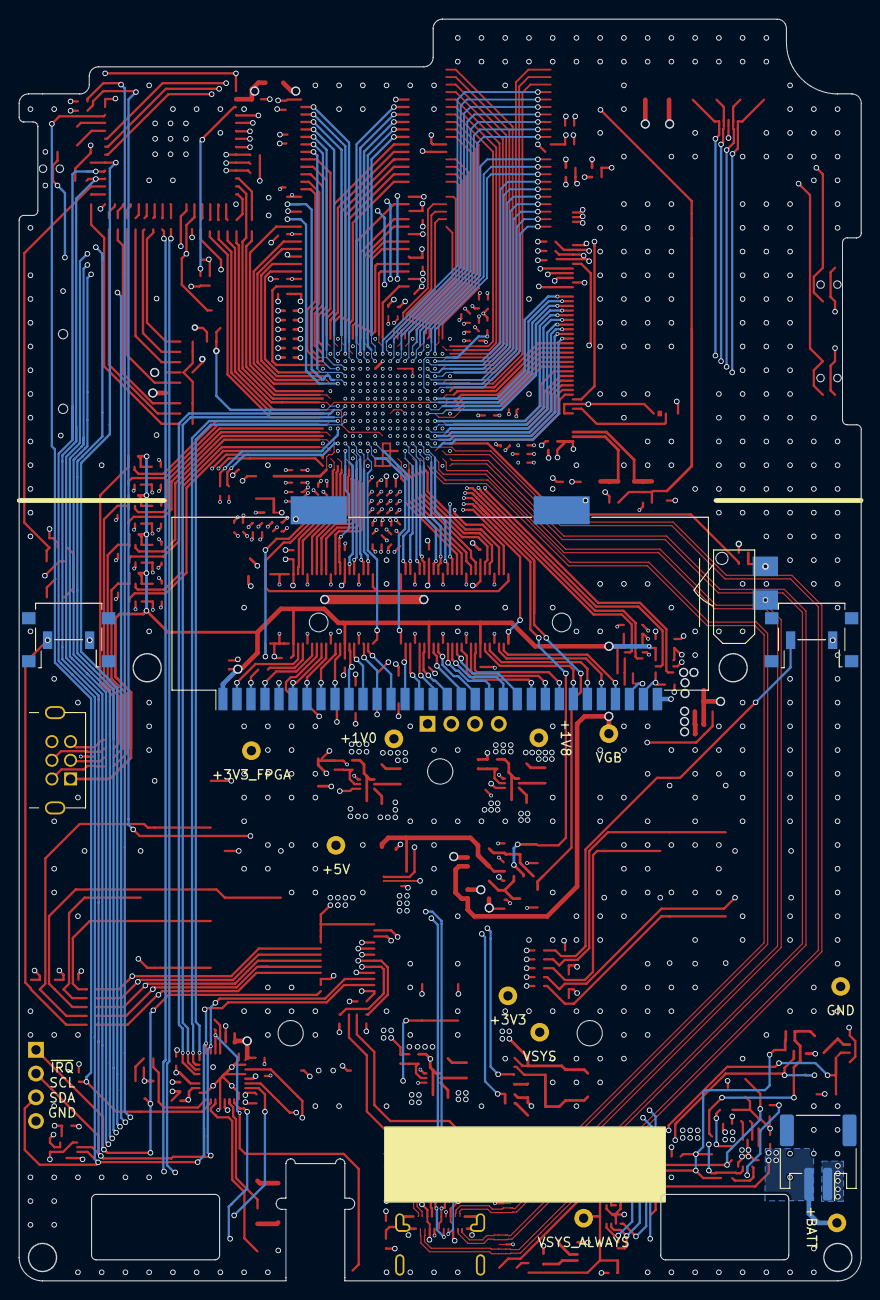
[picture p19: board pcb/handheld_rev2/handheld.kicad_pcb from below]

Board: 6 copper layers, 90.1 x 135.0 mm, 359 parts (6 on the bottom side), 360 nets.

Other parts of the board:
C2001, C2002, C2003: 100p; C_0402_1005Metric
R2001, R2002, R2003, R2004: 330R; R_0402_1005Metric

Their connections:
/Game Boy Interfaces/Game Boy Link/Link_SC: R2004.2; also elsewhere on the board
/Game Boy Interfaces/Game Boy Link/Link_SC_a: R2004.1; also elsewhere on the board
/Game Boy Interfaces/Game Boy Link/Link_SD: C2001.1, R2003.2; also elsewhere on the board
/Game Boy Interfaces/Game Boy Link/Link_SD_a: R2003.1; also elsewhere on the board
/Game Boy Interfaces/Game Boy Link/Link_SI: C2002.1, R2002.2; also elsewhere on the board
/Game Boy Interfaces/Game Boy Link/Link_SI_a: R2002.1; also elsewhere on the board
/Game Boy Interfaces/Game Boy Link/Link_SO: C2003.1, R2001.2; also elsewhere on the board
/Game Boy Interfaces/Game Boy Link/Link_SO_a: R2001.1; also elsewhere on the board
GND: C2001.2, C2002.2, C2003.2; also elsewhere on the board

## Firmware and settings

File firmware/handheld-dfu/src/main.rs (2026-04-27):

#![no_std]
#![no_main]
#![deny(
    clippy::mem_forget,
    reason = "mem::forget is generally not safe to do with esp_hal types, especially those \
    holding buffers for the duration of a data transfer."
)]
#![deny(clippy::large_stack_frames)]

use embassy_executor::Spawner;
use esp_hal::clock::CpuClock;
use esp_hal::gpio::{Input, InputConfig, Level, Output, OutputConfig, Pull};
use esp_hal::interrupt::software::SoftwareInterruptControl;
use esp_hal::otg_fs::Usb;
use esp_hal::timer::timg::TimerGroup;
use log::info;
use static_cell::StaticCell;

use crate::flash::Flash;
use crate::protocol::Protocol;
use crate::virtual_disk::Uf2VirtualDisk;

mod flash;
mod info;
mod led;
mod protocol;
mod reboot;
mod uf2;
mod usb;
mod usb_class;
mod virtual_disk;

#[panic_handler]
fn panic(_: &core::panic::PanicInfo) -> ! {
    loop {}
}

extern crate alloc;

// Application descriptor for esp-idf bootloader.
esp_bootloader_esp_idf::esp_app_desc!();

static PROTOCOL: StaticCell<Protocol> = StaticCell::new();
static FLASH: StaticCell<Flash> = StaticCell::new();
static VIRTUAL_DISK: StaticCell<Uf2VirtualDisk> = StaticCell::new();

#[allow(
    clippy::large_stack_frames,
    reason = "it's not unusual to allocate larger buffers etc. in main"
)]
#[esp_rtos::main]
async fn main(spawner: Spawner) {
    esp_println::logger::init_logger_from_env();

    let config = esp_hal::Config::default().with_cpu_clock(CpuClock::max());
    let peripherals = esp_hal::init(config);

    esp_alloc::heap_allocator!(#[esp_hal::ram(reclaimed)] size: 73744);

    let sw_int = SoftwareInterruptControl::new(peripherals.SW_INTERRUPT);
    let timg0 = TimerGroup::new(peripherals.TIMG0);
    esp_rtos::start(timg0.timer0, sw_int.software_interrupt0);

    info!("Game Bub DFU");

    let led = Output::new(peripherals.GPIO42, Level::Low, OutputConfig::default());
    spawner.spawn(led::blink_task(led).unwrap());

    let button_dfu = {
        let config = InputConfig::default().with_pull(Pull::Up);
        Input::new(peripherals.GPIO1, config)
    };
    let manual_dfu = button_dfu.is_low();

    spawner.spawn(reboot::task().unwrap());

    let flash = FLASH.init_with(|| Flash::new(peripherals.FLASH));

    // Load app descriptor of the actual firmware image
    let fw_meta = info::read_fw_metadata(flash);

    let protocol = PROTOCOL.init(Protocol::new(flash));
    let virtual_disk = VIRTUAL_DISK.init(Uf2VirtualDisk::new(flash));

    let usb = Usb::new(peripherals.USB0, peripherals.GPIO20, peripherals.GPIO19);
    usb::setup_usb(
        spawner.clone(),
        usb,
        protocol,
        fw_meta,
        if manual_dfu { Some(virtual_disk) } else { None },
    );
}

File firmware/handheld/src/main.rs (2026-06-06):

use anyhow::Context;

use device::Device;

use crate::{
    device::drivers::{fpga, usb},
    ui::UI,
};

mod bitstream;
mod cart_backup;
mod control;
mod device;
mod fwinfo;
mod hwinfo;
mod input;
mod kvs;
mod led;
mod power;
pub mod ui;
mod util;
mod worker;

enum StartupAction {
    MainMenu,
    RunCartridge,
}

fn get_startup_action() -> StartupAction {
    match kvs::keys::STARTUP_ACTION.get() {
        Some(1) => StartupAction::RunCartridge,
        _ => StartupAction::MainMenu,
    }
}

fn main() -> anyhow::Result<()> {
    esp_idf_svc::sys::link_patches();
    esp_idf_svc::log::EspLogger::initialize_default();
    esp_idf_svc::log::set_target_level("gpio", log::LevelFilter::Warn).unwrap();

    if let Err(e) = usb::configure_usb(usb::UsbMode::ConsoleOnly) {
        log::error!("USB setup failed: {:?}", e);
    }

    log::info!("Hardware version: {}", hwinfo::get_hardware_version());
    log::info!("Serial: {}", hwinfo::get_serial_number());
    kvs::Kvs::init()?;

    // Check that the firmware is compatible with the listed revision.
    cfg_if::cfg_if! {
        if #[cfg(feature = "rev1")] {
            let required_revision = 1;
        } else if #[cfg(feature = "rev2")] {
            let required_revision = 2;
        } else if #[cfg(feature = "rev3")] {
            let required_revision = 3;
        } else if #[cfg(feature = "rev4")] {
            let required_revision = 4;
        } else {
            compile_error!("No board revision selected");
        }
    };
    let actual_revision = hwinfo::get_hardware_version().major;
    if actual_revision != required_revision && actual_revision != 0 && actual_revision != 255 {
        anyhow::bail!(
            "Incompatible firmware revision: device={:?} firmware={}",
            actual_revision,
            required_revision
        );
    }

    // Proceed to initialize device.
    Device::init()?;
    let mut device = Device::lock();
    if device.sdcard.is_none() {
        log::warn!("Failed to mount SD card");
    }
    device.set_brightness(kvs::keys::BRIGHTNESS.get().unwrap());

    // Setup workers.
    worker::start();
    power::PowerManager::start(&mut device);

    // Initial programming FPGA
    fn program_fpga(device: &mut Device) -> anyhow::Result<()> {
        bitstream::program_boot(device)?;
        device.fpga.enable_interrupt(fpga::Irq::Button)?;
        device.lcd.enable_fpga_control()?;
        Ok(())
    }

    match get_startup_action() {
        StartupAction::RunCartridge => worker::send(worker::Message::RunCartridge),
        StartupAction::MainMenu => program_fpga(&mut device).context("Failed to program FPGA")?,
    }

    // Setup UI
    let mut ui = UI::new(&mut device);
    std::mem::drop(device);

    // Run UI in this thread.
    if let StartupAction::MainMenu = get_startup_action() {
        led::LedController::set_behavior(led::LedBehavior::OFF);
    }
    ui.run();
}

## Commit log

2023-11-11 Initial commit of handheld schematic
    [audio.kicad_sch, buttons.kicad_sch, esp32.kicad_sch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]
2024-01-08 Rev A of PCB
    [audio.kicad_sch, buttons.kicad_sch, esp32.kicad_sch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]
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2024-01-20 Add basic MAX17048 driver, drive display direct from FPGA
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2024-01-21 pcb: handheld: Adjust some silkscreen
    [handheld.kicad_pcb]
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2024-02-04 Switch submodule reset and enable polarities (default to reset and disable)
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2024-02-11 Add Gameboy cart stall stats registers
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2024-02-14 Try out using a much faster SPI receiver clock (always running, for now)
2024-02-15 Power down SPI clock PLL when chip isn't selected
2024-02-15 Don't put SPI PLL to sleep until after request FIFO is drained
2024-02-15 Add IRQs to volume up/down, home, power buttons
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2024-02-15 Change pmod debug output to provide spi read/write info
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2024-02-16 Store colors as UInt within framebuffer memories
    Chisel (at least 3.6.0), turns memories of bundles into a separate
    memory array for each element of the bundle, which complicates
    synthesis. So, just convert to/from UInt when storing the colors.
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2024-02-17 Add simple, flawed way to mute/unmute with volume_down button
2024-02-17 Change vblank interrupt to latch on rising edge
2024-02-18 Reorganize all fpga files under top-level /fpga/ directory
    [microcode.csv]
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2024-02-22 Move most hardware interaction into a Device struct
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2024-02-28 Switch alpha value in overlay color to be 1 for opaque
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2024-03-21 Fix incorrect key repeat on action buttons in menus
    [main.rs, mod.rs]
2024-03-21 pynq-z2: Switch to 720x480 HDMI output at 3x scale
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2024-03-23 Simplify Gameboy driver with new reset behavior
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2024-03-28 Switch to partial line based rendering
    Initial full-screen render went from 105ms to 120ms,
    but incremental renders had a minimum of 45ms for display,
    and can now be closer to 25ms *total*.
    Also makes it easier to later add 2x DPI rendering.
2024-03-29 ui: Add power off button to main menu
2024-03-29 Add power menu (dialog uses internal focus APIs)
2024-03-29 Update partition table, add NVS partition and increase factory image size to 2M
    [partitions.csv]
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2024-04-14 firmware: Update battery level as it changes via fuel gauge irq
2024-04-14 fpga: Fix CpuSpec test with Clocker
    interrupt_test 6 is still failing though
2024-04-15 fpga: Switch from read/write to enable/write for MemoryInterface
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2024-04-26 gba: Implement and test ARM swap
2024-04-27 gba: implement ARM branch/branch-link, rework pipeline flush
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2024-04-27 arm: Change pipeline flush to not rely on magic instructions
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2024-06-14 gba: Work towards fixing DMA
2024-06-15 gba: Fix 16-bit DMA
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2024-07-01 fpga: Fix top line getting cut off from framebuffer in HandheldTop
2024-07-04 gba: Add more logging and reset timer counter
2024-07-04 gba: Fix boot animation skip stub
    The goal is to run SWI 1 (RegisterRamReset) to clear memory and
    registers, and then SWI 0 (SoftReset) to clear the last bit of BIOS
    state and restart.
    However, a SWI call from ARM must actually shift the syscall number by
    16, because the BIOS SWI handler always looks at the second-highest byte
    (the lowest byte for a THUMB SWI, the 3rd byte for an ARM SWI).
    This fixes it, where previously it only called SWI 0 (never SWI 1)
    because the first syscall encoded 0 in the 3rd byte.
    'InitSystemStack', which sets up the stack pointer, must be called
    before the syscalls can be invoked.
2024-07-07 gba: Fix timer enable not reloading counter if tick happens too
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2024-07-16 gba: Align all writes to r15 to 2, even in ARM mode
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2024-07-16 fpga: sim: Switch to lossless recording format
    The old format was regular H.264 with AAC audio in an MP4 container.
    The new one is lossless, RGB H.264, with FLAC audio, in an MKV
    container.
    The new format is readable by FFMPEG, VLC, mpv, etc, but not by
    QuickTime (or macOS QuickLook). But it can be easily converted if
    needed.
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2024-07-18 firmware: Start allowing bitstream swapping
    [fpga.rs, main.rs, mod.rs]
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2024-07-27 gba: Improve EwramController latency, stall if not complete
2024-07-28 fpga: Add cache in front of SDRAM for HandheldGba
    This adds a direct-mapped, 1024-entry (32-bit) cache in front of SDRAM,
    for the EmulatedCartridge in HandheldGba. It greatly reduces the number
    of emulated cartridge stalls, making a huge different for game run
    speed.
2024-07-30 gba: Fix cartridge DMA not being a single burst
    This commit fixes the CartridgeController -- with the previous fix, DMA
    accesses to the cartridge were not a single burst access. This broke
    EEPROM access (and was of course, wrong).
    The reason for this is that with the previous fix, a burst ends when
    there's a non-sequential request, or a request to any other target.
    However, DMA on the GBA maintains the burst for the entire DMA access --
    this works fine when only one of the sides is the cartridge.
    The way I suspect it does this is that the cartridge controller keeps a
    burst active until it gets a non-sequential access *anywhere*, and the
    DMA controller just keeps doing sequential accesses a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
2024-08-08 gba: Fix EmulatedCartridge handling of ROM request aborts
    With cartridge prefetch, the cartridge controller now has a way to
    "abort" the current cartridge access. This just immediately sets the
    nCS/nCS2 lines high and switches back to the idle state.
    This works perfectly fine on a real cartridge, or on the
    VerificationEmulatedCartridge (which only uses the real lines).
    However, it's broken on an EmulatedCartridge, since it's using the
    reqStart/end signals, and it doesn't support starting a new request
    while the current one is busy (i.e. aborting).
    This required some additional logic to support. It wastes time, because
    we can't actually abort a memory request on the underlying controller
    (S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
2024-08-08 gba: Fix EmulatedCartridge io.stall when aborting
    Previously, EmulatedCartridge io.stall was incorrect when a request was
    aborted: io.stall would be false when the original request finished and
    we're about to submit the new request. This would cause the cartridge
    controller to read the wrong data (again)
2024-08-09 gba: Improve prefetch timing, avoid 2 cycle penalty
    This commit fixes a bug that was imposing a 2 cycle penalty on certain
    accesses when prefetch was enabled. After a request to the halfword that
    prefetch was currently prefetching, the controller would always go into
    the next prefetch, even if a request that would abort it was pending.
    This would then cause two cycles to abort the request and start it, as
    opposed to starting the request right when the previous ended.
    Now passing 1430/2020 mGBA timing tests
2024-08-10 gba: Fix prefetch buffer flush and continue
    There are some cases where the prefetch buffer is flushed, but prefetch
    continues (specifically when requesting a halfword that's currently
    being prefetched). This is a pretty common case.
    In this case, the prefetch buffer needs to be flushed, because anything
    left in the buffer came before the current request. However, prefetch
    continues. Previously, the register holding the address of the first
    word in the prefetch buffer was incorrect (not updated after the flush),
    which meant that subsequent accesses would fail to load the data in the
    prefetch buffer.
    This should fix the AGS Aging Test prefetch timing test.
    mGBA suite now at 1510/2020
    Also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
2024-08-11 gba: Don't allow DMA channel to be preempted during the store phase
    Needed for the last DMA aging test (priority)
2024-08-11 gba: Only composite objects if enabled
    Fixes a case where object data is left in the buffer when objects are
    disabled at a specific time, causing a row of object data to be repeated
    down the entire screen.
2024-08-13 gba: Fix incorrect request address in EmuCart during abort
    The "reqAddress" signal from the cartridge controller is only valid when
    "reqStart" is true. So, if we get a cartridge rom request abort, we need
    to register that address right then, because when we actually start the
    next rom request, the address will not be valid anymore.
    Fixes some issues when there are a lot of cartridge stalls, hopefully
    fixes the random crashes that sometimes happen on the physical handheld.
2024-08-15 gba: Don't disable DMA 3 during ppu stopvideo trigger unless that's the start control
2024-08-16 gba: Print run rate (inverse of stalls) on each pause, clear each time
    [mod.rs]
2024-08-16 gba: Fix firmware treatment of accelerometer, doesn't use GPIO
    [mod.rs]
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2024-08-20 firmware: Bypass LCD memory when writing from FPGA
    The previous config was needed to work with the GBA bitstreams. After
    changing the DPI driver on the FPGA to output DPI control signals
    directly from registers (rather from logic), bypassing GRAM works again.
    Presumably, the logic output from the DPI driver had some glitches in
    it, or otherwise didn't quite meet the timing requirements. Perhaps this
    was made a problem when more of the FPGA's resources were utilized with
    the larger GBA logic (compared to CGB).
2024-08-24 firmware: Expose SD card as USB MSC when requested
    Limitations: even after resetting, the device won't appear again as a
    USB Serial/JTAG, which makes reflashing a bit annoying. You have to
    actually power off and back on the device.
    [mod.rs, sdcard.rs]
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2024-08-30 firmware: Move emulated/physical cartridge loading to worker thread
    This commit moves the loading of physical, and especially emulated
    cartridges to a background worker thread, allowing the UI thread to
    remain unblocked and continue redrawing. The GBA/Gameboy bitstream
    drivers have been changed to not hold the Device lock for the entire
    duration of the loading, to allow the UI to respond to button presses,
    etc. and remain responsive.
    Redrawing still needs some work, Slint doesn't realize the entire screen
    needs to be redrawn when switching bitstreams.
    [mod.rs]
2024-09-02 firmware: Add reboot option to power menu
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2024-09-30 fpga: Only do spi request if no request fifo overflow happened this transaction
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2024-09-30 fpga: Add HDMI output support to HandheldTop
    This allows switching between HDMI output and the internal display (over
    DPI).
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2024-09-30 fpga: Re-work handling of triple framebuffering
    This centralizes all handling of the framebuffer indices in a single
    clock domain (the main system clock domain).
    This fixes a very rare issue where, because of how the "read index" was
    handled in the AV clock domain and synchronized into the system domain,
    the indexes could get out of sync, leading to one of the three frames
    never being written to (a flickering black frame).
    I only noticed this issue once, in the GB when switching between HDMI
    and internal display out.
    This also adds a new "skipped frames" stat counter.
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2024-09-30 fpga: Update read buffer index at beginning of read, not end
    Theoretically this gives a little bit more time (the vblank time) for
    the writer to produce a new frame that gets consumed.
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2024-10-25 fpga: Enable cartridge power even if cartridge isn't enabled
    Cartridge power also powers the link port (and the level shifters) --
    without this, the link port won't work for emulated cartridge
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2024-10-27 firmware: Adjust DAC settings to avoid clipping
    [dac.rs]
2024-11-02 gb: Fix Serial functionality (with external clock)
    The Serial functionality previously didn't actually work. The key issue
    is that the shift circuitry is only supposed to be active when "enable"
    in SC is true, even with external clock (slave) setting.
    Link now seems to work reliably (every time), whereas before it almost
    never worked, and even when it did, it sort of failed at some point.
    Separately, this commit also adds a double-flip-flop synchronizer for
    the two serial input signals (although that almost certainly was not the
    problem).
2024-11-10 firmware: Reset DAC before reboot
    [mod.rs]
2024-11-13 firmware: Add skip bios into settings
    [mod.rs]
2024-11-18 firmware: Add rom list error box
    [mod.rs]
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2024-11-21 firmware: Use quad SPI to talk to FPGA for faster transfer speeds
    Different parts of the system can only be talked to at certain speeds
    (based on the clock speed of the system). E.g. SDRAM runs at a certain
    speed, SRAM runs at a certain speed. Since SPI has no backpressure, the
    clock speed has to be limited to not overflow FIFOs and lose data (or
    read garbage).
    Also, the FPGA can only support up to ~16MHz clock for read (based on
    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
2024-11-25 firmware: Add fatal error screen
    [main.rs, mod.rs]
2024-11-25 firmware: Show fatal error if unable to program FPGA at boot
    [main.rs, mod.rs]
2024-11-25 firmware: Show error if unable to mount sd card
    [main.rs]
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2024-12-29 fpga: Rework fusesoc core, support handheld board revisions
2024-12-31 firmware: Set 8MB flash size to match rev2
    Rev 1 used an ESP32-S3-WROOM-N16, which has a 16MB flash size. Rev 2
    (and presumably revisions after) switched to ESP32-S3-MINI-1-N8, which
    only has an 8MB flash. Since we weren't using more than 8MB in the first
    place, just switch all builds to use an 8MB flash size.
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2025-01-02 pcb: Add handheld_rev2 and dock_rev1
    [audio.kicad_sch, buttons.kicad_sch, dock_rev1.kicad_pcb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]
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2025-01-03 firmware: fuel_gauge: fix charge rate reading
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2025-01-29 firmware: Fix alternate system paths for gba/gameboy bitstreams
    [mod.rs]
2025-02-01 firmware: Fix I2C error in rev2 after software reboot
    [dac.rs, mod.rs]
2025-02-01 fpga: Fix rev2 interrupt polarity
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2025-02-01 firmware: Ensure FPGA is ready after power-on-reset before program
    [fpga.rs, mod.rs]
2025-02-01 firmware: Improve boot by 340ms by switching to faster bootloader
    This bootloader was compiled with a log level of "none", and image
    validation skipped.
2025-02-08 Add STL files in 3d/
    [DpadButton.stl, ExtButtonArray.stl, FaceButtonArray.stl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]
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2025-02-16 gb: Fix mbc7: rom/ram/accelerometer
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2025-03-13 ela: Fix log stride with non-POT words per sample
2025-03-15 firmware: Fix lost write data from buffers being too small in CLI
    [mod.rs]
2025-03-17 firmware: add debug stall rate to gameboy
2025-03-17 fpga: Fix spurious GB module vblank transitions when stalls occur
2025-03-17 fpga: Remove SdramCache from HandheldGba
    This greatly reduces performance (increases stalls), however, it paves
    the way for some sdram controller improvements (and makes it easier to
    debug, because there's no cache affecting the behavior).
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2025-04-05 firmware: Don't send button update to UI if the state hasn't changed
2025-04-08 firmware: Add system_data partition
    [partitions.csv]
2025-04-08 firmware: Update to esp-idf v5.4.1
    To fix https://github.com/espressif/esp-idf/issues/15328
    And de-init SDMMC with single-slot deinit function
    [sdcard.rs]
2025-04-08 firmware: Make sdcard mount fail non-fatal
    [main.rs]
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2025-04-11 firmware: Stop handling input events in worker thread
    The worker thread has the lowest priority (lower than the UI thread). If
    UI rendering is taking a long time (e.g. when navigating through a
    list), the UI thread won't yield, and will starve the worker thread.
    Normally this is fine and expected, but if the worker thread is also
    responsible for sending the input updates, we can get stuck in a
    situation where the UI is stuck in a loop (button being held down), and
    we can't exit because the event that would stop it is stuck in the
    worker queue.
    So, pass input related events directly to UI thread, not the worker
    thread. Which logically makes sense anyway.
    Still some cleanup that needs to ha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
    [interrupt.rs, mod.rs]
2025-04-11 fpga: Don't hardcode color correction matrix, expose via SPI interface
2025-04-11 handheld: Implement color corrections
    [fpga.rs, mod.rs]
2025-04-11 firmware: Add GBA/CGB color corrections to settings
    [mod.rs]
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2025-04-20 fpga: Switch internal display to variable refresh, eliminate stutter and a framebuffer
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2025-04-27 fpga: Rework CartridgeUtility RAM waits
    [cart_backup.rs]
2025-05-13 firmware: Implement CartrigeUtility MBC reset and PHI toggle
    [cart_backup.rs]
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2025-05-14 firmware: Sleep display when reprogramming fpga to avoid artifacts
    [mod.rs]
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2025-07-16 firmware: Fix bq27427 fuel gauge I2C comms
    [mod.rs]
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2025-07-24 firmware: Don't crash if .sav doesn't exist
    [mod.rs]
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2025-08-10 firmware: Ensure boot bitstream after rom load error
    [mod.rs]
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2025-08-14 fpga: Add button filter to avoid phantom button presses in overlay menu
2025-10-19 firmware: Switch font to Faraway wide
    Excluded from repo for licensing reasons
2025-10-19 firmware: Fix AGB_CART_READ_EEPROM read wait states
    [cart_backup.rs]
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2025-10-19 firmware: Add more device init error context
    [mod.rs]
2025-12-18 fpga: Fix rev3 hdmi_clk_n pin assignment
    This was using the wrong pin (it's a GND pin), but interestingly it
    didn't actually matter. Vivado just picked the right one, presumably
    because it's used in a differential pair, and it just uses the proper
    differential (-) pin for the (+) pin (which was correct).
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2026-01-24 firmware: Skip bitstream compat check if hwinfo missing
    [mod.rs]
2026-01-24 fpga: Add vibrate brake
2026-01-27 firmware: Add reboot command to control interface
    [mod.rs, usb_tool.py]
2026-01-27 firmware: Fix crash when switching USB mode from OTG to OTG
    [mod.rs]
2026-02-06 firmware: Allow reboot into DFU mode
    [mod.rs, usb_tool.py]
2026-02-09 firmware: Don't panic if FPGA program fails
    [main.rs]
2026-02-19 firmware: Add bootloader with DFU app support
    Built from 093a742f0c40a74e1875ccb2db10dad3d4bdcfe6
    [partitions.csv]
2026-02-19 firmware: Resize partitions to take up entire flash
    [partitions.csv]
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2026-02-23 fpga: Use separate MMCM for HDMI clock
    Previously this was just part of the same system MMCM output. Two
    problems with this:
    * due to all the other clocks that needed to be generated, the HDMI
    clock was ~0.7% off from what it was supposed to be (maybe causing
    issues on some sinks?)
    * it would be difficult to do dynamic clock reconfiguration, which is
    likely going to be needed in the future
    Running the second MMCM has a power impact of ~120 mW, so the powerdown
    input is used to turn if off when not docked.
2026-02-24 fpga: Feed AV BUFGMUX the HDMI clock from a BUFH
    This seems to be required in revision 4, because Vivado is placing the
    MMCMs on two different sides of the chip (top/bottom), probably because
    the 50mhz input clock pin region changed.
    It doesn't seem to have any ill effect. Without this, Vivado would
    error during implementation:
    > Sub-optimal placement for a BUFG-BUFG cascade pair.
    >
    > Clock Rule: rule_cascaded_bufg
    > Rule Description: Cascaded bufg (bufg->bufg) must be adjacent and cyclic
    >
    > clk_wiz_hdmi/clkout1_buf (BUFG.O) is provisionally placed by clockplacer on BUFGCTRL_X0Y16
    >
    > bufgmux_av (BUFGCTRL.I1) is provisionally placed by clockplacer on BUFGCTRL_X0Y1
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2026-02-25 firmware: Use EspTimerService, not worker to defer control requests
    Previously, the REBOOT, REBOOT_DFU, and ENABLE_DEBUG requests relied on
    deferring to the background worker (so that the USB message could
    complete without error). However, this relies on the worker thread being
    initialized, which doesn't happen if there's an early boot crash.
    [mod.rs]
2026-03-08 fpga: Keep HDMI MMCM powered for a few cycles after undock
    This prevents an issue with BUFGMUX_CTRL: it is designed to produce
    glitchless output, but to do this it has synchronization logic that
    requires both clocks to be running before, during, and after a switch.
    With the change to put the HDMI clock on a separate MMCM, and power it
    down when not docked (for power savings), this sometimes led to a
    situation where the HDMI clock turned off too quickly, preventing the
    BUFGMUX_CTRL from properly synchronizing, and the output clock_av was
    always held low.
    The fix is to just keep the clock running for a few more (system) cycles
    before turning it off.
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2026-03-26 firmware: Update GBA game DB
    This adds additional games with special hardware. The Classic NES Series
    Super Mario Bros. is removed, it doesn't have special hardware and the
    EEPROM save is properly autodetected.
    [mod.rs]
2026-03-29 firmware: Load rom during Game screen
    The Rom select screen uses a lot of memory due to the UI. The Game
    screen, hopefully, uses less memory.
    A few weird things due to error handling.
    [mod.rs]
2026-03-29 firmware: Rewrite BackgroundReader to avoid using heap allocations
    [mod.rs]
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2026-04-27 dfu: Update esp-hal and esp-storage
    Primarily to get esp-storage 0.9.0, which includes the block erase fix
    (speeds up erase by 3-4x)
    [partitions.csv]
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2026-05-14 firmware: Switch cartridge backup to use soft RISC-V core running LK firmware
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2026-06-29 Remove pcb and 3d directories (moved to hardware repo)
    [DpadButton.stl, ExtButtonArray.stl, FaceButtonArray.stl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]
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2026-08-17 fpga: Replace FuseSoC with Edalize script wrappers
2026-08-17 fpga: Try avoiding shortened V_Active on ILI9806E
    The ILI9806E has an issue with shortening the V_Active period by
    immediately going to a vblank (causes frame corruption).
    This causes a problem when the core stops sending new frames, and then
    starts while we're in the middle of a keep-alive frame.
    This change just waits until the next Vsync period before switching
    over, at the expense of adding some tearing for a little while after
    while we catch up.
2026-08-26 firmware: Use heatshrink instead of gzip for bitstreams
    Previously, the built-in bitstreams were compressed using gzip. However,
    the flate2 / miniz_oxide implementation of decompression use a
    significant amount of additional memory (a ~44 KB heap allocation).
    This could theoretically be reduced by using a smaller gzip window size,
    but miniz_oxide doesn't support it.
    Instead, this commit switches to the heatshrink compression algorithm,
    designed for microcontrollers. This doesn't compress as well, but it can
    use a very small amount of memory to decompress.
    Some numbers:
    gzip:
    * 687ms to decompress/program boot
    * ~44KB of heap usage
    * 1234 KB compressed boot/gb/gba
    heatshrink (M=9, L=6):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
    [mod.rs]
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
